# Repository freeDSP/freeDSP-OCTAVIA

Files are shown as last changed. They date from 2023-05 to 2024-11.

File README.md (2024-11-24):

# freeDSP-OCTAVIA
8ch Output ADAU1452/1466 DSP Board with Analog/COAX/OPT/USB/Raspberry-Pi Input

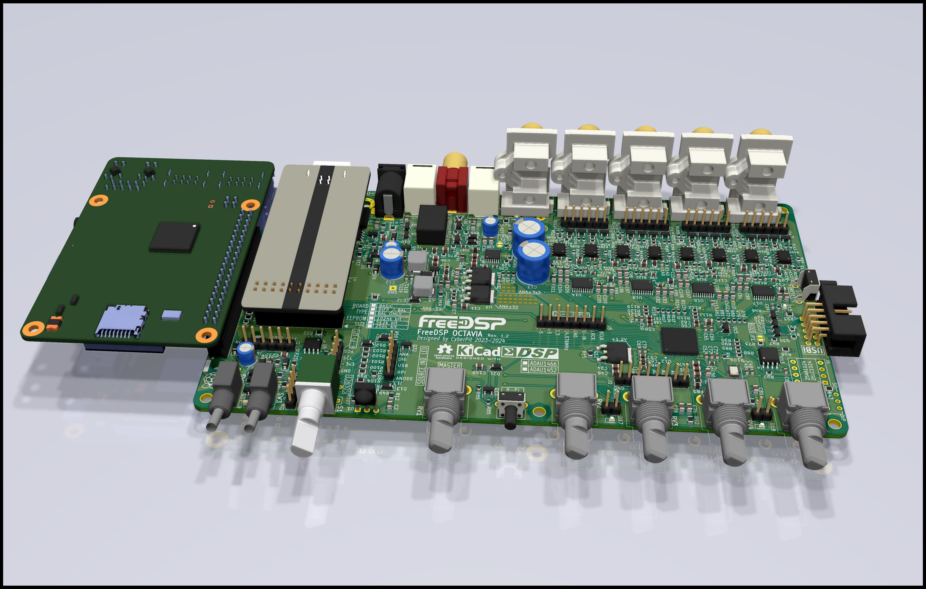
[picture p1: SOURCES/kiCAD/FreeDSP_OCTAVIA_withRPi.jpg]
Image of FreeDSP OCTAVIA


Version 1.2 is the latest commit.  
version 1.0 is evaluated and it worked.  
version 0.33j board requires some workarounds.  
version 0.33j_Fixed is a fixed design of 0.33j, But I recommend you build the latest version 1.2 or 1.1  
The errata information is detailed below...  
https://github.com/freeDSP/freeDSP-OCTAVIA/wiki/Errata-and-Workarounds

----
## Features:
* ADAU1452/1466 DSP for 2 in 8 out Audio Processing
* RCA-pin Analog Input
* Coaxial S/PDIF Input
* Optical S/PDIF Input
* Optical S/PDIF Output
* Optional Amanero Combo384 USB-Audio Interface Slot
* DSD mute protection for Amanero Combo384
* Optional Raspberry-Pi 40P Slot for I2S Audio Input  
(Raspberry-pi is optional, It is not necessary if you have a USBi for DSP programming)   
* Optional Raspberry-Pi I2C Connection to DSP
* On-board power supply for Raspberry Pi with shutdown control
* Restart/Shutdown button for Raspberry-Pi
* Independent Power switch for Raspberry-Pi
* Mains Power switch linked with Raspberry-Pi
* Common mode filtered Reverse voltage protection for Burrel DC Input
* IR Remote sensor for Raspberry-Pi
* R/G/B Power Status indicator LED
* Extra I2S Inpt header for external ADC(i.e. Phono) input source
* 8-channel RCA-pin Differential or Unbalanced Audio Output
* Balanced Output header for XLR output Connection
* 4 + 1(Master) Rotary Pots for AUX-ADC
* 4 steps + 1 mute level control Rotary switched Voltage Source for Input source selection
* LED source position indicator output header 
* I2C(0x70) connected USBi Interface with Bus-switch
* 2 LED indicators controlled by MP6 and MP7
* DSP Reset button
* Optional simple Unblanced RCA-pin output implementation capability

----
## LINKS:<br />
Wiki Page<br /> 
https://github.com/freeDSP/freeDSP-OCTAVIA/wiki

Discussion Forum:<br /> 
 https://www.diyaudio.com/community/threads/freedsp-octavia.393804/

Project Web-page:(Yandex Machine Translation)<br/>
 [Yandex Machine Translation](https://translated.turbopages.org/proxy_u/ja-en.en.1f823d34-64db980e-910d74e0-74722d776562/https/cyberpithilo.web.fc2.com/audio/FreeDSP_OCTAVIA/octavia_main.html)

Project Web-page:(Google Machine Translation)<br/>
[Google Machine Translation](https://cyberpithilo-web-fc2-com.translate.goog/audio/FreeDSP_OCTAVIA/octavia_main.html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)  <BR/>

Project Web-page:(Original Japanese Page)<br/>
 [https://cyberpithilo.web.fc2.com/audio/FreeDSP_OCTAVIA/octavia_main.html](https://cyberpithilo.web.fc2.com/audio/FreeDSP_OCTAVIA/octavia_main.html)

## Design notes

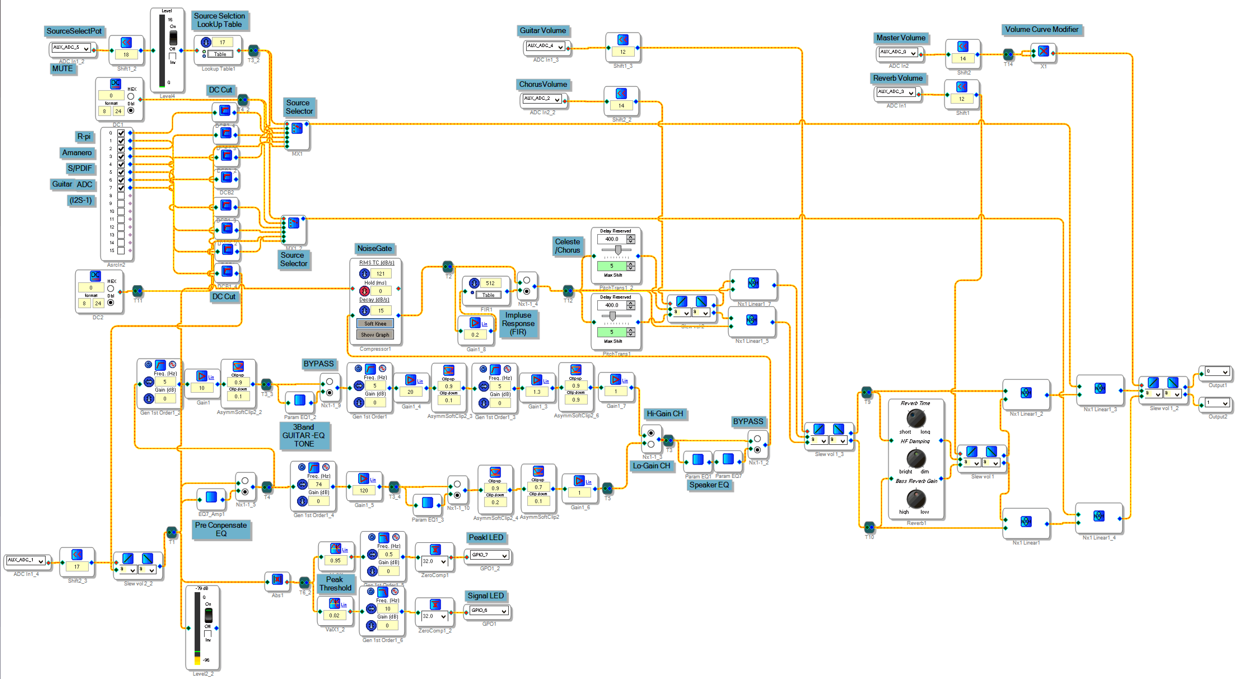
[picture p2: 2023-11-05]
SOURCES/Documents/Figures/GuitarPlayAlongSchematic.gif

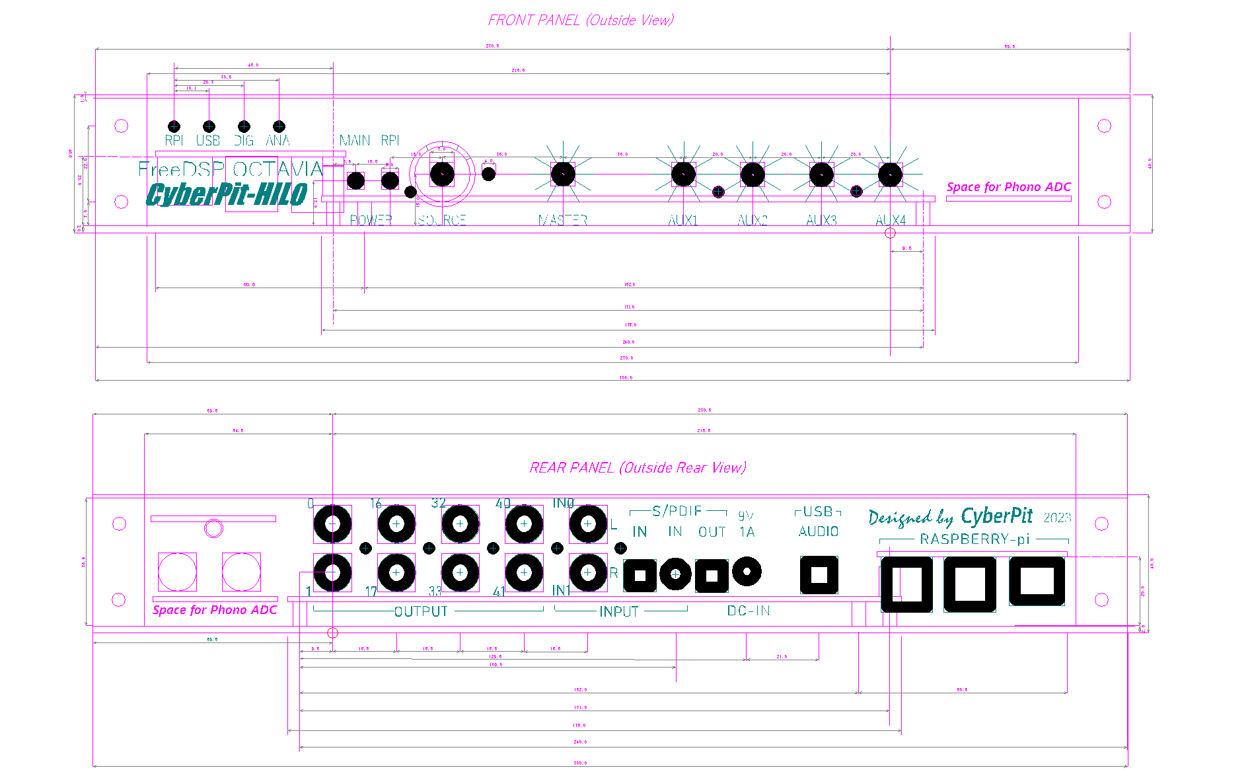
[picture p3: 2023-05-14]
SOURCES/Chassis/OCTAVIA_CNC-Panel_Design.gif

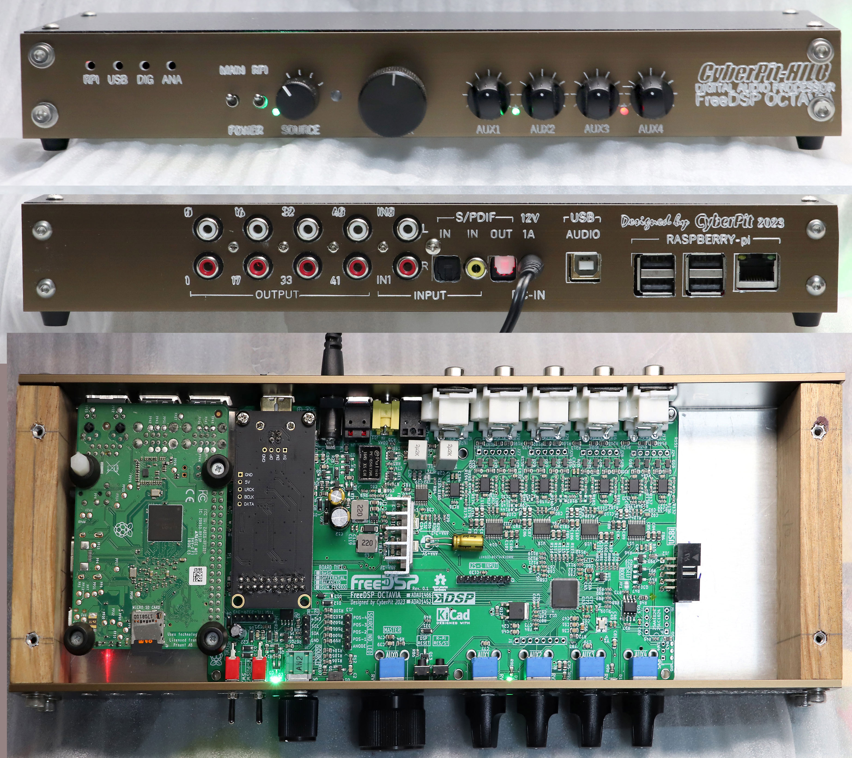
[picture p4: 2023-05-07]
SOURCES/Chassis/FreeDSP-OctaviaPhoto.jpg

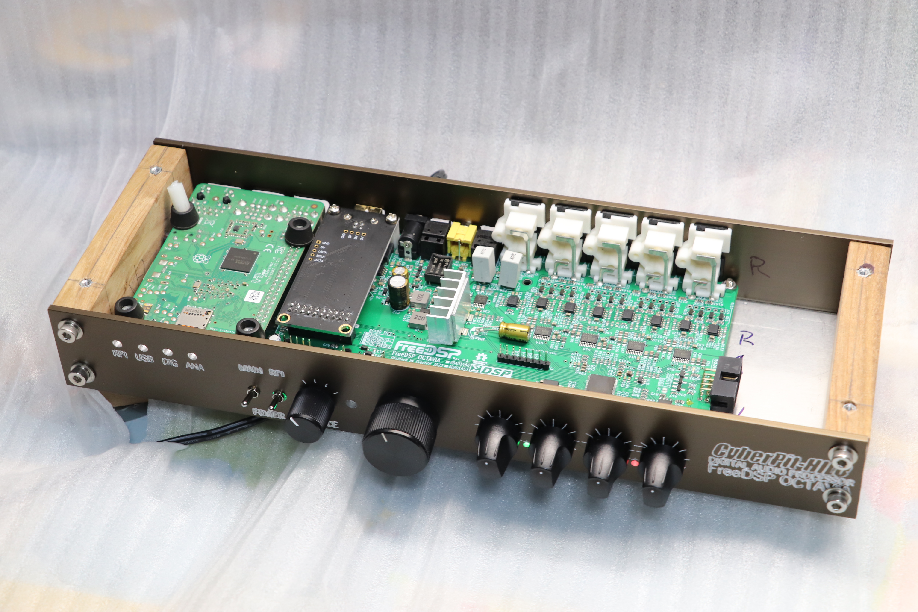
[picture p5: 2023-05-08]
SOURCES/Chassis/PaseInsideViewPhoto.JPG

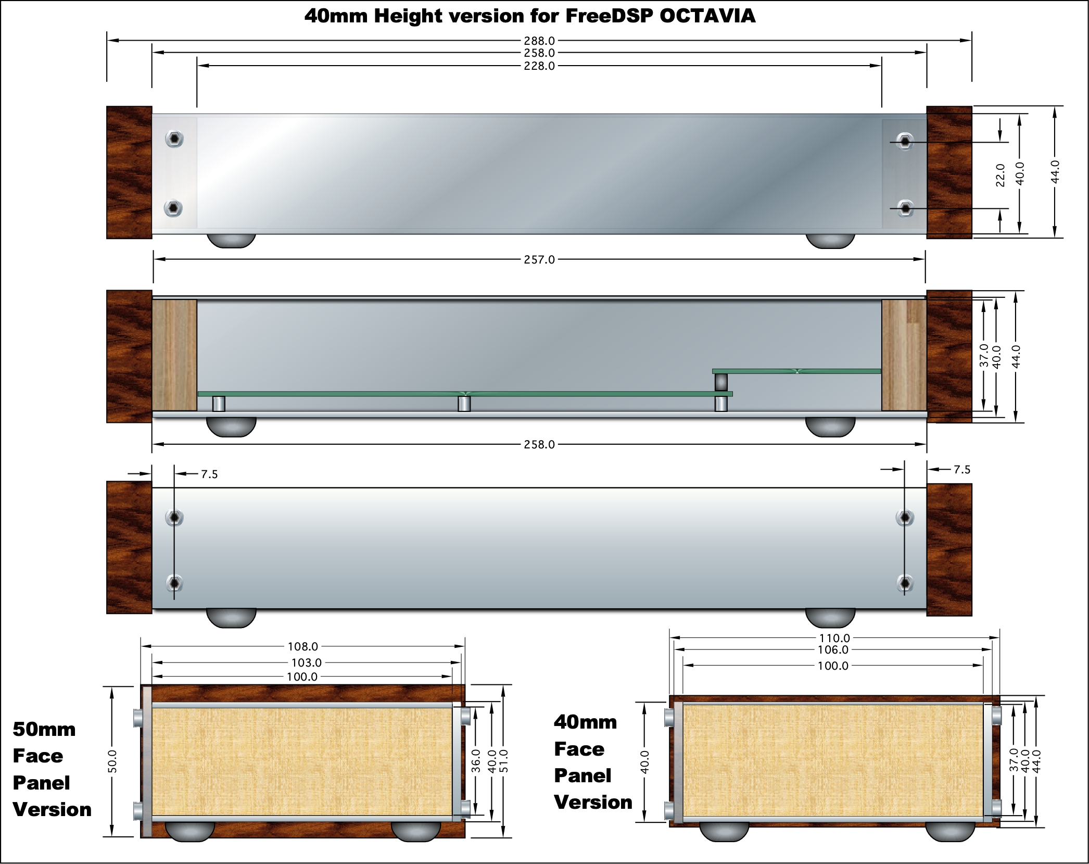
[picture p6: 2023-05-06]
SOURCES/Chassis/SideWoodCaseConcept.jpg

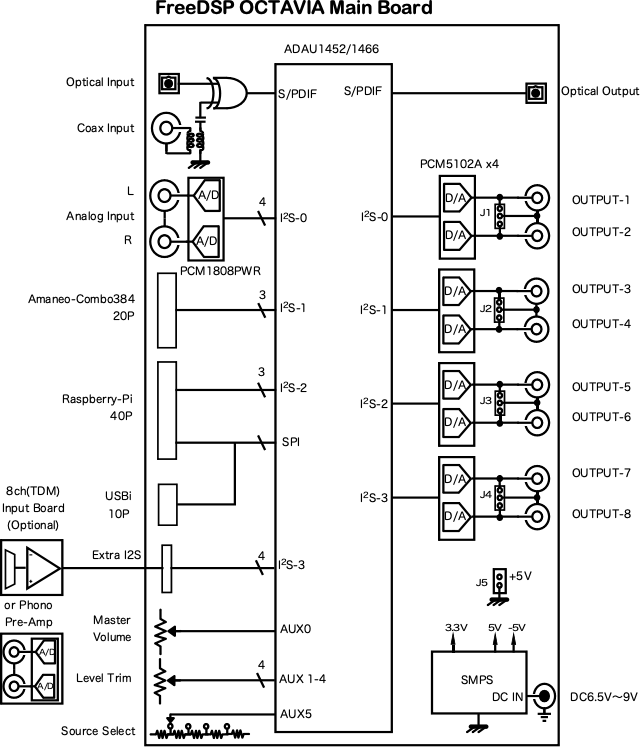
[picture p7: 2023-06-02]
SOURCES/Documents/Figures/FreeDSP OCTAVIA Unblanced-out Block Diagram2.gif

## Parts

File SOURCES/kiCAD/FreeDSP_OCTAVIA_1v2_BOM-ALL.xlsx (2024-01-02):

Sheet: PCBA
Reference | Quantity | Footprint | Description | Value | JLPCB# | Digi-Key_PN | MPN | Manufacturer | Datasheet
C166 | 1 | Capacitor_SMD:C_0402_1005Metric_Pad0.74x0.62mm_HandSolder |  | 2.2pF | C1559 |  |  |  | ~
C16 C32 C35 C49 C53 C55 C58 C59 C61 C63 C65 C68 C70 C72 C73 C74 C80 C139 C145 C149 C154 C159 C167 | 23 | Capacitor_SMD:C_0603_1608Metric |  | 0.1uF | C14663
C52 C54 C57 C62 C64 C67 C69 C71 C118 C119 | 10 | Capacitor_SMD:C_0603_1608Metric |  | 1uF | C15849 |  |  |  | ~
C120 | 1 | Capacitor_SMD:C_0603_1608Metric |  | 1000pF | C1588 |  |  |  | ~
C48 | 1 | Capacitor_SMD:C_0603_1608Metric |  | 10nF | C57112 |  |  |  | ~
C34 C50 C90 C91 C92 C93 C94 C95 C108 C109 C110 C111 C112 C113 C123 C124 C125 C126 C127 C128 C129 C130 C131 C132 C133 C134 C135 C136 C137 C138 C165 | 31 | Capacitor_SMD:C_0603_1608Metric |  | 10uF | C96446
C31 | 1 | Capacitor_SMD:C_0603_1608Metric_Pad1.08x0.95mm_HandSolder |  | 0.1uF | C14663
C100 | 1 | Capacitor_SMD:C_0805_2012Metric |  | 10uF | C440198 |  |  |  | ~
C101 | 1 | Capacitor_SMD:C_0805_2012Metric |  | 0.1uF | C49678 |  |  |  | ~
C3 | 1 | Capacitor_SMD:C_0805_2012Metric_Pad1.18x1.45mm_HandSolder |  | 0.01uF | C1710 |  |  |  | ~
C56 | 1 | Capacitor_SMD:C_0805_2012Metric_Pad1.18x1.45mm_HandSolder | PLL Loop FIlter Cap (C0G will better) | 150pF | C1716 |  |  |  | ~
C36 | 1 | Capacitor_SMD:C_0805_2012Metric_Pad1.18x1.45mm_HandSolder | PLL Loop FIlter Snabber Cap | 4700pF | C1744 |  |  |  | ~
C25 C26 C29 C30 | 4 | Capacitor_SMD:C_0805_2012Metric_Pad1.18x1.45mm_HandSolder | C0G or ECHU(FilmCap) Recommended | 100pF | C1790
C44 C141 C142 C143 | 4 | Capacitor_SMD:C_0805_2012Metric_Pad1.18x1.45mm_HandSolder |  | 1uF | C28323 |  |  |  | ~
C4 C6 C20 | 3 | Capacitor_SMD:C_0805_2012Metric_Pad1.18x1.45mm_HandSolder |  | 1uF/16V | C28323 |  |  |  | ~
C33 C60 C75 C76 C82 C84 C86 C88 C102 C104 C106 C168 | 12 | Capacitor_SMD:C_0805_2012Metric_Pad1.18x1.45mm_HandSolder |  | 10uF | C440198
C5 C21 C37 C38 C121 C122 | 6 | Capacitor_SMD:C_0805_2012Metric_Pad1.18x1.45mm_HandSolder |  | 10uF/16V | C440198 |  |  |  | ~
C15 C43 | 2 | Capacitor_SMD:C_0805_2012Metric_Pad1.18x1.45mm_HandSolder | for Negative SMPS Power Integration | 22uF/6.3V | C45783 |  |  |  | ~
C51 | 1 | Capacitor_SMD:C_0805_2012Metric_Pad1.18x1.45mm_HandSolder | PLL Loop FIlter Snabber Cap | 1nF | C46653 |  |  |  | ~
C1 C2 C7 C9 C10 C11 C14 C17 C18 C19 C24 C39 C40 C41 C42 C45 C46 C47 C77 C78 C79 C81 C83 C85 C87 C89 C103 C105 C107 C140 | 30 | Capacitor_SMD:C_0805_2012Metric_Pad1.18x1.45mm_HandSolder |  | 0.1uF | C49678 |  |  |  | ~
C144 C146 C150 C151 C157 C158 C160 C161 | 8 | Capacitor_SMD:C_0805_2012Metric_Pad1.18x1.45mm_HandSolder | Better Use Audio-Grade or Film Cap (ie. PML, ECHU, etc..) | 470pF(C0G) | C525291 |  |  |  | ~
C96 C97 C98 C99 C114 C115 C116 C117 | 8 | Capacitor_SMD:C_0805_2012Metric_Pad1.18x1.45mm_HandSolder | Better Use Audio-Grade or Film Cap (ie. PML, ECHU, etc..) | 4.7nF(C0G) | C880299 |  |  |  | ~
C23 | 1 | Capacitors_SMD:C_0805 | Time-Constant Cap for RPI delay-ON | 1uF/50V | C28323 |  |  |  | ~
Y1 | 1 | Crystals:Crystal_SMD_TXC_7M-4pin_3.2x2.5mm_HandSoldering | 24.576MHz or 22.5792MHz TCXO 1.6 to 3.63 Volts | OT322524.576MJBA4S | C2831388 |  |  |  | http://www.kyocera.co.jp/prdct/electro/pdf/clock_k_j.pdf
FB1 FB3 FB4 FB13 | 4 | Bead:0805 | Bead for Analog -VEE rail | GZ2012D601TF | C1017 | 490-1014-1-ND | BLM18AG601SN1D | Murata Electronics North America | https://www.murata.com/en-us/products/productdata/8796738650142/ENFA0003.pdf
D20 | 1 | Diode_SMD:D_SMA |  | D_Schottky_1A | C22452 |  |  |  | ~
D14 D16 | 2 | Diode_SMD:D_SMA | SBD 40V 550mV@5A | D_Schottky_5A | C22452 |  |  |  | ~
D1 D2 D4 D5 D6 D7 D8 D11 D12 D13 D21 D22 D23 | 13 | Diode_SMD:D_SOD-123 | Si Switching Diode | 1N4148W | C81598
D9 D10 D24 D25 | 4 | Diode_SMD:D_SOD-123 | SBD for charging C32 | SS2040FL | C8598 |  |  |  | http://www.vishay.com/docs/85660/bat42.pdf
FB2 | 1 | Inductor_SMD:L_0805_2012Metric | FERRITE BEAD 600 OHM 0603 1LN | GZ2012D601TF | C1017 | 490-1014-1-ND | BLM18AG601SN1D | Murata Electronics North America | https://www.murata.com/en-us/products/productdata/8796738650142/ENFA0003.pdf
FB5 FB6 FB7 FB8 FB9 FB10 FB11 FB12 | 8 | Inductor_SMD:L_0805_2012Metric_Pad1.15x1.40mm_HandSolder | Filter for DAC Power Rail | GZ2012D601TF | C1017 |  |  |  | ~
L1 | 1 | Inductor_SMD:L_0805_2012Metric_Pad1.15x1.40mm_HandSolder | FIXED IND 22UH 5MA 1.1 OHM | SDFL2012T220KTF | C32375 | 811-2477-1-ND | 82473C | Sunlord | https://www.murata-ps.com/data/magnetics/kmp_8200c.pdf
L2 L4 L5 | 3 | Inductor_SMD:L_Taiyo-Yuden_NR-60xx_HandSoldering | Metal-Alloy Power Inductor | 22uH(2A) | C128694
L3 | 1 | Inductor_SMD:L_Taiyo-Yuden_NR-60xx_HandSoldering | Metal-Alloy Power Inductor | 22uH(3A) | C128694
D18 | 1 | LED_SMD:LED_0603_1608Metric_Castellated | Remove this if you use LED extension header | LED_RED | C2286
D15 | 1 | LED_SMD:LED_0603_1608Metric_Castellated | Indicator for USBi is Active | LED_YELLOW | C72038
D19 | 1 | LED_SMD:LED_0603_1608Metric_Castellated | Just for check the PC VBUS status | LED_BLUE | C72041
D17 | 1 | LED_SMD:LED_0603_1608Metric_Castellated | Remove this if you use LED extension header | LED_GRN | C72043
U12 | 1 | LFCSP-72-1EP_10x10mm_P0.5mm_EP5.3x5.3mmL_HandSolder | SigmaDSP | ADAU1452 | C654402
IC2 | 1 | PCM1808QPWRQ1 | ADC 99dB SNR is only available @48kHz Sampling | PCM1808QPWRQ1 | C55513 |  |  |  | http://www.ti.com/lit/ds/symlink/pcm1808-q1.pdf
U20 U21 U22 U23 U24 U25 U26 U27 | 8 | SOIC127P600X175-8N | for Balanced/Differential Output driver | OPA1632DR | C86715
D3 | 1 | LED_0603_ABGR | Remove this if you use the Power Status LED extension header | LED_ABGR | C965848 |  |  |  | ~
FL1 | 1 | ACM9070F | Common mode choke for mains | ACM9070 | C908578 |  |  |  | ~
U6 | 1 | Package_SO:SOIC-8_3.9x4.9mm_P1.27mm | Timing Controller for RPI PSU | LMC555CMX | C90760 |  |  |  | http://www.ti.com/lit/ds/symlink/lmc555.pdf
U13 | 1 | Package_SO:SOIC-8_5.275x5.275mm_P1.27mm | Might be substitute with 256Mbit/512Mbit SPI EEPROM | 25AA1024 | C157455 |  |  |  | http://ww1.microchip.com/downloads/en/DeviceDoc/21832H.pdf
IC1 U5 | 2 | Package_SO:TI_SO-PowerPAD-8_ThermalVias | SMPS for digital part | TPS5430DDA | C9864 |  |  |  | http://www.ti.com/lit/ds/symlink/tps5430.pdf
U14 U16 U17 U18 | 4 | Package_SO:TSSOP-20_4.4x6.5mm_P0.65mm | 32bit Audio DAC | PCM5102A | C107671 |  |  |  | http://www.ti.com/lit/ds/symlink/pcm5102.pdf
Q10 Q11 Q15 Q16 Q17 Q18 Q19 Q20 Q21 Q22 Q23 Q24 Q25 Q26 Q27 Q28 | 16 | Package_TO_SOT_SMD:SOT-23 | alt. 2SC4213 or 2SD2704 (Audio Muting) | 2SC3326 | C27829 |  |  |  | ~
Q1 Q5 Q7 Q29 | 4 | Package_TO_SOT_SMD:SOT-23_Handsoldering | P-CHANNEL ENHANCEMENT MODE MOSFET | AO3401A | C15127 |  |  |  | http://docs-emea.rs-online.com/webdocs/104e/0900766b8104e4f0.pdf
Q2 Q4 | 2 | Package_TO_SOT_SMD:SOT-23_Handsoldering | PNP Transistor for anti-pop muting | MMBT5401 | C8326 |  |  |  | ~
Q3 Q6 Q8 Q9 Q13 Q30 Q31 Q32 | 8 | Package_TO_SOT_SMD:SOT-23_Handsoldering | N-CHANNEL ENHANCEMENT MODE MOSFET | 2N7002 | C8545 |  |  |  | https://www.fairchildsemi.com/datasheets/2N/2N7002.pdf
U8 | 1 | Package_TO_SOT_SMD:SOT-23-5 | Negativer 3MHz SMPS | LM2611AMFX | C2072505 |  |  |  | https://www.ti.com/lit/ds/symlink/lm2611.pdf
U11 U15 | 2 | Package_TO_SOT_SMD:SOT-23-5_HandSoldering | for Coax S/PDIF Input Amp | 74LVC1G04 | C434067 |  |  |  | http://www.ti.com/lit/sg/scyt129e/scyt129e.pdf
U10 | 1 | Package_TO_SOT_SMD:SOT-23-5_HandSoldering | EXOR for Maerge S/PDIF Signals | 74LVC1G86 | C73458 |  |  |  | http://www.ti.com/lit/sg/scyt129e/scyt129e.pdf
Q12 | 1 | Package_TO_SOT_SMD:TO-252-2 | PNP Transistor for 1.2V Power Rail | MJD45H11T4 | C138783 |  |  |  | ~
U3 U7 | 2 | Package_TO_SOT_SMD:TO-252-2 | Voltage Regurator for Analog | LM317AG-TN3-R | C75510 |  |  |  | https://datasheet.lcsc.com/lcsc/2304140030_UTC-Unisonic-Tech-LM317AG-TN3-R_C75510.pdf
R38 R53 R61 R138 R186 R196 | 6 | Resistor_SMD:R_0603_1608Metric | Tightly Connecting Jumper for AnalogGND and Digital GND | 0R | C21189 |  |  |  | ~
R73 R83 | 2 | Resistor_SMD:R_0603_1608Metric |  | 1k | C21190 |  |  |  | ~
R132 R134 R140 R142 R173 R175 R181 R183 | 8 | Resistor_SMD:R_0603_1608Metric |  | 1.1k | C22764 |  |  |  | ~
R76 | 1 | Resistor_SMD:R_0603_1608Metric |  | 1.2k | C22765 |  |  |  | ~
R56 | 1 | Resistor_SMD:R_0603_1608Metric |  | 100R | C22775 |  |  |  | ~
R57 | 1 | Resistor_SMD:R_0603_1608Metric |  | 120R | C22787 |  |  |  | ~
R69 R75 | 2 | Resistor_SMD:R_0603_1608Metric |  | 150R | C22808 |  |  |  | ~
R31 R52 R60 R144 R145 R151 R153 R177 R184 R185 | 10 | Resistor_SMD:R_0603_1608Metric |  | 10R | C22859 |  |  |  | ~
R152 R154 R155 R156 R159 R160 R161 R162 R192 R193 R194 R195 R198 R201 R203 R204 | 16 | Resistor_SMD:R_0603_1608Metric |  | 220R | C22962 |  |  |  | ~
R84 | 1 | Resistor_SMD:R_0603_1608Metric |  | 3.3k | C22978 |  |  |  | ~
R130 | 1 | Resistor_SMD:R_0603_1608Metric |  | 29.4k | C22984
R58 | 1 | Resistor_SMD:R_0603_1608Metric |  | 330R | C23138 |  |  |  | ~
R41 R77 R78 R79 R80 R81 R82 R88 R89 R90 R95 R110 R111 R112 R113 R114 R115 R116 R117 R118 R119 R120 R121 | 23 | Resistor_SMD:R_0603_1608Metric |  | 33R | C23140 |  |  |  | ~
R122 R123 R124 R125 R126 R127 R128 R129 | 8 | Resistor_SMD:R_0603_1608Metric |  | 470R | C23179 |  |  |  | ~
R1 R3 R4 R28 R29 R30 R39 R55 R87 R109 | 10 | Resistor_SMD:R_0603_1608Metric |  | 47R | C23182 |  |  |  | ~
R74 | 1 | Resistor_SMD:R_0603_1608Metric |  | 100k | C25803 |  |  |  | ~
R45 R46 R47 R49 R85 R97 R131 R163 R164 R165 R166 R167 R168 R169 R170 R202 R205 R206 R207 R208 R209 R210 R211 | 23 | Resistor_SMD:R_0603_1608Metric |  | 10k | C25804
R44 R62 R63 R67 R68 R86 R91 R133 R135 R137 R139 R141 R146 R148 R150 R174 R176 R178 R180 R182 R187 R189 R191 | 23 | Resistor_SMD:R_0603_1608Metric |  | 2.2k | C4190 |  |  |  | ~
R59 | 1 | Resistor_SMD:R_0603_1608Metric |  | 200R | C8218 |  |  |  | ~
R5 R16 R20 R23 R35 R36 R37 R51 R54 | 9 | Resistor_SMD:R_0805_2012Metric_Pad1.20x1.40mm_HandSolder |  | 100k | C149504
R92 R94 | 2 | Resistor_SMD:R_0805_2012Metric_Pad1.20x1.40mm_HandSolder |  | 100R | C17408 |  |  |  | ~
R2 R18 R32 R34 R50 R64 R108 | 7 | Resistor_SMD:R_0805_2012Metric_Pad1.20x1.40mm_HandSolder |  | 10k | C17414 |  |  |  | ~
R43 R48 | 2 | Resistor_SMD:R_0805_2012Metric_Pad1.20x1.40mm_HandSolder | Remove this when Using SW4 | 0R | C17477 |  |  |  | ~
R24 R25 | 2 | Resistor_SMD:R_0805_2012Metric_Pad1.20x1.40mm_HandSolder |  | 18k | C17506
R19 R42 R65 R93 R96 R98 R99 R100 R101 R102 R103 R104 R105 R106 R107 | 15 | Resistor_SMD:R_0805_2012Metric_Pad1.20x1.40mm_HandSolder |  | 1k | C17513
R21 R22 | 2 | Resistor_SMD:R_0805_2012Metric_Pad1.20x1.40mm_HandSolder |  | 1MEG | C17514
R26 R27 | 2 | Resistor_SMD:R_0805_2012Metric_Pad1.20x1.40mm_HandSolder |  | 27k | C17593
R14 R17 | 2 | Resistor_SMD:R_0805_2012Metric_Pad1.20x1.40mm_HandSolder |  | 3.24k | C17609
R6 | 1 | Resistor_SMD:R_0805_2012Metric_Pad1.20x1.40mm_HandSolder |  | 330R | C17630
R72 | 1 | Resistor_SMD:R_0805_2012Metric_Pad1.20x1.40mm_HandSolder |  | 4.3k | C17667 |  |  |  | ~
R15 | 1 | Resistor_SMD:R_0805_2012Metric_Pad1.20x1.40mm_HandSolder |  | 470K | C17709
R8 R11 R12 | 3 | Resistor_SMD:R_0805_2012Metric_Pad1.20x1.40mm_HandSolder |  | 47R | C17714 |  |  |  | ~
R7 R33 R71 | 3 | Resistor_SMD:R_0805_2012Metric_Pad1.20x1.40mm_HandSolder |  | 3.3k | C26010 |  |  |  | ~
R13 | 1 | Resistor_SMD:R_0805_2012Metric_Pad1.20x1.40mm_HandSolder |  | 5.6k | C4382

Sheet: Hand
Reference | Quantity | Footprint | Description | Value | JLPCB# | Digi-Key_PN | MPN | Manufacturer | Datasheet
A1 | 1 | MyLibrary:Combo384 | Amanero or Compatible USB to I2S I/F Board Slot | IDC_Socket_2x10 | HAND
C12 | 1 | Capacitor_THT:CP_Radial_D7.5mm_P2.50mm | for the Power-OFF muting power keep | 220uF/16V | HAND |  |  |  | ~
C13 C164 | 2 | Capacitor_THT:CP_Radial_D10.0mm_P2.50mm_P5.00mm | for Analog +5V decoupling, Solid-Cap recommended | 220uF/6.3V | HAND |  |  |  | ~
C22 | 1 | Capacitor_THT:CP_Radial_D5.0mm_P2.00mm | Time-Constant Cap for RPI delay-Shutdown | 33uF/16V | HAND |  |  |  | ~
C27 C28 | 2 | Capacitor_THT:CP_Radial_D5.0mm_P2.00mm | Audio Grade Ele-Cap or WIMA Recommended | 2.2uF | HAND
C8 | 1 | Capacitor_THT:CP_Radial_D5.0mm_P2.00mm | for the Power-ON delay timing | 22uF/16V | HAND |  |  |  | ~
J11 | 1 | MyJacks:RJ-2410N | RCA-pin Input Connector(Yellow)CUI RCJ-044 | Conn_Coaxial | HAND |  |  |  | ~
J12 | 1 | Connector_IDC:IDC-Header_2x05_P2.54mm_Horizontal | Angled 10pin IDC header for USBi | IDC_Header 2x5 | HAND
J2 | 1 | Connector_BarrelJack:BarrelJack_Horizontal | for 2.1mm wall Power Supply (DC6.5V to 9V) | Barrel DC Input Jack 5.5mm | HAND |  |  |  | ~
J5 J16 J17 J20 J21 | 5 | MyJacks:RCJ-2223 | Vertical Stereo RCA-pin Jack (Upper=Right, Lower=Left) RCJ-2223 | RCJ-2223 | HAND |  |  |  | ~
P1 | 1 | Connector_PinSocket_2.54mm:PinSocket_2x20_P2.54mm_Vertical | for Rapberry-pi Slot | Conn Female_02x20_Odd_Even | HAND
RV1 RV2 RV3 RV4 RV5 | 5 | Myfootprints:RK09L12B0A31 | Potentiometer for AUX Voltage Control | B10K | HAND
S1 | 1 | Myfootprints:SR10010F020420F0BC7N0027 | Rotary Switches 2 POLE 4 POS D SHAFT | SR10010F-0204-20F0B-C7-N-0027_ALT | HAND |  |  |  | https://componentsearchengine.com/Datasheets/1/SR10010F-0204-20F0B-C7-N-0027.pdf
SW1 | 1 | Button_Switch_THT:SW_Tactile_SPST_Angled_PTS645Vx83-2LFS | RPI Shutdown/Reboot switch | Tacktical Push Swithch Angled | HAND
SW2 SW3 | 2 | Myfootprints:2MS1T1B4M7QES | Mains Power Switch C&K 200MSP1T2B2M7RE, T105MH9AVBE | Toggle SW_SPDT | HAND
SW7 | 1 | Button_Switch_THT:SW_Tactile_SPST_Angled_PTS645Vx83-2LFS | for manual reset button for DSP | Tacktical Push Swithch Angled | HAND
T1 | 1 | MyLibrary:PE65612NL | S/PDIF Transformer THT Digital-Audio 2500uH 1-Port | PE-65612NL | HAND |  |  |  | https://componentsearchengine.com/Datasheets/1/PE-65612NL.pdf
U1 | 1 | digikey-footprints:IR_Receiver_TSOP38238 | Optional: IR REMOTE SENSOR Vishay TSOP38238 38.0KHZ 45M | GP1UXC41QS | HAND | 751-1227-ND | TSOP38238 | Vishay Semiconductor Opto Division | http://www.vishay.com/docs/82491/tsop382.pdf
U2 | 1 | MyLibrary:PLR135-T10 | Optical S/PDIF RX (max. 16Mbps) | PLR135-T10 | HAND
U4 | 1 | MyLibrary:PLT133-T10W | Optical S/PDIF TX (max. 16Mbps) | PLT133-T10W | HAND
J9 J10 | 2 | Connector_PinHeader_2.54mm:PinHeader_1x02_P2.54mm_Vertical | Optional for the Extended LED Connection | Conn_01x02 | OPTION |  |  |  | ~
J1 J3 | 2 | Connector_PinHeader_2.54mm:PinHeader_1x08_P2.54mm_Vertical | Optional for the I2S-1 Input | Conn_01x08 | OPTION |  |  |  | ~
J13 | 1 | Connector_PinHeader_2.54mm:PinHeader_1x05_P2.54mm_Vertical | Optional for the Source Position LED Indicator | Conn_01x05 | OPTION |  |  |  | ~
J24 J25 J27 J28 | 4 | Connector_PinHeader_2.54mm:PinHeader_1x06_P2.54mm_Vertical | Optional for the XLR-Balanced Output | Conn_01x06 | OPTION |  |  |  | ~
J4 | 1 | Connector_PinHeader_2.54mm:PinHeader_1x06_P2.54mm_Vertical | Optional TTL-232R-3V3 Serial Cable Header for Raspberry-pi | Header_01x06 | OPTION |  |  |  | ~
J7 J8 | 2 | Connector_PinHeader_2.54mm:PinHeader_1x04_P2.54mm_Vertical | Optional I2C OLED Display Connection for Raspberry-pi | Header_01x04 | OPTION |  |  |  | ~

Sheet: NO POP
Reference | Quantity | Footprint | Description | Value | JLPCB# | Digi-Key_PN | MPN | Manufacturer | Datasheet
C66 | 1 | Capacitor_SMD:C_0805_2012Metric_Pad1.18x1.45mm_HandSolder | Prepared for just in case | NOP |  |  |  |  | ~
C141 C142 C143 | 1 | Capacitor_SMD:C_0805_2012Metric_Pad1.18x1.45mm_HandSolder | Not Necessary, Prepared for just in case | 0.1uF |  |  |  |  | ~
R40 | 1 | Resistor_SMD:R_0603_1608Metric | Selectable Exclusive Mount Jumper for RESET by RPI feature | NOP |  |  |  |  | ~
R9 R10 | 2 | Resistor_SMD:R_0805_2012Metric_Pad1.20x1.40mm_HandSolder | Selectable Exclusive Mount Shutdown Detect Jumper R | NOP |  |  |  |  | ~
R10 | 2 | Resistor_SMD:R_0805_2012Metric_Pad1.20x1.40mm_HandSolder | Selectable Exclusive Mount IR-Remote Sensor Jumper R | NOP |  |  |  |  | ~
R66 R70 R136 R143 R147 R149 R157 R158 | 8 | Resistors_SMD:R_0603_HandSoldering | Prepare 220R resistor for the Sratdard Version. | 220R |  |  |  |  | ~
R171 R172 R212 R213 | 4 | Resistor_SMD:R_0603_1608Metric_Pad0.98x0.95mm_HandSolder | Prepare 0R Jumper for the Sratdard Version. | 0R |  |  |  |  | ~
J6 | 1 | Package_DIP:DIP-8_W7.62mm_Socket | Optional Sockt for substitute package of SPI-EEPROM | 8P_DIP_SOCKET |  |  |  |  | ~
SW4 | 1 | Buttons_Switches_ThroughHole:SW_CuK_JS202011AQN_DPDT_Angled | Optional Program EEPROM A/B Select switch | SW_NOP_DPDT |  |  |  |  | ~

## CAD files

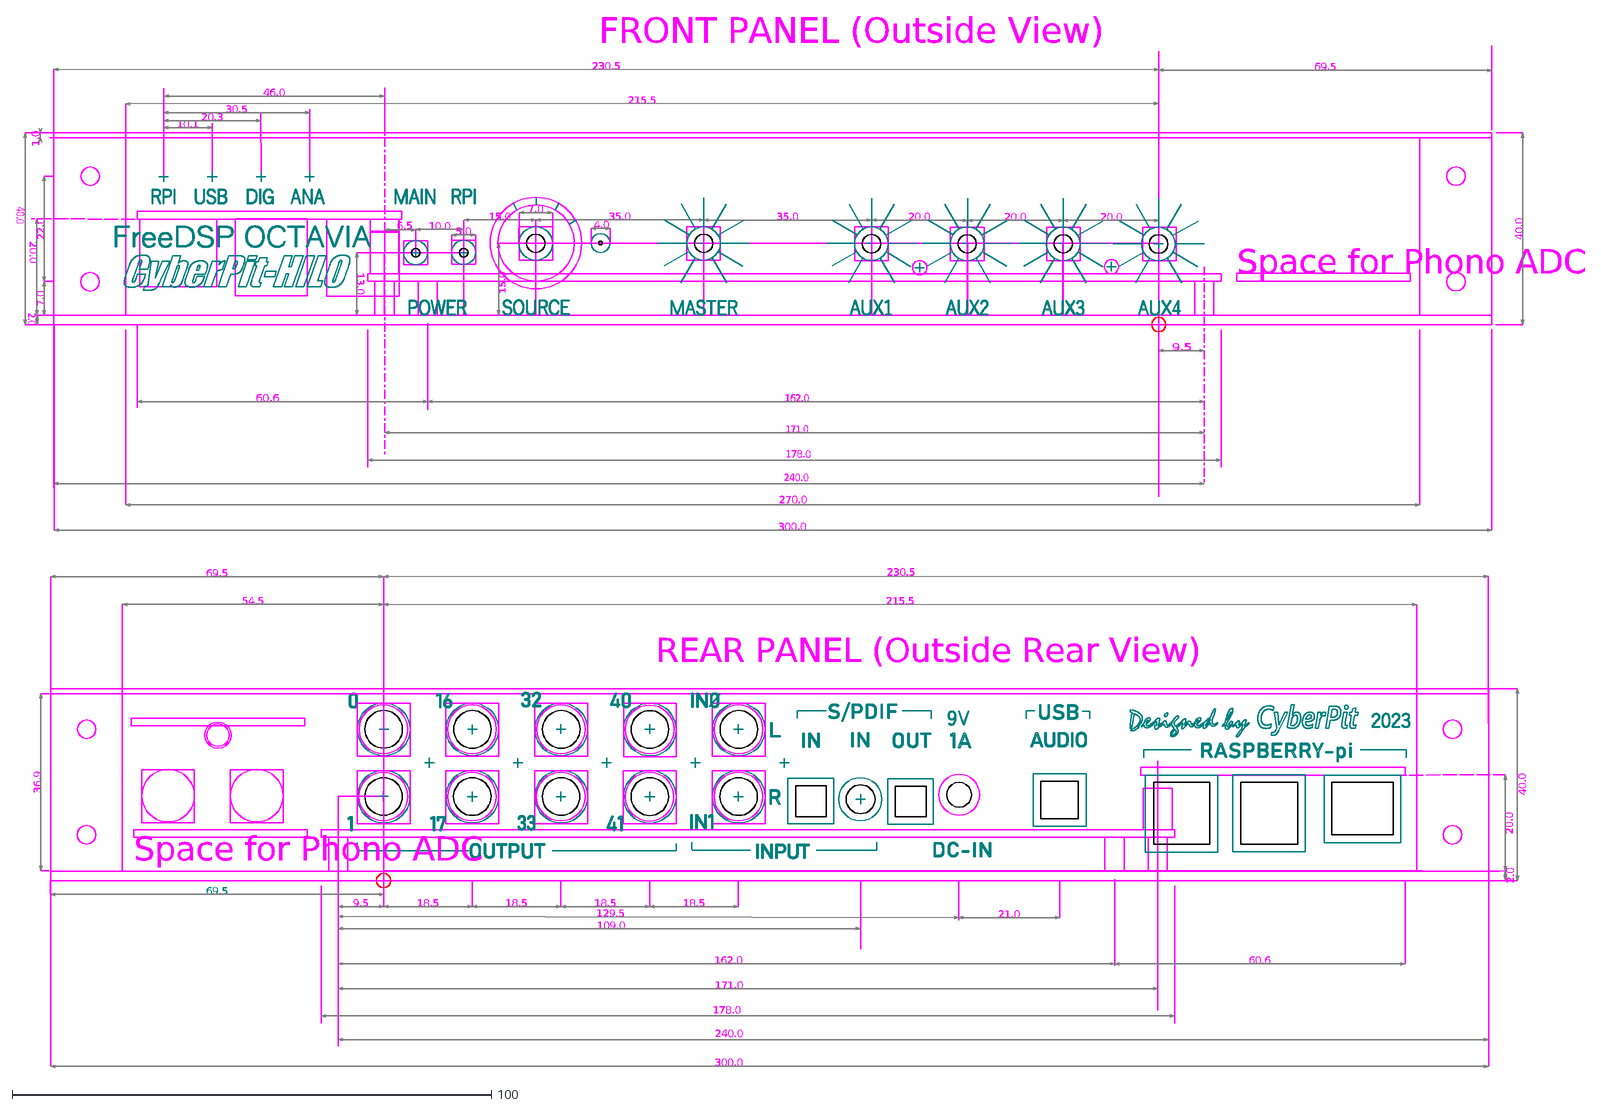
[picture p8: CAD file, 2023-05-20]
SOURCES/Chassis/OCTAVIA_CNC-Panel_Design.DXF
240.0
40.0
2.0
162.0
178.0
171.0
60.6
20.0
9.5
13.0
35.0
10.0
6.5
15.0
7.0
5.0
4.0
1.0
FRONT PANEL (Outside View)
270.0
300.0
69.5
215.5
230.5
Space for Phono ADC
10.1
20.3
30.5
46.0
22.0
REAR PANEL (Outside Rear View)
36.9
109.0
129.5
18.5
54.5
21.0

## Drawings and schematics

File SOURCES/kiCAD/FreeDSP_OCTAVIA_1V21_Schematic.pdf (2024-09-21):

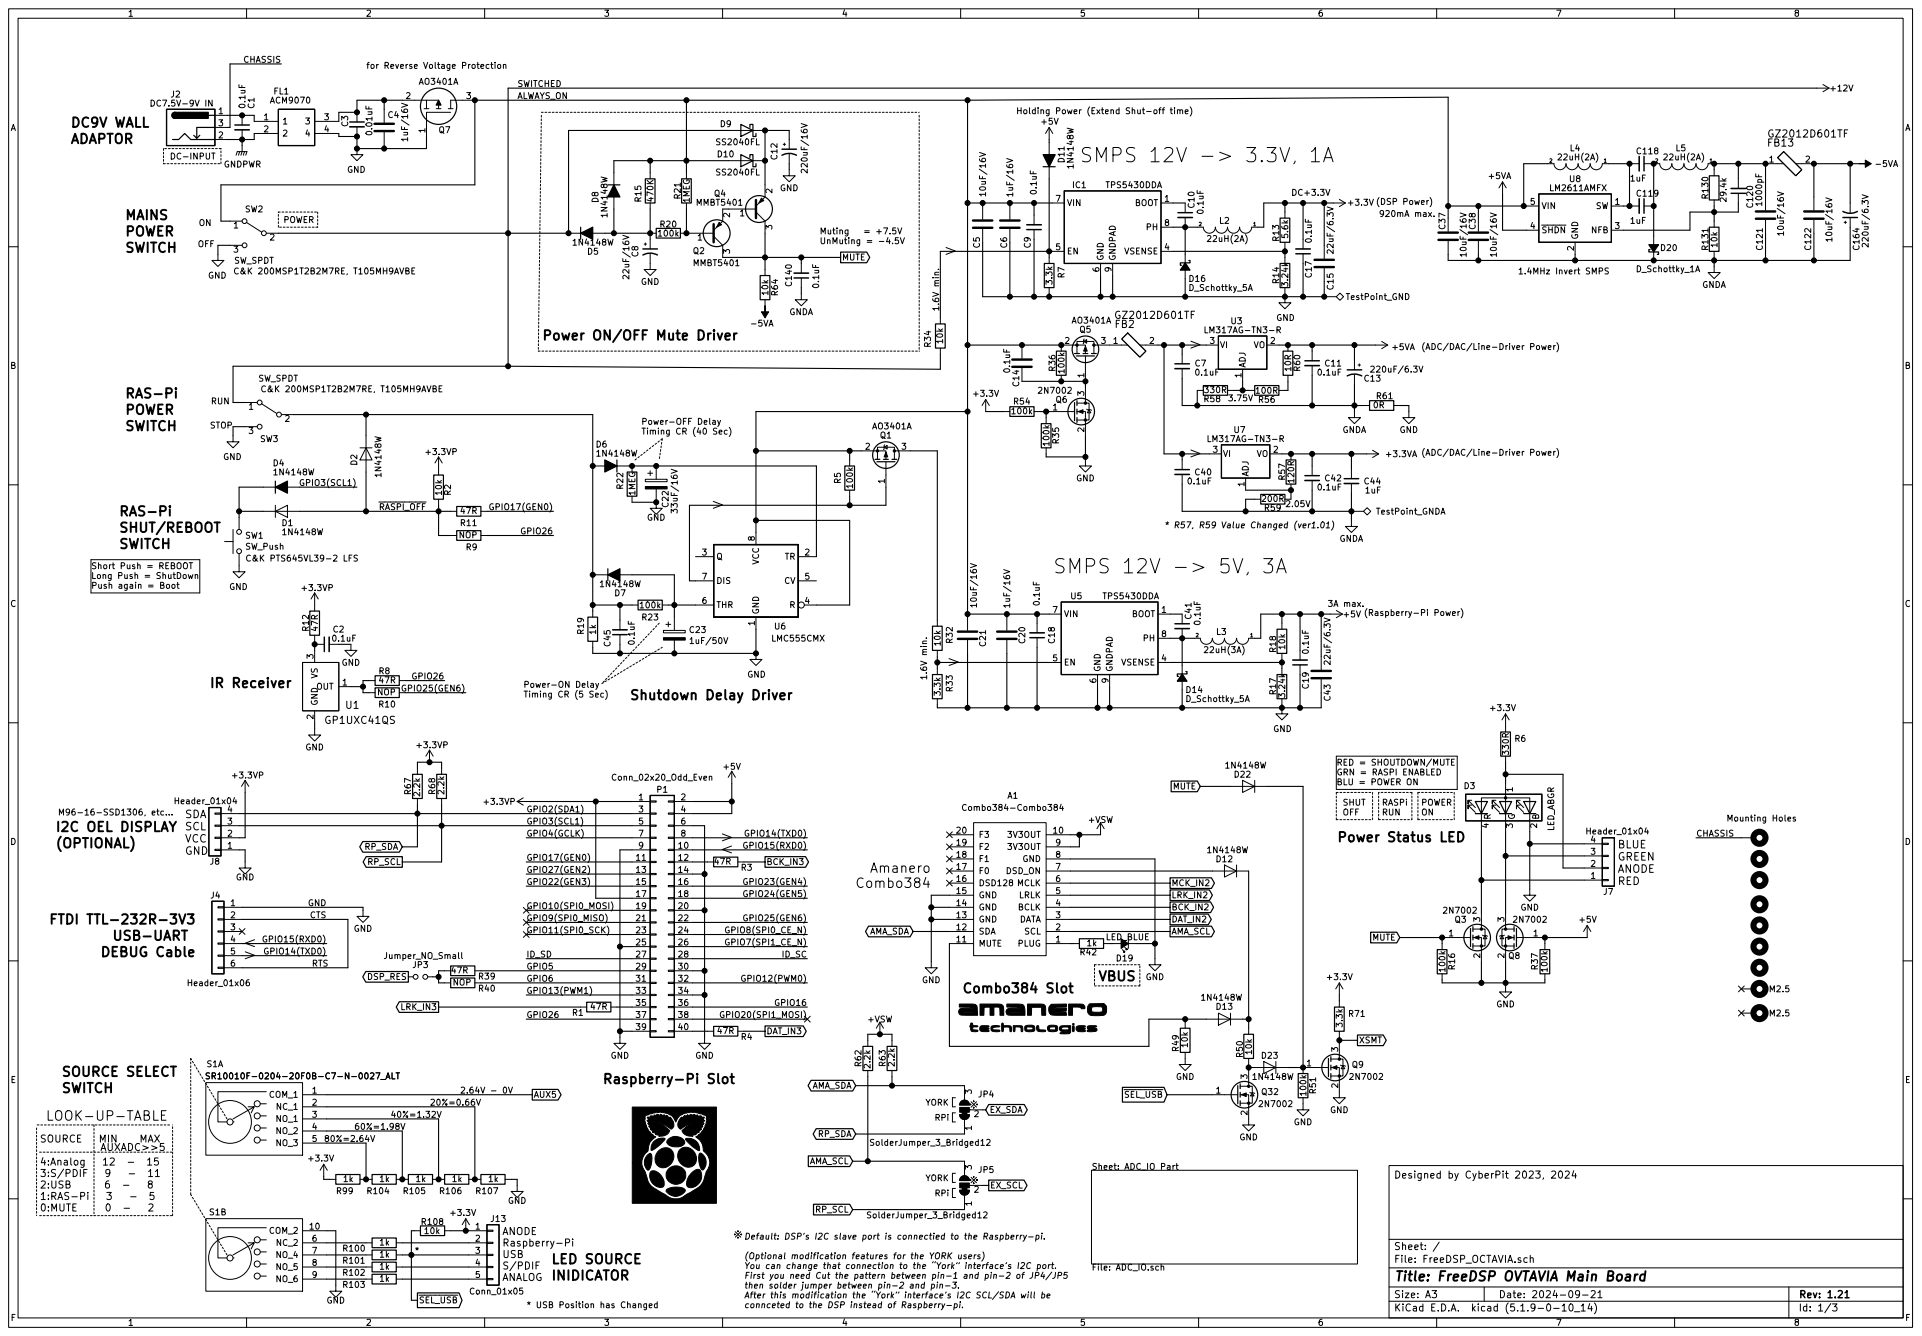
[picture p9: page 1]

for Reverse Voltage Protection

Holding Power (Extend Shut-off time)
DC+3.3V SMPS 12V -> 3.3V, 1A

(ADC/DAC/Line-Driver Power) DC-INPUT

2 Q2 3 MMBT5401 +3.3VA GNDA ADJ 1 VO 2 VI 3 U7

9 U5 TPS5430DDA C21 10uF/16V C41 0.1uF R17 3.24k R18 10k GND ADJ 1 VO 2 VI 3 U3

Power ON/OFF Mute Driver

(ADC/DAC/Line-Driver Power)

SHUT OFF Short Push = REBOOT
Long Push = ShutDown
Push again = Boot

Timing CR (5 Sec) SOURCE MIN MAX

RED = SHOUTDOWN/MUTE GRN = RASPI ENABLED

RASPi RUN | POWER ON

3 | GPIO3(SCL1)

15 | 16 18 20
17

Default: DSPs I2C slave port is connectied to the Raspberry-pi.

(Optional modification features for the YORK users)
You can change that connection to the York interfaces I2C port.
First you need Cut the pattern between pin-1 and pin-2 of JP4/JP5
then solder jumper between pin-2 and pin-3. After this modification the York interfaces I2C SCL/SDA will be connceted to the DSP instead of Raspberry-pi.

Id: 1/3 Title: FreeDSP OVTAVIA Main Board

* USB Position has Changed

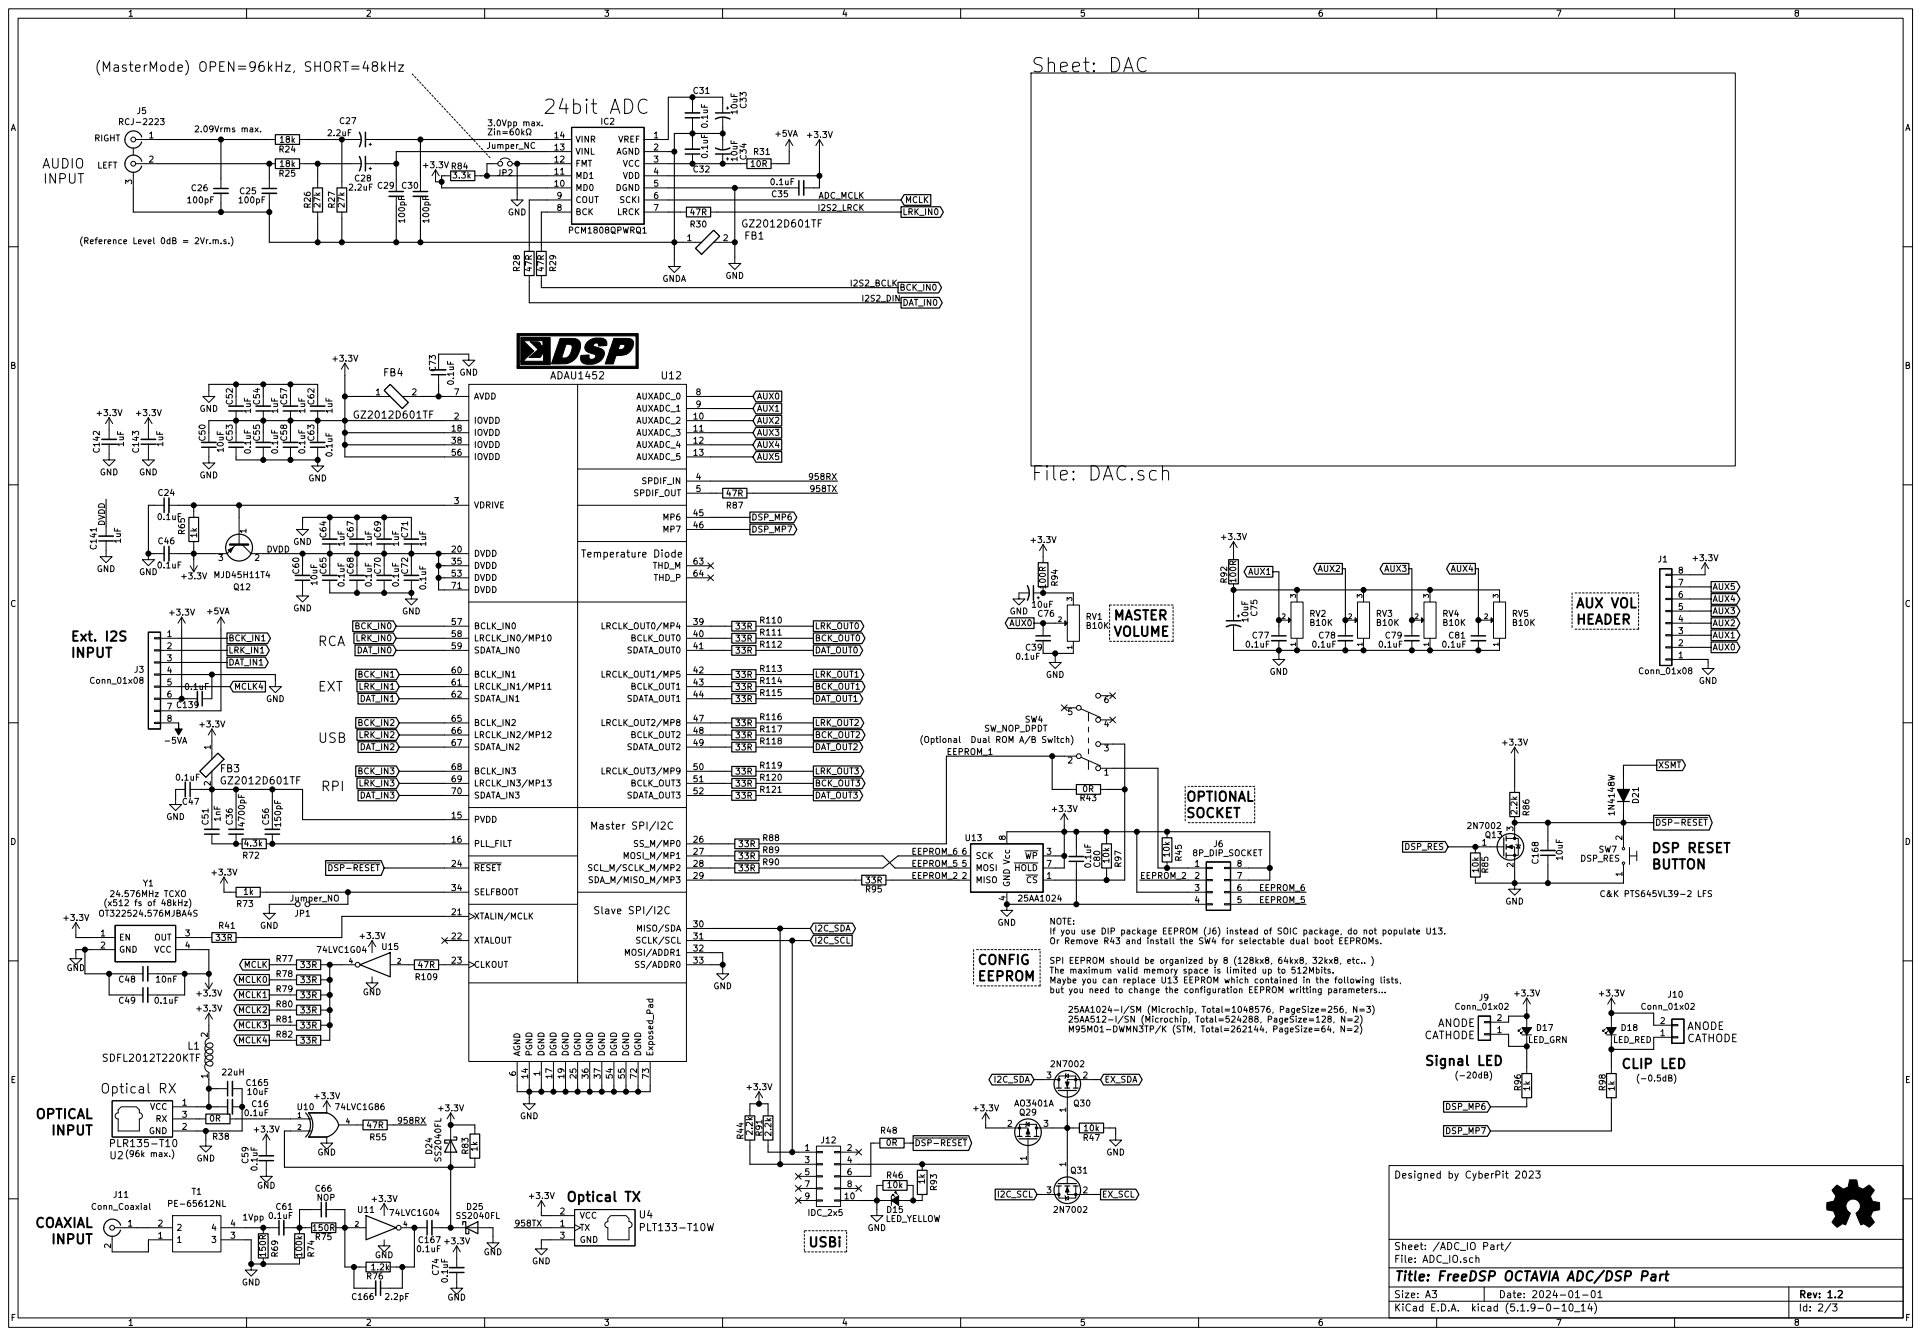
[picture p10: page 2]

LRCLK_IN3/MP13 69 ADAU1452 | U12

6 AVDD 7 AUXADC_0 8 AUXADC_1 9 AUXADC_2 10 DVDD 20 MISO/SDA 30 BCLK_OUT0 40

5 | 0.1uF

(Optional Dual ROM A/B Switch)

4 MOSI 5 SCK 6 HOLD 7 Vcc U13 8

NOTE:
If you use DIP package EEPROM (J6) instead of SOIC package, do not populate U13. Or Remove R43 and install the SW4 for selectable dual boot EEPROMs. SPI EEPROM should be organized by 8 (128kx8, 64kx8, 32kx8, etc.. )

The maximum valid memory space is limited up to 512Mbits.
Maybe you can replace U13 EEPROM which contained in the following lists,
but you need to change the configuration EEPROM writting parameters

25AA1024-I/SM (Microchip, Total=1048576, PageSize=256, N=3)
25AA512-I/SN (Microchip, Total=524288, PageSize=128, N=2)
M95M01-DWMN3TP/K (STM, Total=262144, PageSize=64, N=2)

Sheet: /ADC_IO Part/
File: ADC_IO.sch
Id: 2/3 Title: FreeDSP OCTAVIA ADC/DSP Part

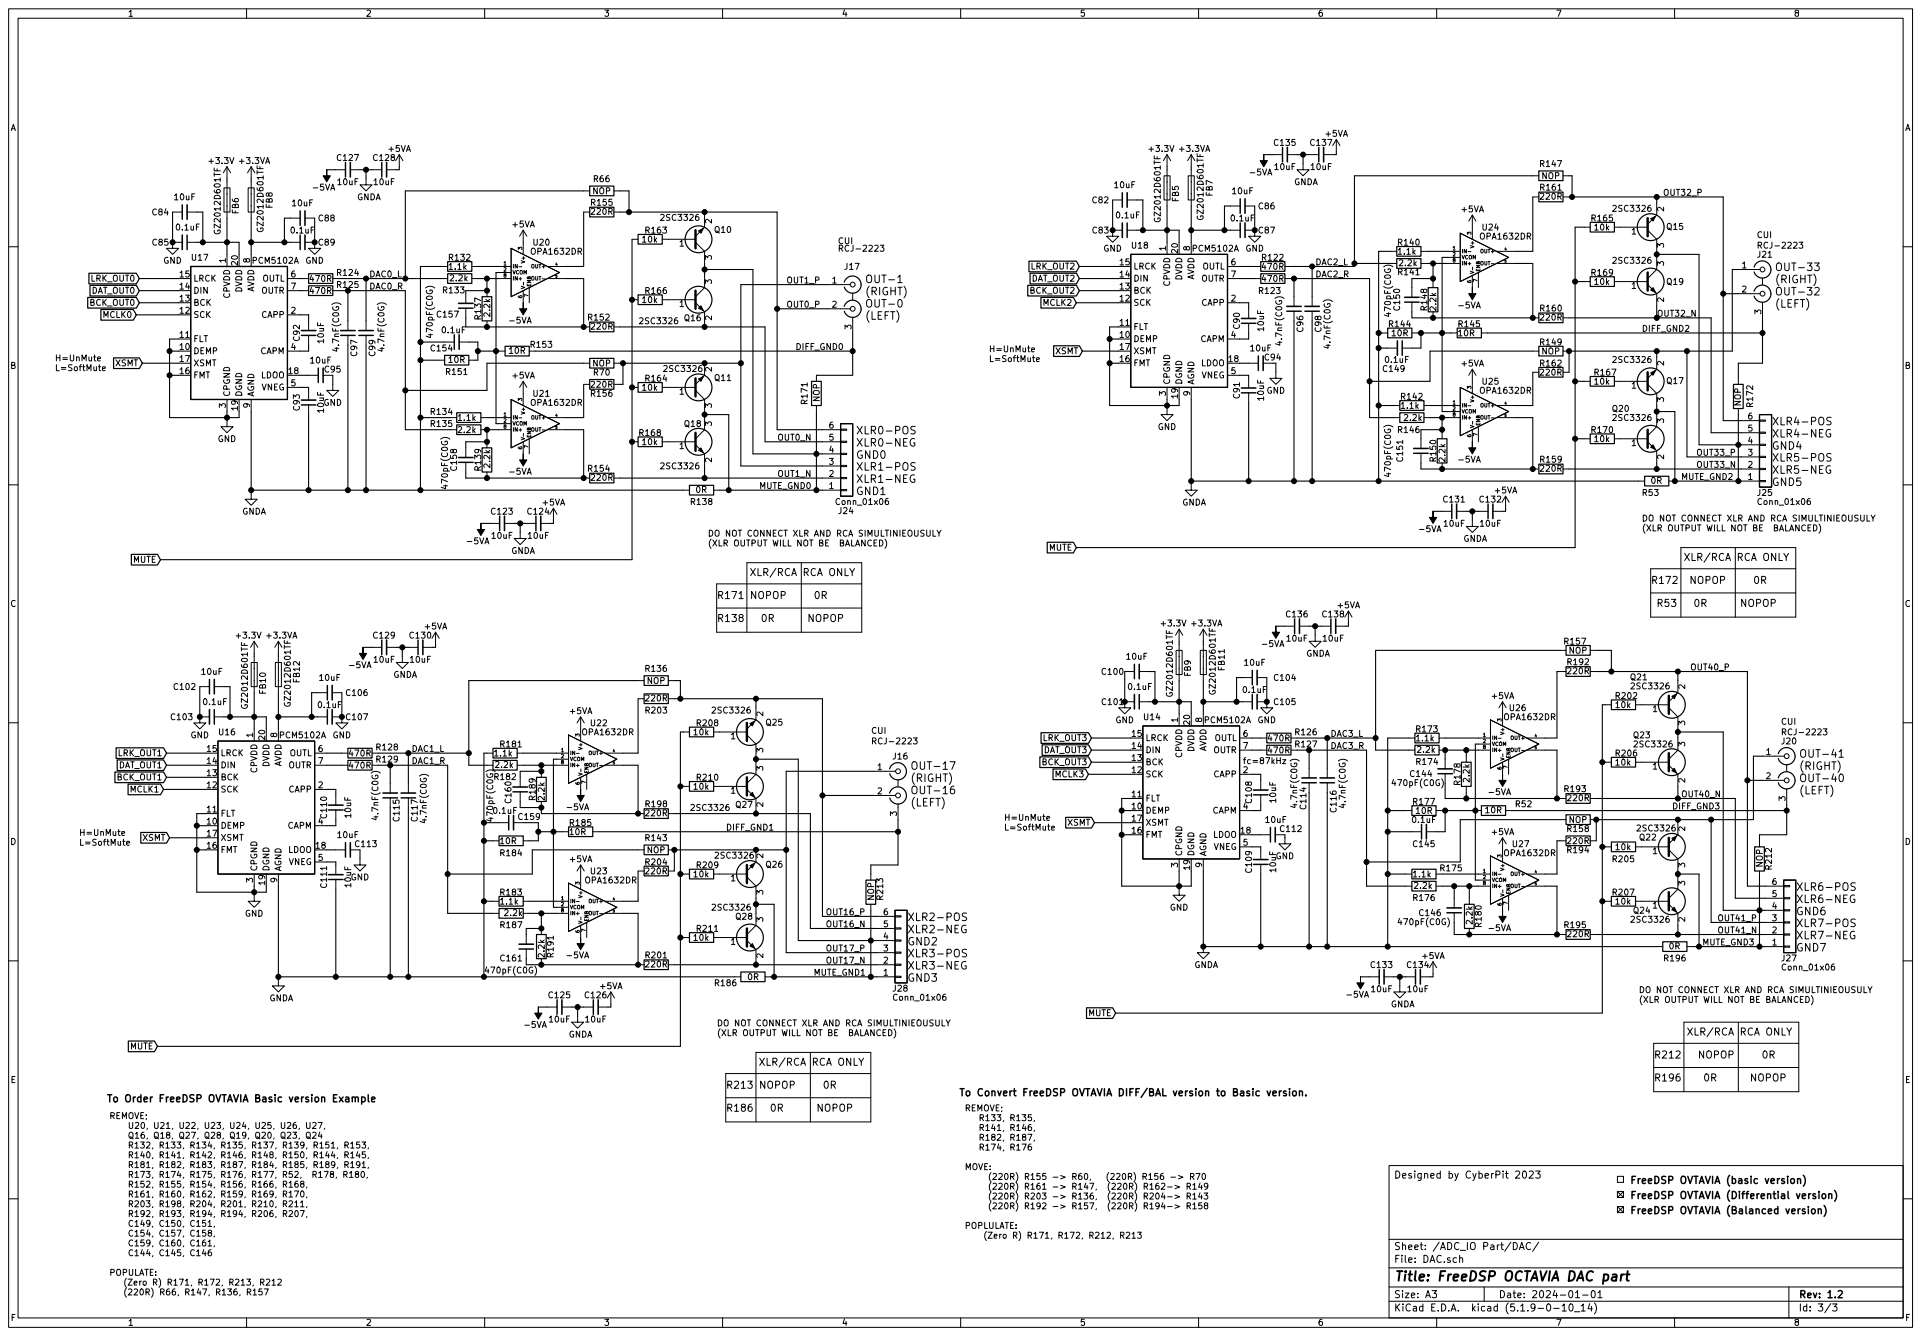
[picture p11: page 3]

1 DEMP 10 FLT 11 SCK 12 BCK 13 DIN 14

3 CAPM 4 VNEG 5 OUTL 6 OUTR 7 AVDD

DO NOT CONNECT XLR AND RCA SIMULTINIEOUSULY
(XLR OUTPUT WILL NOT BE BALANCED)

Designed by CyberPit 2023R52 10R

To Convert FreeDSP OVTAVIA DIFF/BAL version to Basic version. To Order FreeDSP OVTAVIA Basic version Example

FreeDSP OVTAVIA (basic version)
FreeDSP OVTAVIA (Differential version)
FreeDSP OVTAVIA (Balanced version)

Id: 3/3 Title: FreeDSP OCTAVIA DAC part File: DAC.sch Sheet: /ADC_IO Part/DAC/

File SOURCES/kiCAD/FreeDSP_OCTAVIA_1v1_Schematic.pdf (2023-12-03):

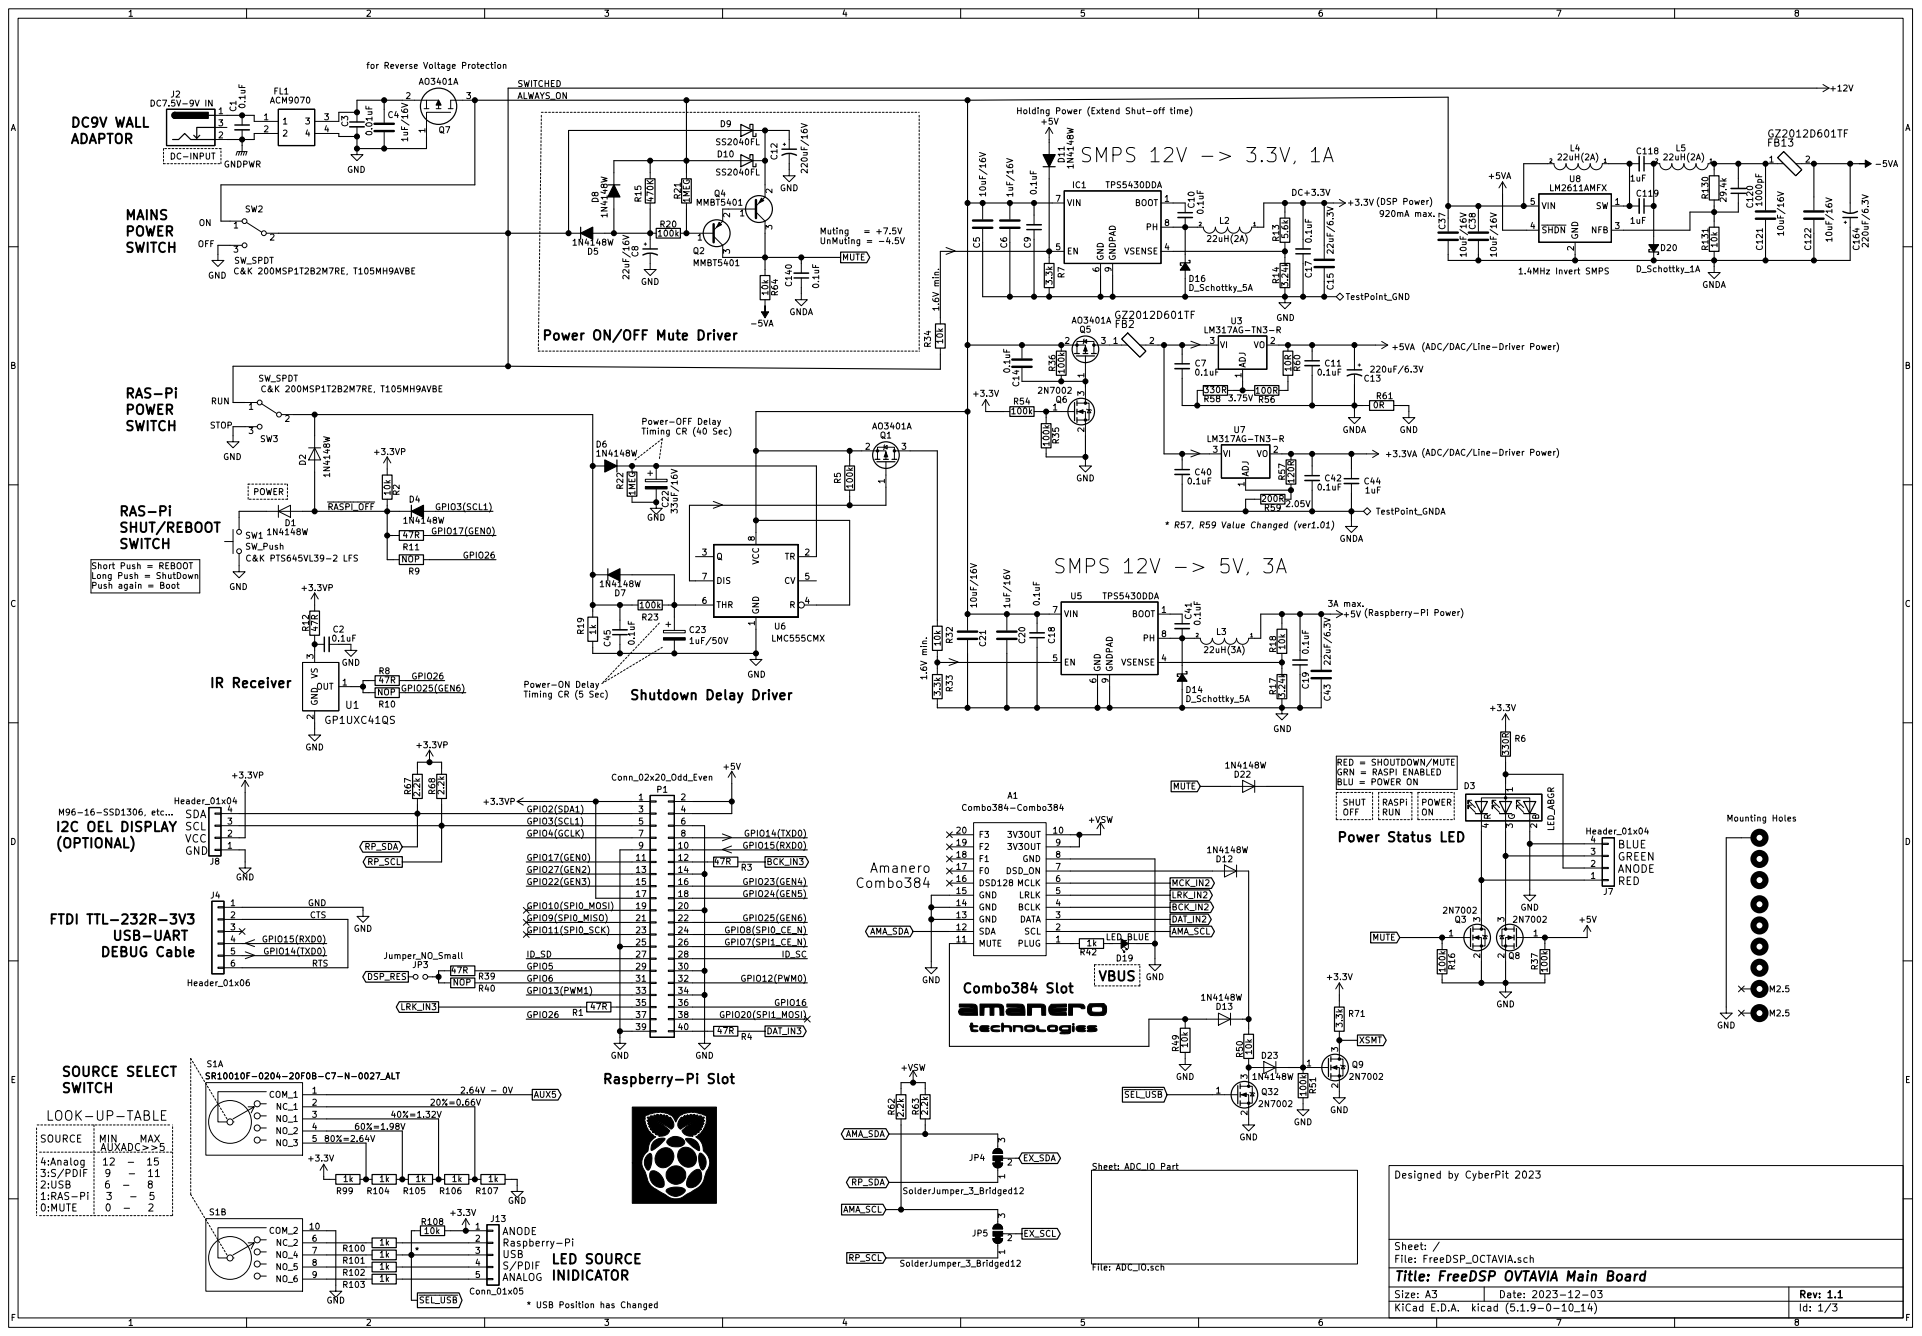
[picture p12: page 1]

for Reverse Voltage Protection

Holding Power (Extend Shut-off time)
SMPS 12V -> 3.3V, 1A
DC+3.3V Power Status LED
+3.3V C43 22uF/6.3V GND

2 Q2 3 MMBT5401 GNDA ADJ 1 VO 2 VI 3 U7

Power ON/OFF Mute Driver

(ADC/DAC/Line-Driver Power)

Timing CR (40 Sec) Short Push = REBOOT

RASPi RUN RAS-Pi
SHUT/REBOOT
SWITCH

BLU = POWER ON SOURCE SELECT

SOURCE MIN MAX | AUXADC>>5

4:Analog 12 - 15 3:S/PDIF 9 6 1:RAS-Pi 3 | - 8 - 11 2:USB - 5

File: FreeDSP_OCTAVIA.sch Sheet: / Designed by CyberPit 2023 Sheet: ADC_IO Part File: ADC_IO.sch

Id: 1/3 Title: FreeDSP OVTAVIA Main Board

* USB Position has Changed

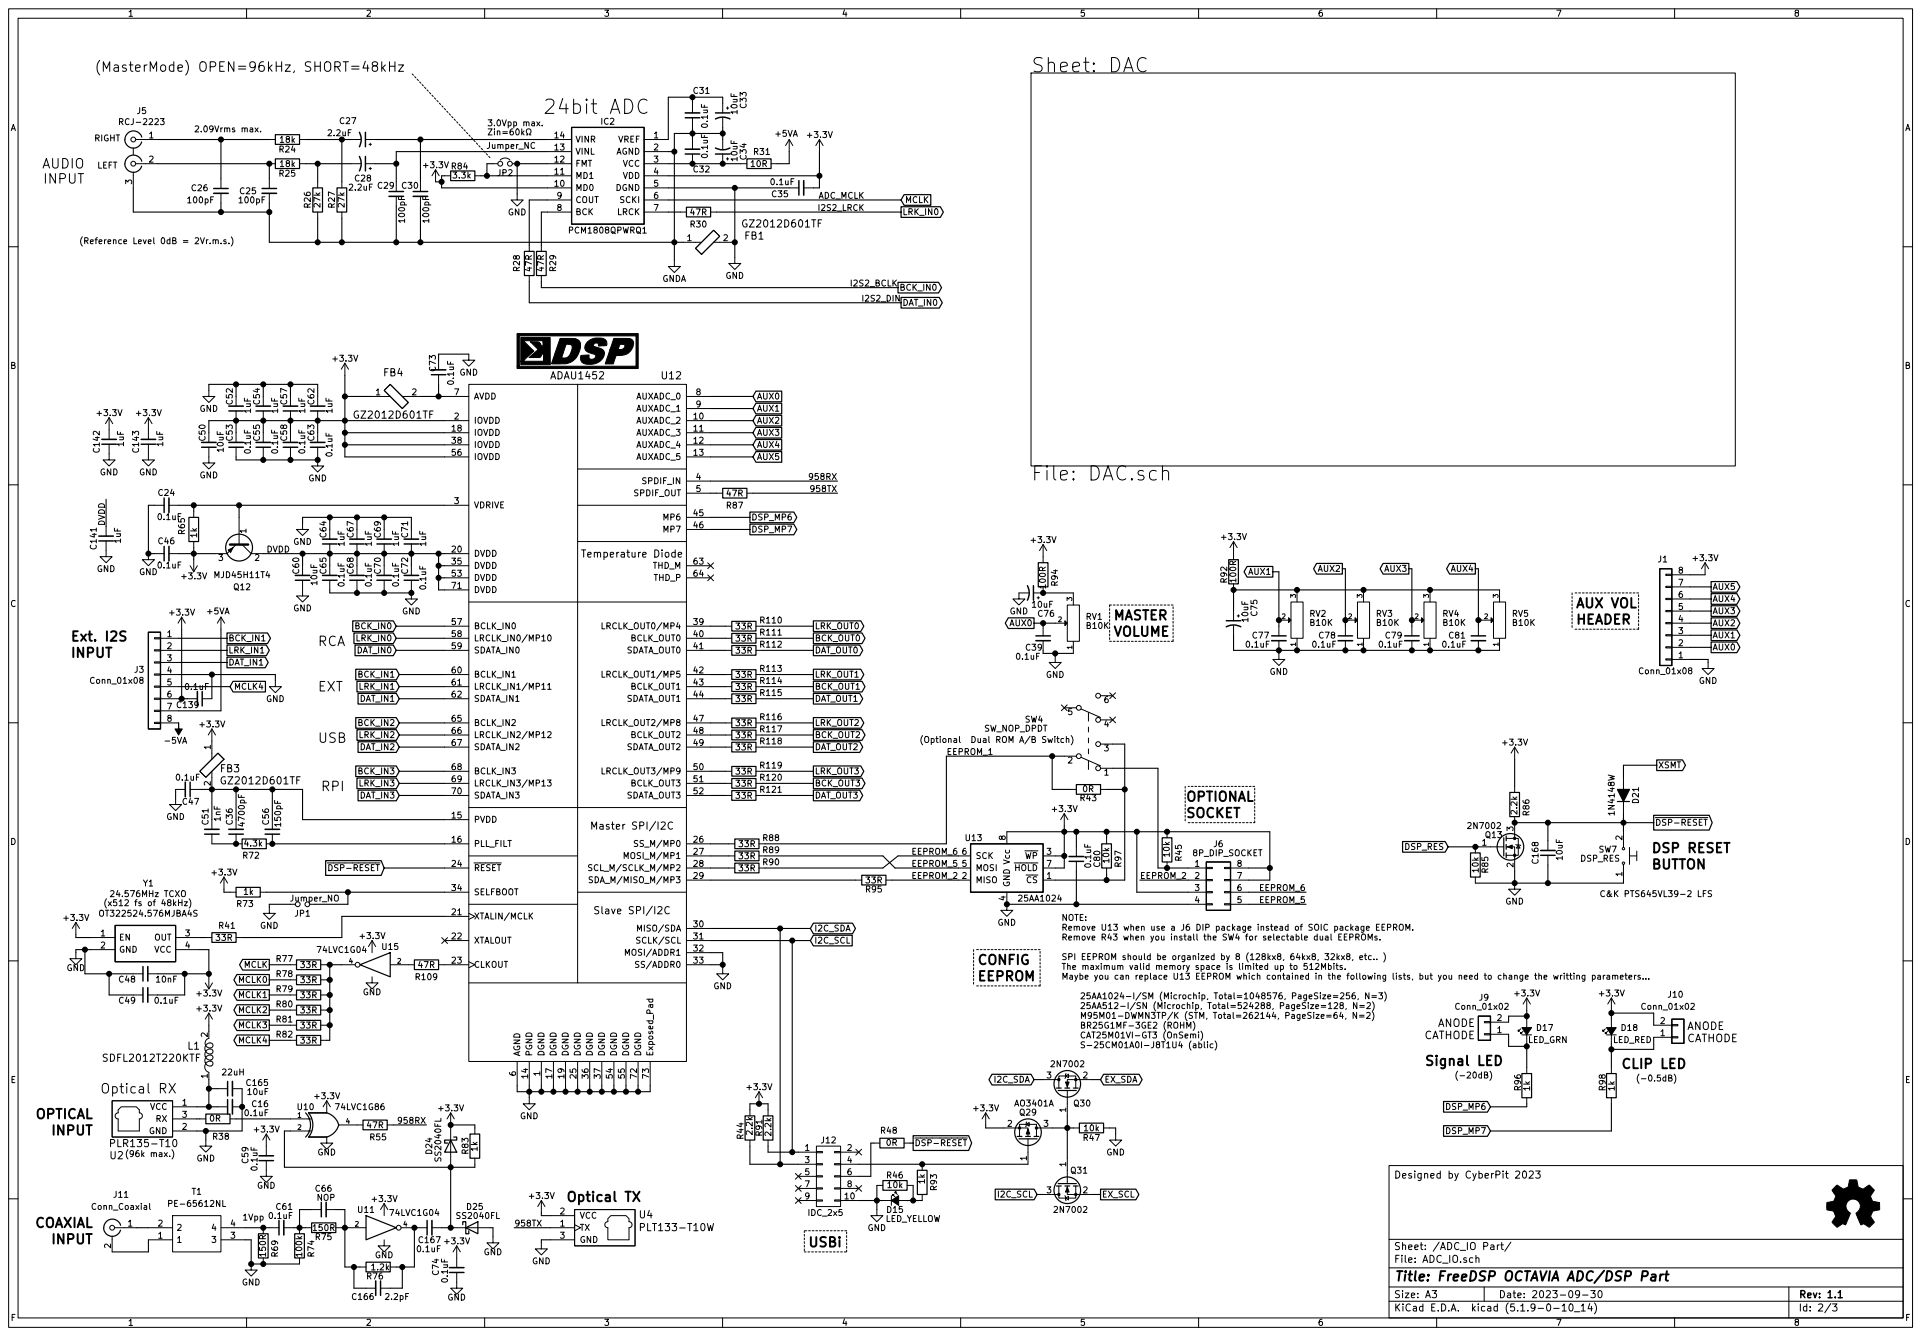
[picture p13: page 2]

LRCLK_IN3/MP13 69 ADAU1452 | U12

6 AVDD 7 AUXADC_0 8 AUXADC_1 9 AUXADC_2 10 DVDD 20 MISO/SDA 30 BCLK_OUT0 40

5 | 0.1uF

(Optional Dual ROM A/B Switch)

4 MOSI 5 SCK 6 HOLD 7 Vcc U13 8

NOTE: Remove U13 when use a J6 DIP package instead of SOIC package EEPROM.

Remove R43 when you install the SW4 for selectable dual EEPROMs.

SPI EEPROM should be organized by 8 (128kx8, 64kx8, 32kx8, etc.. )
The maximum valid memory space is limited up to 512Mbits.
Maybe you can replace U13 EEPROM which contained in the following lists, but you need to change the writting parameters

25AA1024-I/SM (Microchip, Total=1048576, PageSize=256, N=3)
25AA512-I/SN (Microchip, Total=524288, PageSize=128, N=2)
M95M01-DWMN3TP/K (STM, Total=262144, PageSize=64, N=2)
BR25G1MF-3GE2 (ROHM)
CAT25M01VI-GT3 (OnSemi)
S-25CM01A0I-J8T1U4 (ablic)

Sheet: /ADC_IO Part/
File: ADC_IO.sch
Id: 2/3 Title: FreeDSP OCTAVIA ADC/DSP Part

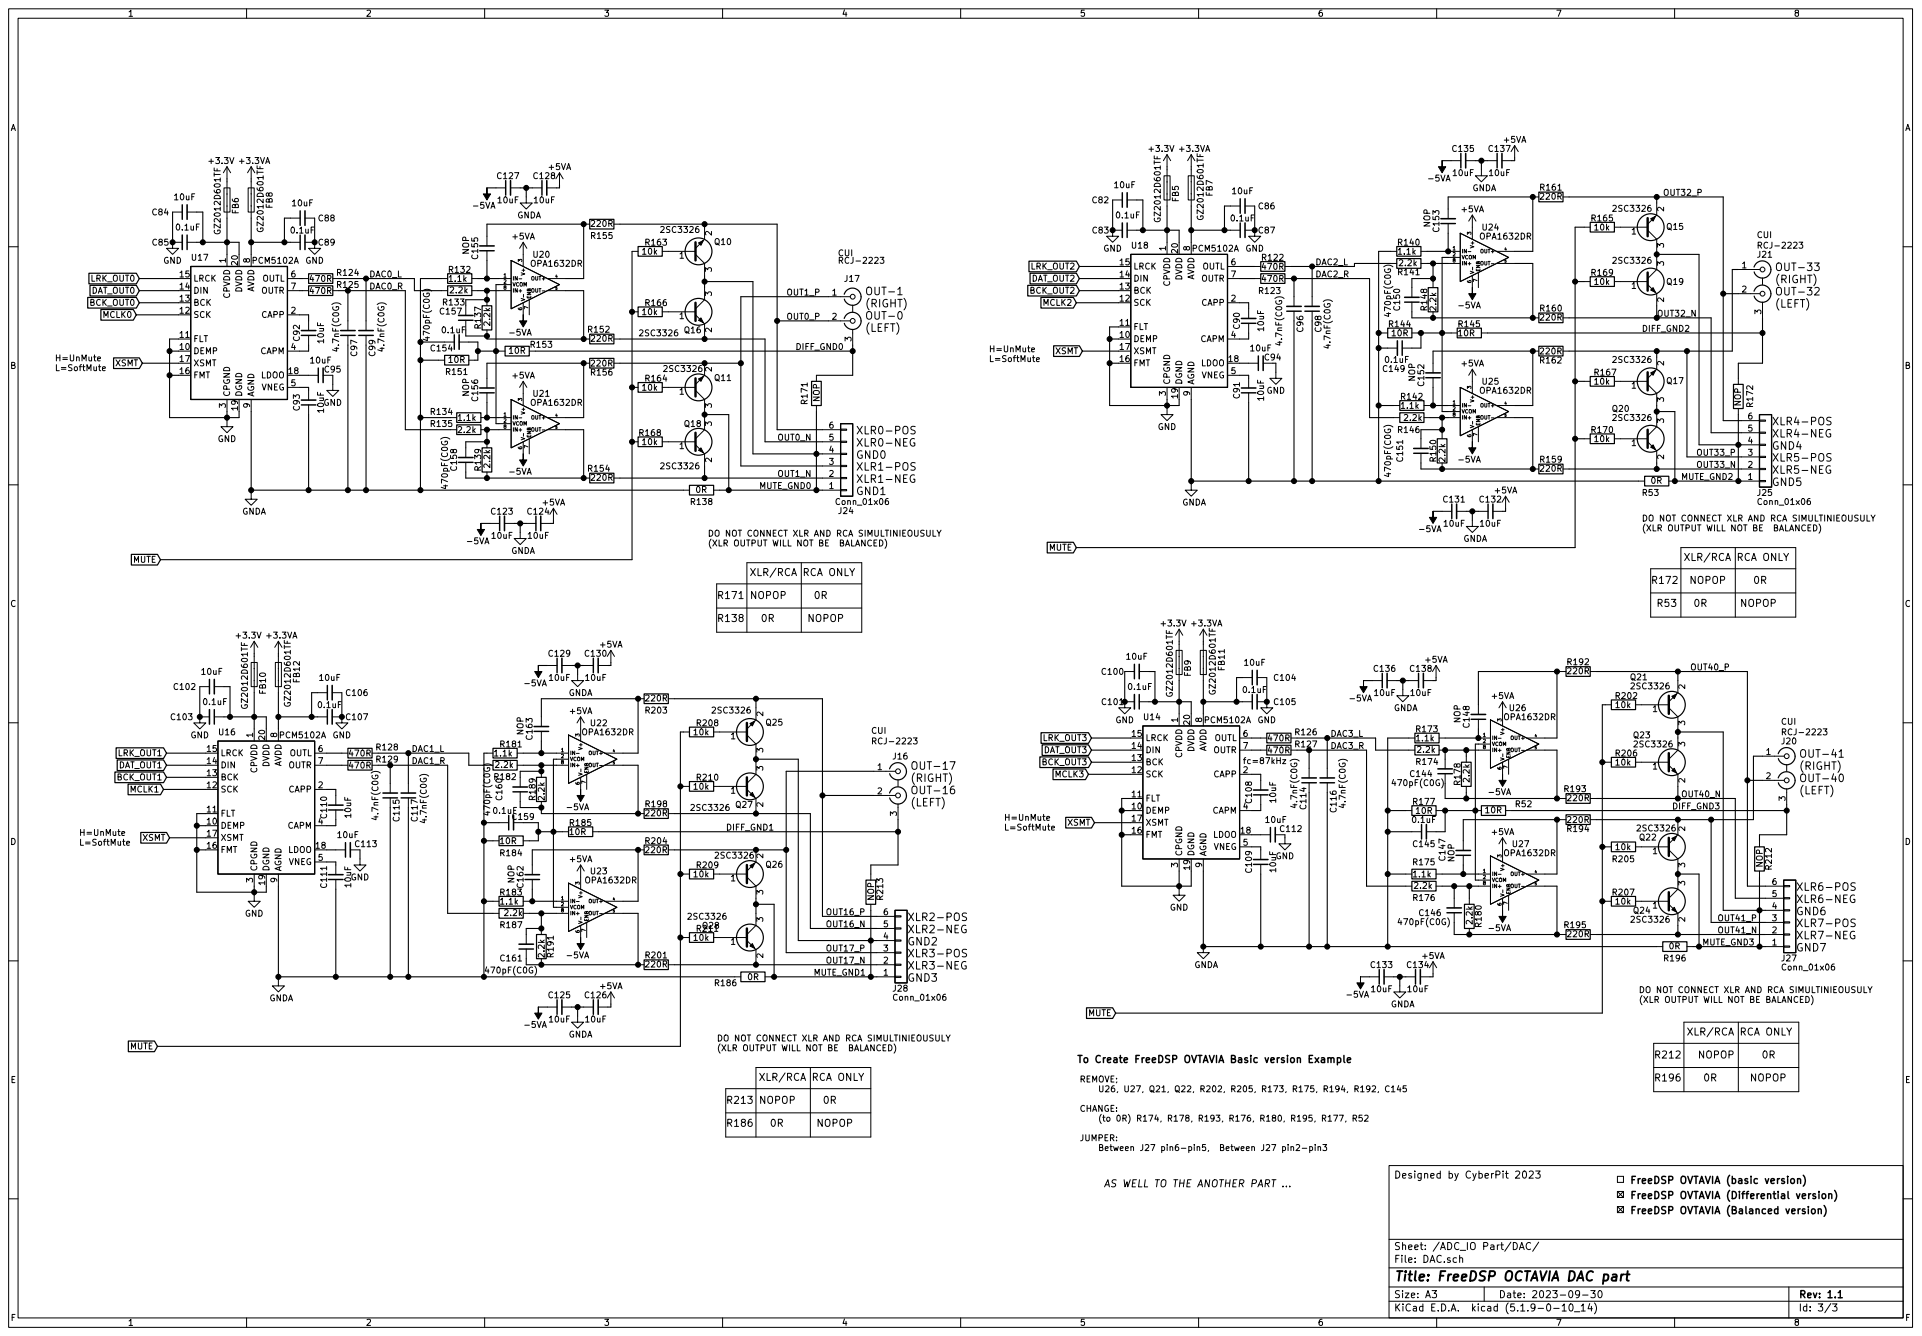
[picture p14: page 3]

(XLR OUTPUT WILL NOT BE BALANCED) CUI

1 DEMP 10 FLT 11 SCK 12 BCK 13 DIN 14

3 CAPM 4 VNEG 5 OUTL 6 OUTR 7 AVDD

GND4 DO NOT CONNECT XLR AND RCA SIMULTINIEOUSULY

DO NOT CONNECT XLR AND RCA SIMULTINIEOUSULY

(XLR OUTPUT WILL NOT BE BALANCED)

To Create FreeDSP OVTAVIA Basic version Example

JUMPER:
Between J27 pin6-pin5, Between J27 pin2-pin3 AS WELL TO THE ANOTHER PART

FreeDSP OVTAVIA (basic version)

Id: 3/3 Title: FreeDSP OCTAVIA DAC part File: DAC.sch Sheet: /ADC_IO Part/DAC/

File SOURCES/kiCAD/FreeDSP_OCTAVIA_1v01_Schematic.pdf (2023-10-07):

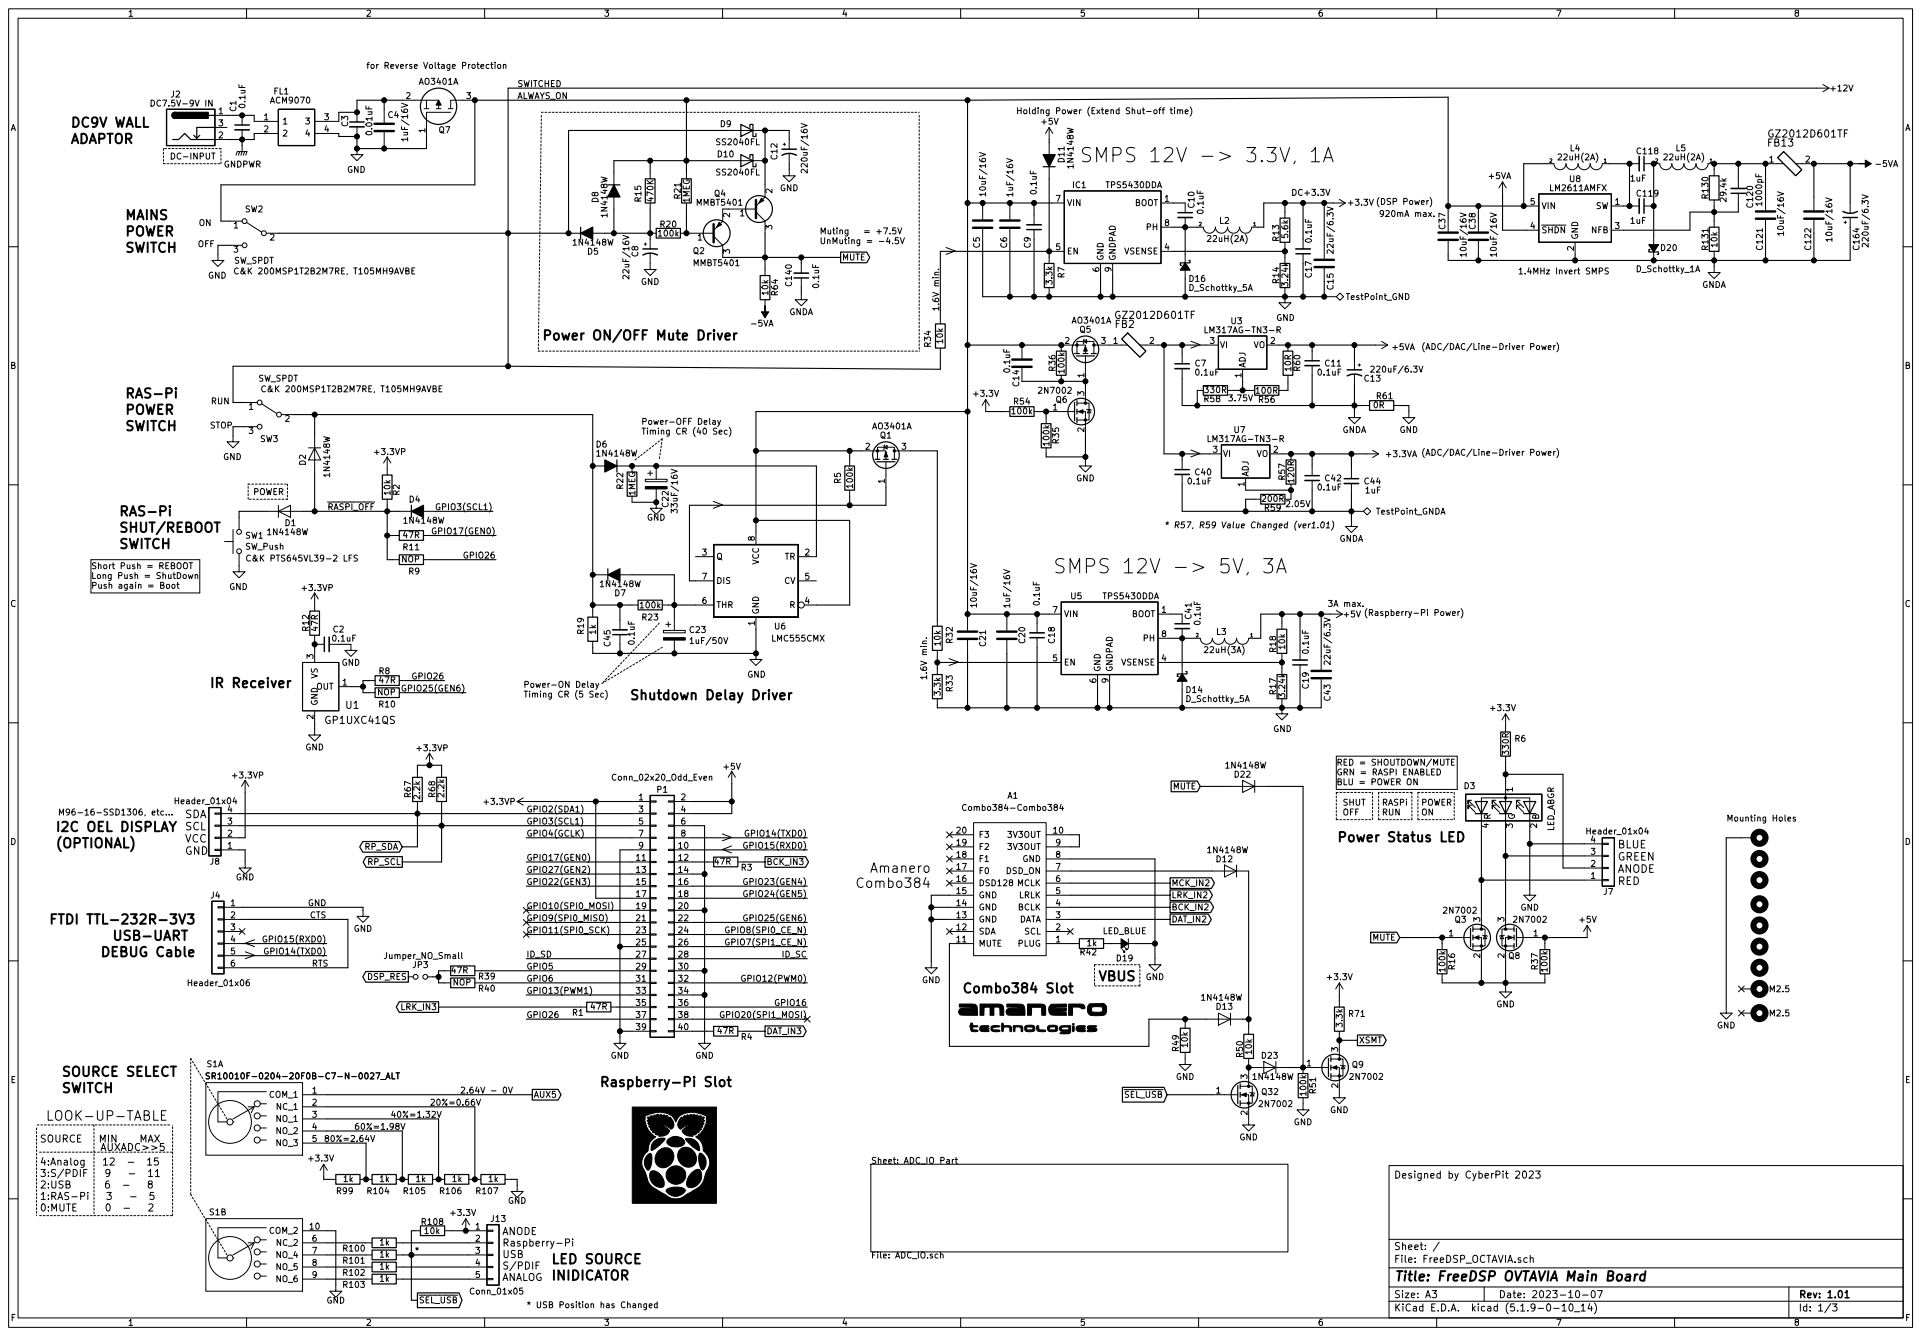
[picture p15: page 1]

for Reverse Voltage Protection

Holding Power (Extend Shut-off time)

3.75V Power ON/OFF Mute Driver

(ADC/DAC/Line-Driver Power) 2.05V

RED = SHOUTDOWN/MUTE GRN = RASPI ENABLED

RASPi RUN | POWER ON

3 | GPIO3(SCL1)

15 | 16 18 20
17

SOURCE MIN MAX

* USB Position has Changed AUXADC>>5

4:Analog 12 - 15 3:S/PDIF 9 6 1:RAS-Pi 3 | - 8 - 11 2:USB - 5

File: FreeDSP_OCTAVIA.sch Sheet: / Designed by CyberPit 2023 Sheet: ADC_IO Part File: ADC_IO.sch

Id: 1/3 Title: FreeDSP OVTAVIA Main Board

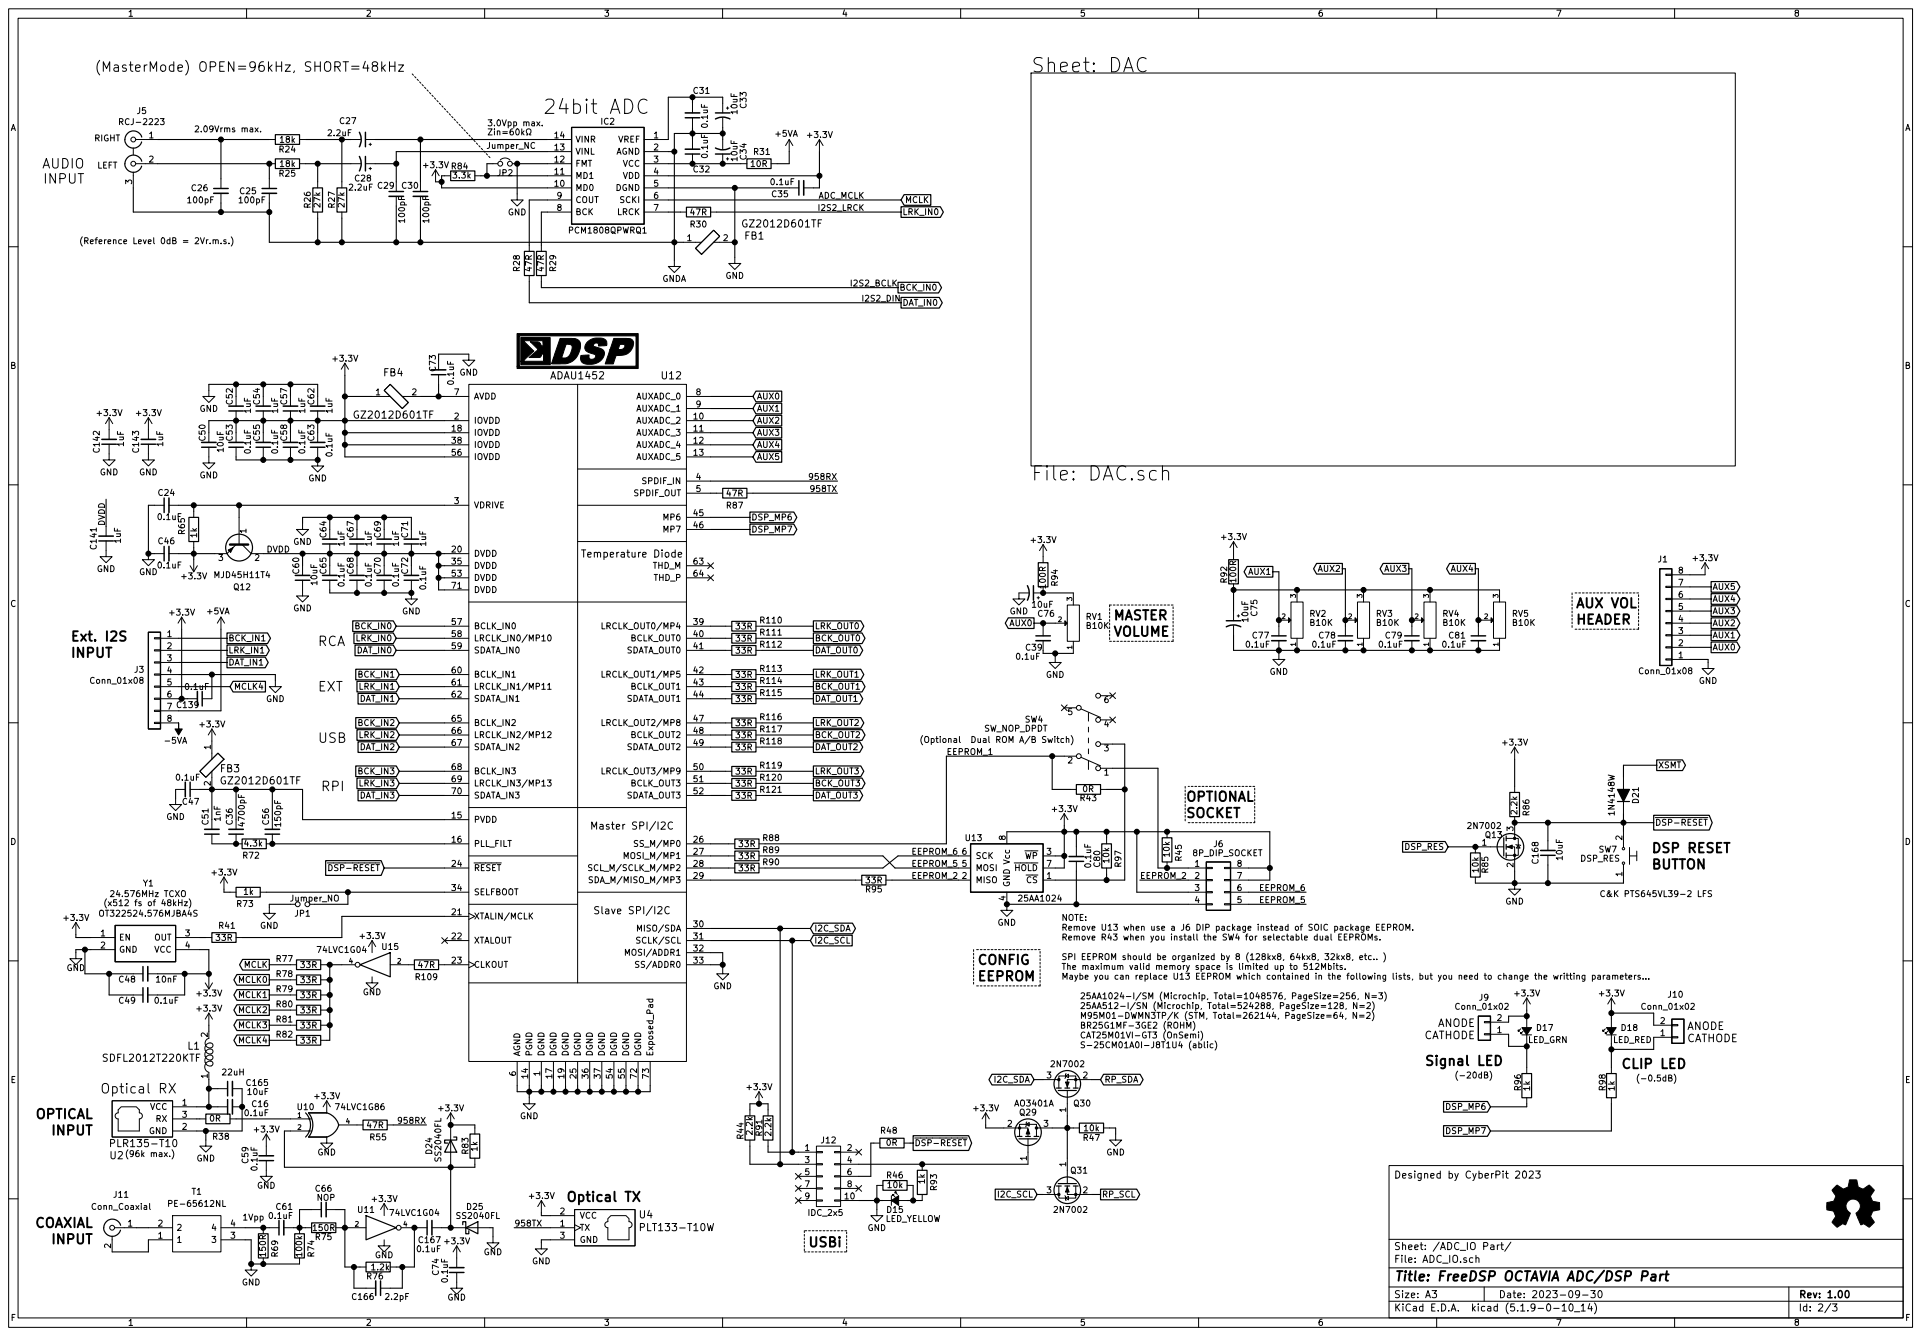
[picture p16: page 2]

LRCLK_IN3/MP13 69 ADAU1452 | U12

6 AVDD 7 AUXADC_0 8 AUXADC_1 9 AUXADC_2 10 DVDD 20 MISO/SDA 30 BCLK_OUT0 40

5 | 0.1uF

(Optional Dual ROM A/B Switch)

4 MOSI 5 SCK 6 HOLD 7 Vcc U13 8

NOTE: Remove U13 when use a J6 DIP package instead of SOIC package EEPROM.

Remove R43 when you install the SW4 for selectable dual EEPROMs.

SPI EEPROM should be organized by 8 (128kx8, 64kx8, 32kx8, etc.. )
The maximum valid memory space is limited up to 512Mbits.
Maybe you can replace U13 EEPROM which contained in the following lists, but you need to change the writting parameters

25AA1024-I/SM (Microchip, Total=1048576, PageSize=256, N=3)
25AA512-I/SN (Microchip, Total=524288, PageSize=128, N=2)
M95M01-DWMN3TP/K (STM, Total=262144, PageSize=64, N=2)
BR25G1MF-3GE2 (ROHM)
CAT25M01VI-GT3 (OnSemi)
S-25CM01A0I-J8T1U4 (ablic)

Sheet: /ADC_IO Part/
File: ADC_IO.sch
Id: 2/3 Title: FreeDSP OCTAVIA ADC/DSP Part

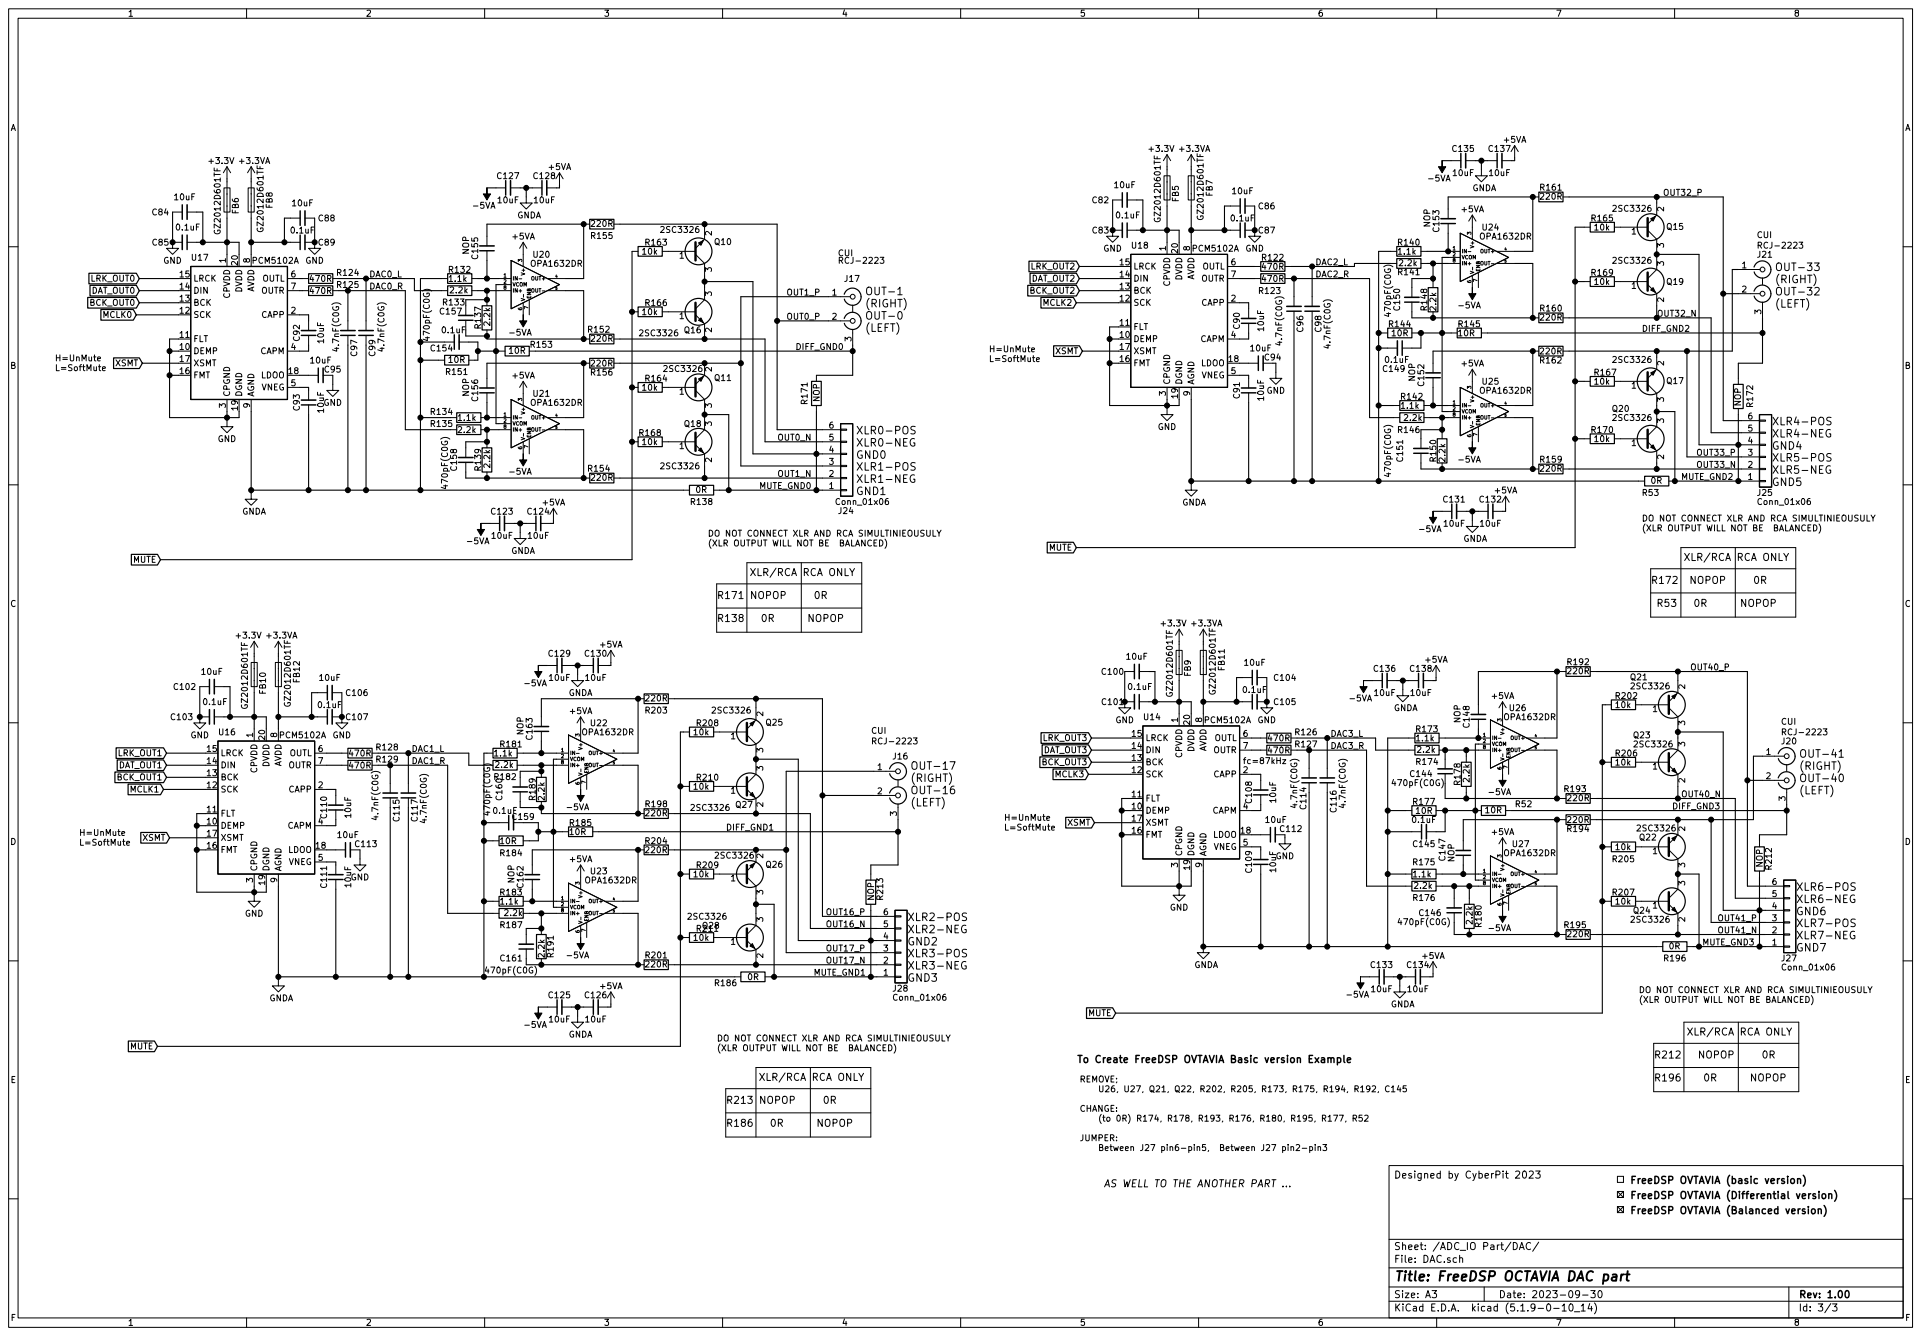
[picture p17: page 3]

(XLR OUTPUT WILL NOT BE BALANCED) CUI

1 DEMP 10 FLT 11 SCK 12 BCK 13 DIN 14

3 CAPM 4 VNEG 5 OUTL 6 OUTR 7 AVDD

GND4 DO NOT CONNECT XLR AND RCA SIMULTINIEOUSULY

DO NOT CONNECT XLR AND RCA SIMULTINIEOUSULY

(XLR OUTPUT WILL NOT BE BALANCED)

To Create FreeDSP OVTAVIA Basic version Example

JUMPER:
Between J27 pin6-pin5, Between J27 pin2-pin3 AS WELL TO THE ANOTHER PART

FreeDSP OVTAVIA (basic version)

Id: 3/3 Title: FreeDSP OCTAVIA DAC part File: DAC.sch Sheet: /ADC_IO Part/DAC/

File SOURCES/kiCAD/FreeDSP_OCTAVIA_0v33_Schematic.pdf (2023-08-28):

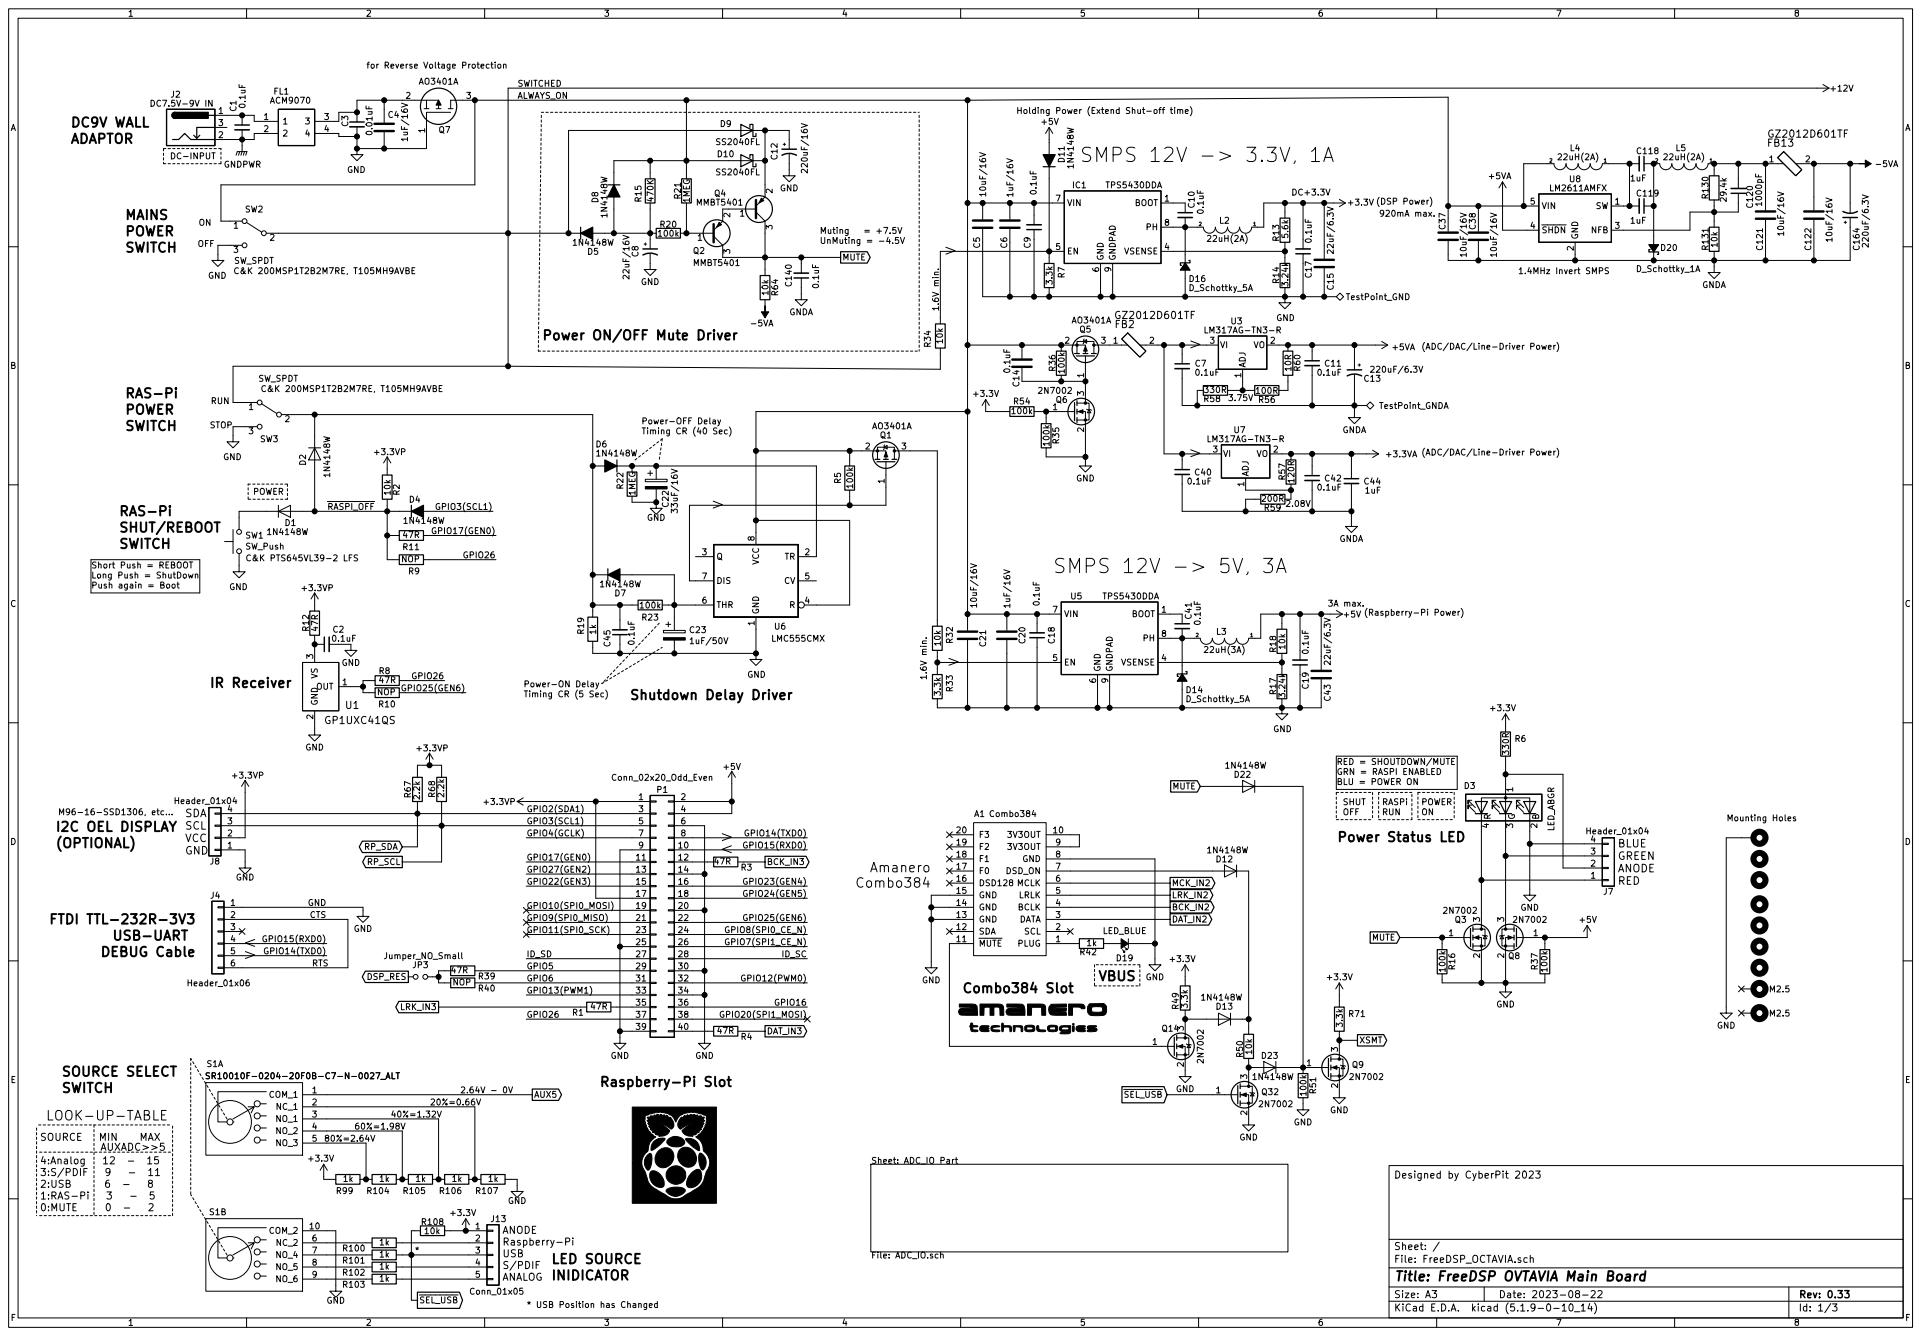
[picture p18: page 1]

DC-INPUT FTDI TTL-232R-3V3

for Reverse Voltage Protection

Holding Power (Extend Shut-off time)
SMPS 12V -> 3.3V, 1A

Power ON/OFF Mute Driver
POWER AUXADC>>5
SHUT OFF RAS-Pi

RED = SHOUTDOWN/MUTE GRN = RASPI ENABLED

15 | 16 18 20
17

Id: 1/3 Title: FreeDSP OVTAVIA Main Board

* USB Position has Changed

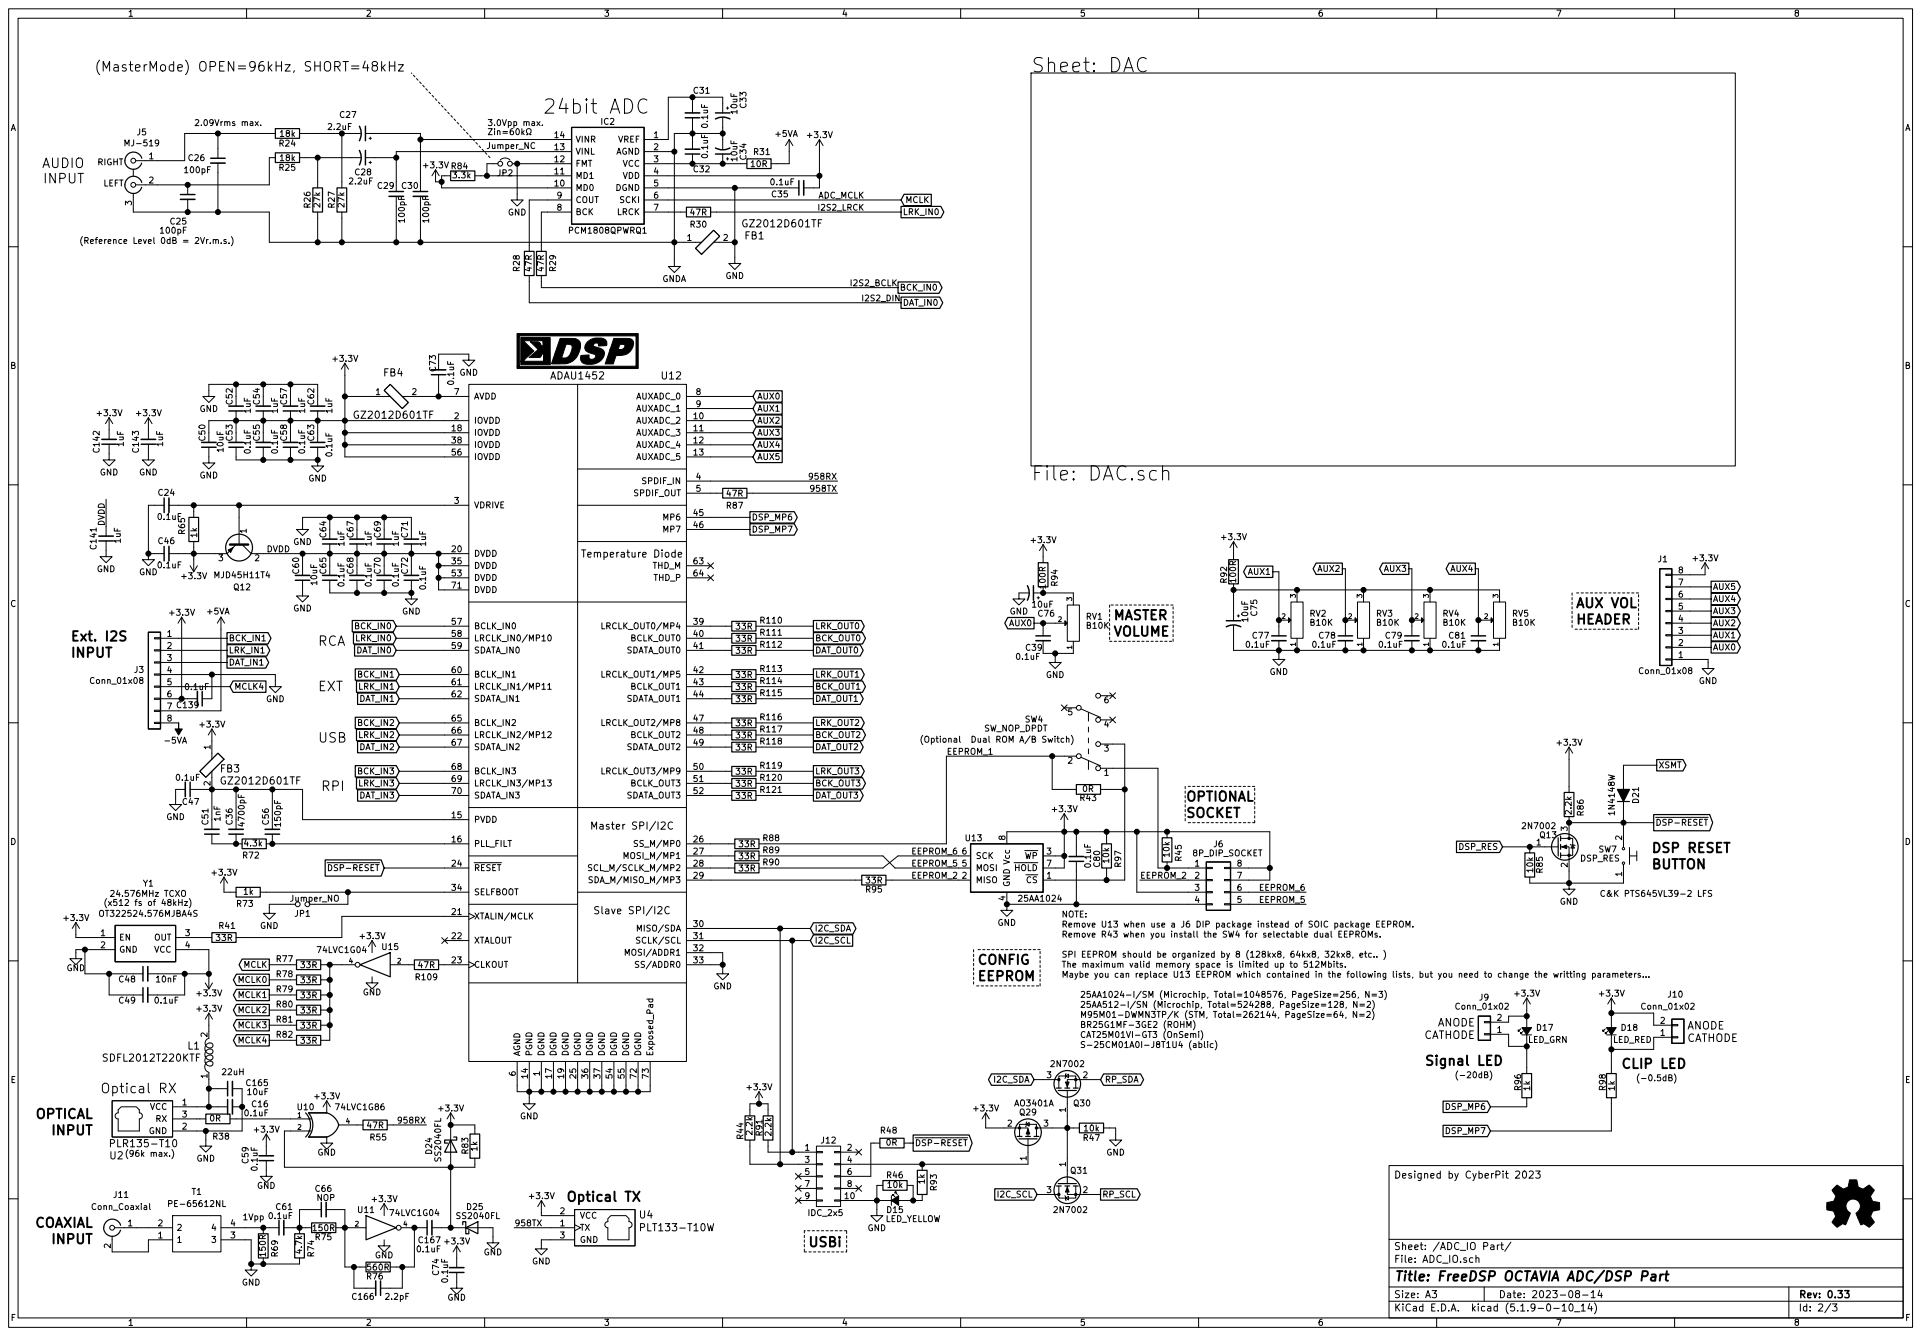
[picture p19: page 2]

LRCLK_IN3/MP13 69 ADAU1452 | U12

6 AVDD 7 AUXADC_0 8 AUXADC_1 9 AUXADC_2 10 DVDD 20 MISO/SDA 30 BCLK_OUT0 40

5 | 0.1uF

(Optional Dual ROM A/B Switch)
EEPROM_6 EEPROM_5 EEPROM_2 EEPROM_6 EEPROM_5 EEPROM_1

4 MOSI 5 SCK 6 HOLD 7 Vcc U13 8

NOTE: Remove U13 when use a J6 DIP package instead of SOIC package EEPROM.

Remove R43 when you install the SW4 for selectable dual EEPROMs.

SPI EEPROM should be organized by 8 (128kx8, 64kx8, 32kx8, etc.. )
The maximum valid memory space is limited up to 512Mbits.
Maybe you can replace U13 EEPROM which contained in the following lists, but you need to change the writting parameters

25AA1024-I/SM (Microchip, Total=1048576, PageSize=256, N=3)
25AA512-I/SN (Microchip, Total=524288, PageSize=128, N=2)
M95M01-DWMN3TP/K (STM, Total=262144, PageSize=64, N=2)
BR25G1MF-3GE2 (ROHM)
CAT25M01VI-GT3 (OnSemi)
S-25CM01A0I-J8T1U4 (ablic)

Sheet: /ADC_IO Part/
File: ADC_IO.sch
Id: 2/3 Title: FreeDSP OCTAVIA ADC/DSP Part

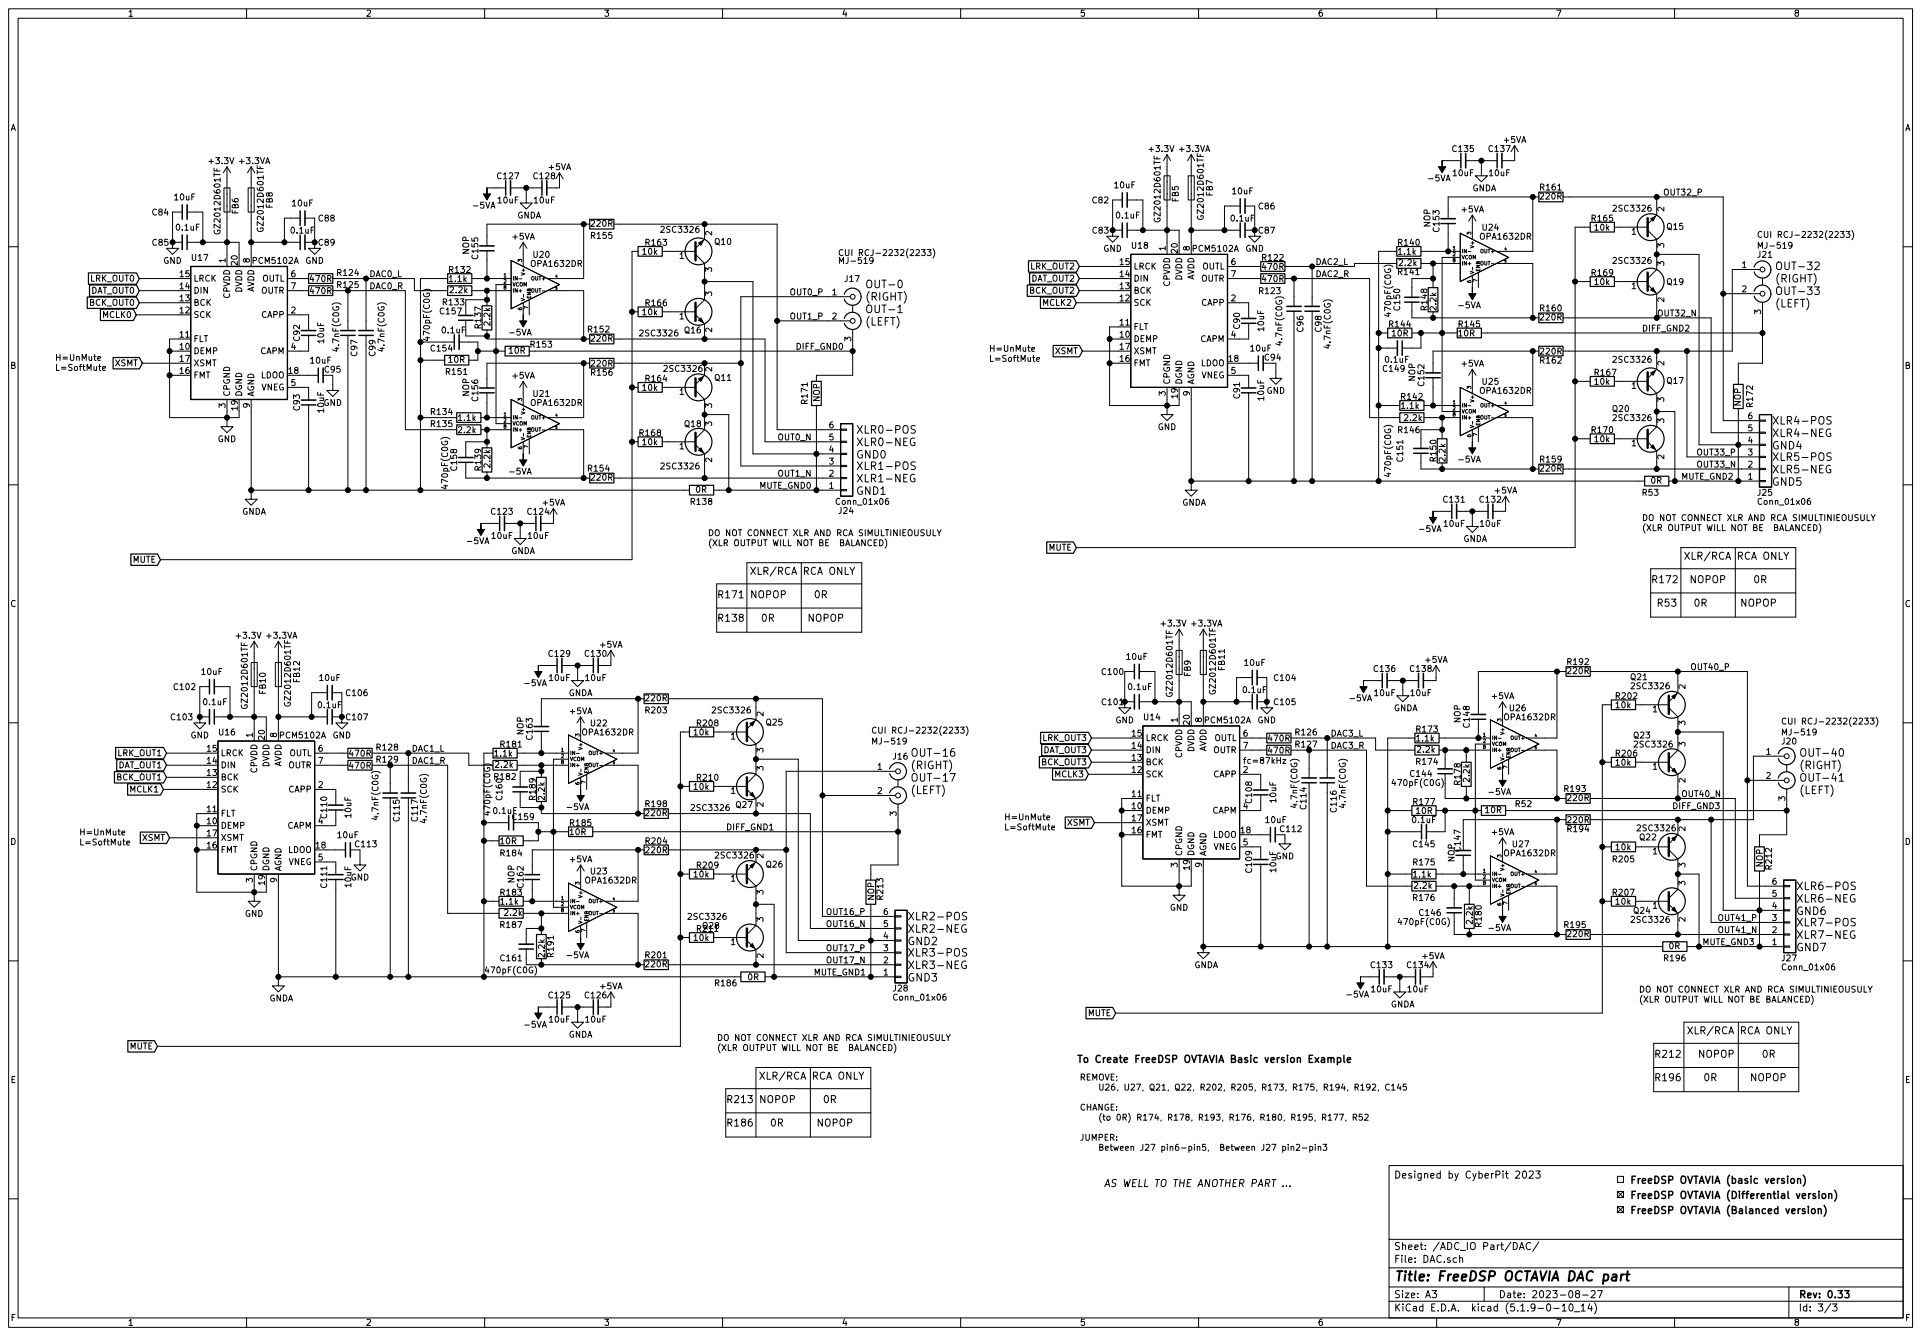
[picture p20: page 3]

1 DEMP 10 FLT 11 SCK 12 BCK 13 DIN 14

3 CAPM 4 VNEG 5 OUTL 6 OUTR 7 AVDD

DO NOT CONNECT XLR AND RCA SIMULTINIEOUSULY
(XLR OUTPUT WILL NOT BE BALANCED)

(XLR OUTPUT WILL NOT BE BALANCED) DO NOT CONNECT XLR AND RCA SIMULTINIEOUSULY

To Create FreeDSP OVTAVIA Basic version Example

JUMPER:
Between J27 pin6-pin5, Between J27 pin2-pin3 AS WELL TO THE ANOTHER PART

FreeDSP OVTAVIA (basic version)
FreeDSP OVTAVIA (Differential version)

Id: 3/3 Title: FreeDSP OCTAVIA DAC part File: DAC.sch Sheet: /ADC_IO Part/DAC/

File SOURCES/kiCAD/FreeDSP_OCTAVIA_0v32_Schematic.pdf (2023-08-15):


for Reverse Voltage Protection

Holding Power (Extend Shut-off time)
DC+3.3V SMPS 12V -> 3.3V, 1A

(ADC/DAC/Line-Driver Power)

3A max. SOURCE MIN MAX

RED = SHOUTDOWN/MUTE GRN = RASPI ENABLED

Id: 1/3 Title: FreeDSP OVTAVIA Main Board


LRCLK_IN3/MP13 69 ADAU1452 | U12

6 AVDD 7 AUXADC_0 8 AUXADC_1 9 AUXADC_2 10 DVDD 20 MISO/SDA 30 BCLK_OUT0 40

5 | 0.1uF

4 MOSI 5 SCK 6 HOLD 7 Vcc U13 8

NOTE: Remove U13 when use a J6 DIP package instead of SOIC package EEPROM.

Remove R43 when you install the SW4 for selectable dual EEPROMs.

SPI EEPROM should be organized by 8 (128kx8, 64kx8, 32kx8, etc.. )
The maximum valid memory space is limited up to 512Mbits.
Maybe you can replace U13 EEPROM which contained in the following lists, but you need to change the writting parameters

25AA1024-I/SM (Microchip, Total=1048576, PageSize=256, N=3)
25AA512-I/SN (Microchip, Total=524288, PageSize=128, N=2)
M95M01-DWMN3TP/K (STM, Total=262144, PageSize=64, N=2)
BR25G1MF-3GE2 (ROHM)
CAT25M01VI-GT3 (OnSemi)
S-25CM01A0I-J8T1U4 (ablic)

Sheet: /ADC_IO Part/
File: ADC_IO.sch
Id: 2/3 Title: FreeDSP OCTAVIA ADC/DSP Part


1 DEMP 10 FLT 11 SCK 12 BCK 13 DIN 14

3 CAPM 4 VNEG 5 OUTL 6 OUTR 7 AVDD

DO NOT CONNECT XLR AND RCA SIMULTINIEOUSULY
(XLR OUTPUT WILL NOT BE BALANCED)

To Create FreeDSP OVTAVIA Basic version Example

JUMPER:
Between J27 pin6-pin5, Between J27 pin2-pin3 AS WELL TO THE ANOTHER PART

FreeDSP OVTAVIA (basic version)
FreeDSP OVTAVIA (Differential version)

Id: 3/3 Title: FreeDSP OCTAVIA DAC part File: DAC.sch Sheet: /ADC_IO Part/DAC/

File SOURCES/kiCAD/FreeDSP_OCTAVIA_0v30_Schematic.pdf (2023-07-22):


Power ON/OFF Mute Driver RUN

(ADC/DAC/Line-Driver Power)

SHUT OFF RAS-Pi
RES/SHUT
SWITCH

3A max. ANODE Raspberry-Pi USB

RED = SHOUTDOWN/MUTE GRN = RASPI ENABLED

SOURCE MIN MAX | AUXADC>>5

4:Analog 12 - 15 3:S/PDIF 9 6 1:RAS-Pi 3 0:MUTE 0 - 2 | - 8 - 11 2:USB - 5

Id: 1/3 Title: FreeDSP OVTAVIA Main Board


6 AVDD 7 AUXADC_0 8 AUXADC_1 9 AUXADC_2 10 DVDD 20 MISO/SDA 30 BCLK_OUT0 40

5 | 0.1uF

4 MOSI 5 SCK 6 HOLD 7 Vcc U13 8

NOTE: Remove U13 when use a J6 DIP package instead of SOIC package EEPROM.

Remove R43 when you install the SW4 for selectable dual EEPROMs.

SPI EEPROM should be organized by 8 (128kx8, 64kx8, 32kx8, etc.. )
The maximum valid memory space is limited up to 512Mbits.
Maybe you can replace U13 EEPROM which contained in the following lists, but you need to change the writting parameters

25AA1024-I/SM (Microchip, Total=1048576, PageSize=256, N=3)
25AA512-I/SN (Microchip, Total=524288, PageSize=128, N=2)
M95M01-DWMN3TP/K (STM, Total=262144, PageSize=64, N=2)
BR25G1MF-3GE2 (ROHM)
CAT25M01VI-GT3 (OnSemi)
S-25CM01A0I-J8T1U4 (ablic)

Sheet: /ADC_IO Part/
File: ADC_IO.sch
Id: 2/3 Title: FreeDSP OCTAVIA ADC/DSP Part


1 DEMP 10 FLT 11 SCK 12 BCK 13 DIN 14

3 CAPM 4 VNEG 5 OUTL 6 OUTR 7 AVDD

DO NOT CONNECT XLR AND RCA SIMULTINIEOUSULY
(XLR OUTPUT WILL NOT BE BALANCED)

To Create FreeDSP OVTAVIA Basic version Example

JUMPER:
Between J27 pin6-pin5, Between J27 pin2-pin3 AS WELL TO THE ANOTHER PART

FreeDSP OVTAVIA (basic version)
FreeDSP OVTAVIA (Differential version)

Id: 3/3 Title: FreeDSP OCTAVIA DAC part File: DAC.sch Sheet: /ADC_IO Part/DAC/

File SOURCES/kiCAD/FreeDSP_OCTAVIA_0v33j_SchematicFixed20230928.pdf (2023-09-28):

Remove R49; Remove Q14

Jumper between Gate-Drain






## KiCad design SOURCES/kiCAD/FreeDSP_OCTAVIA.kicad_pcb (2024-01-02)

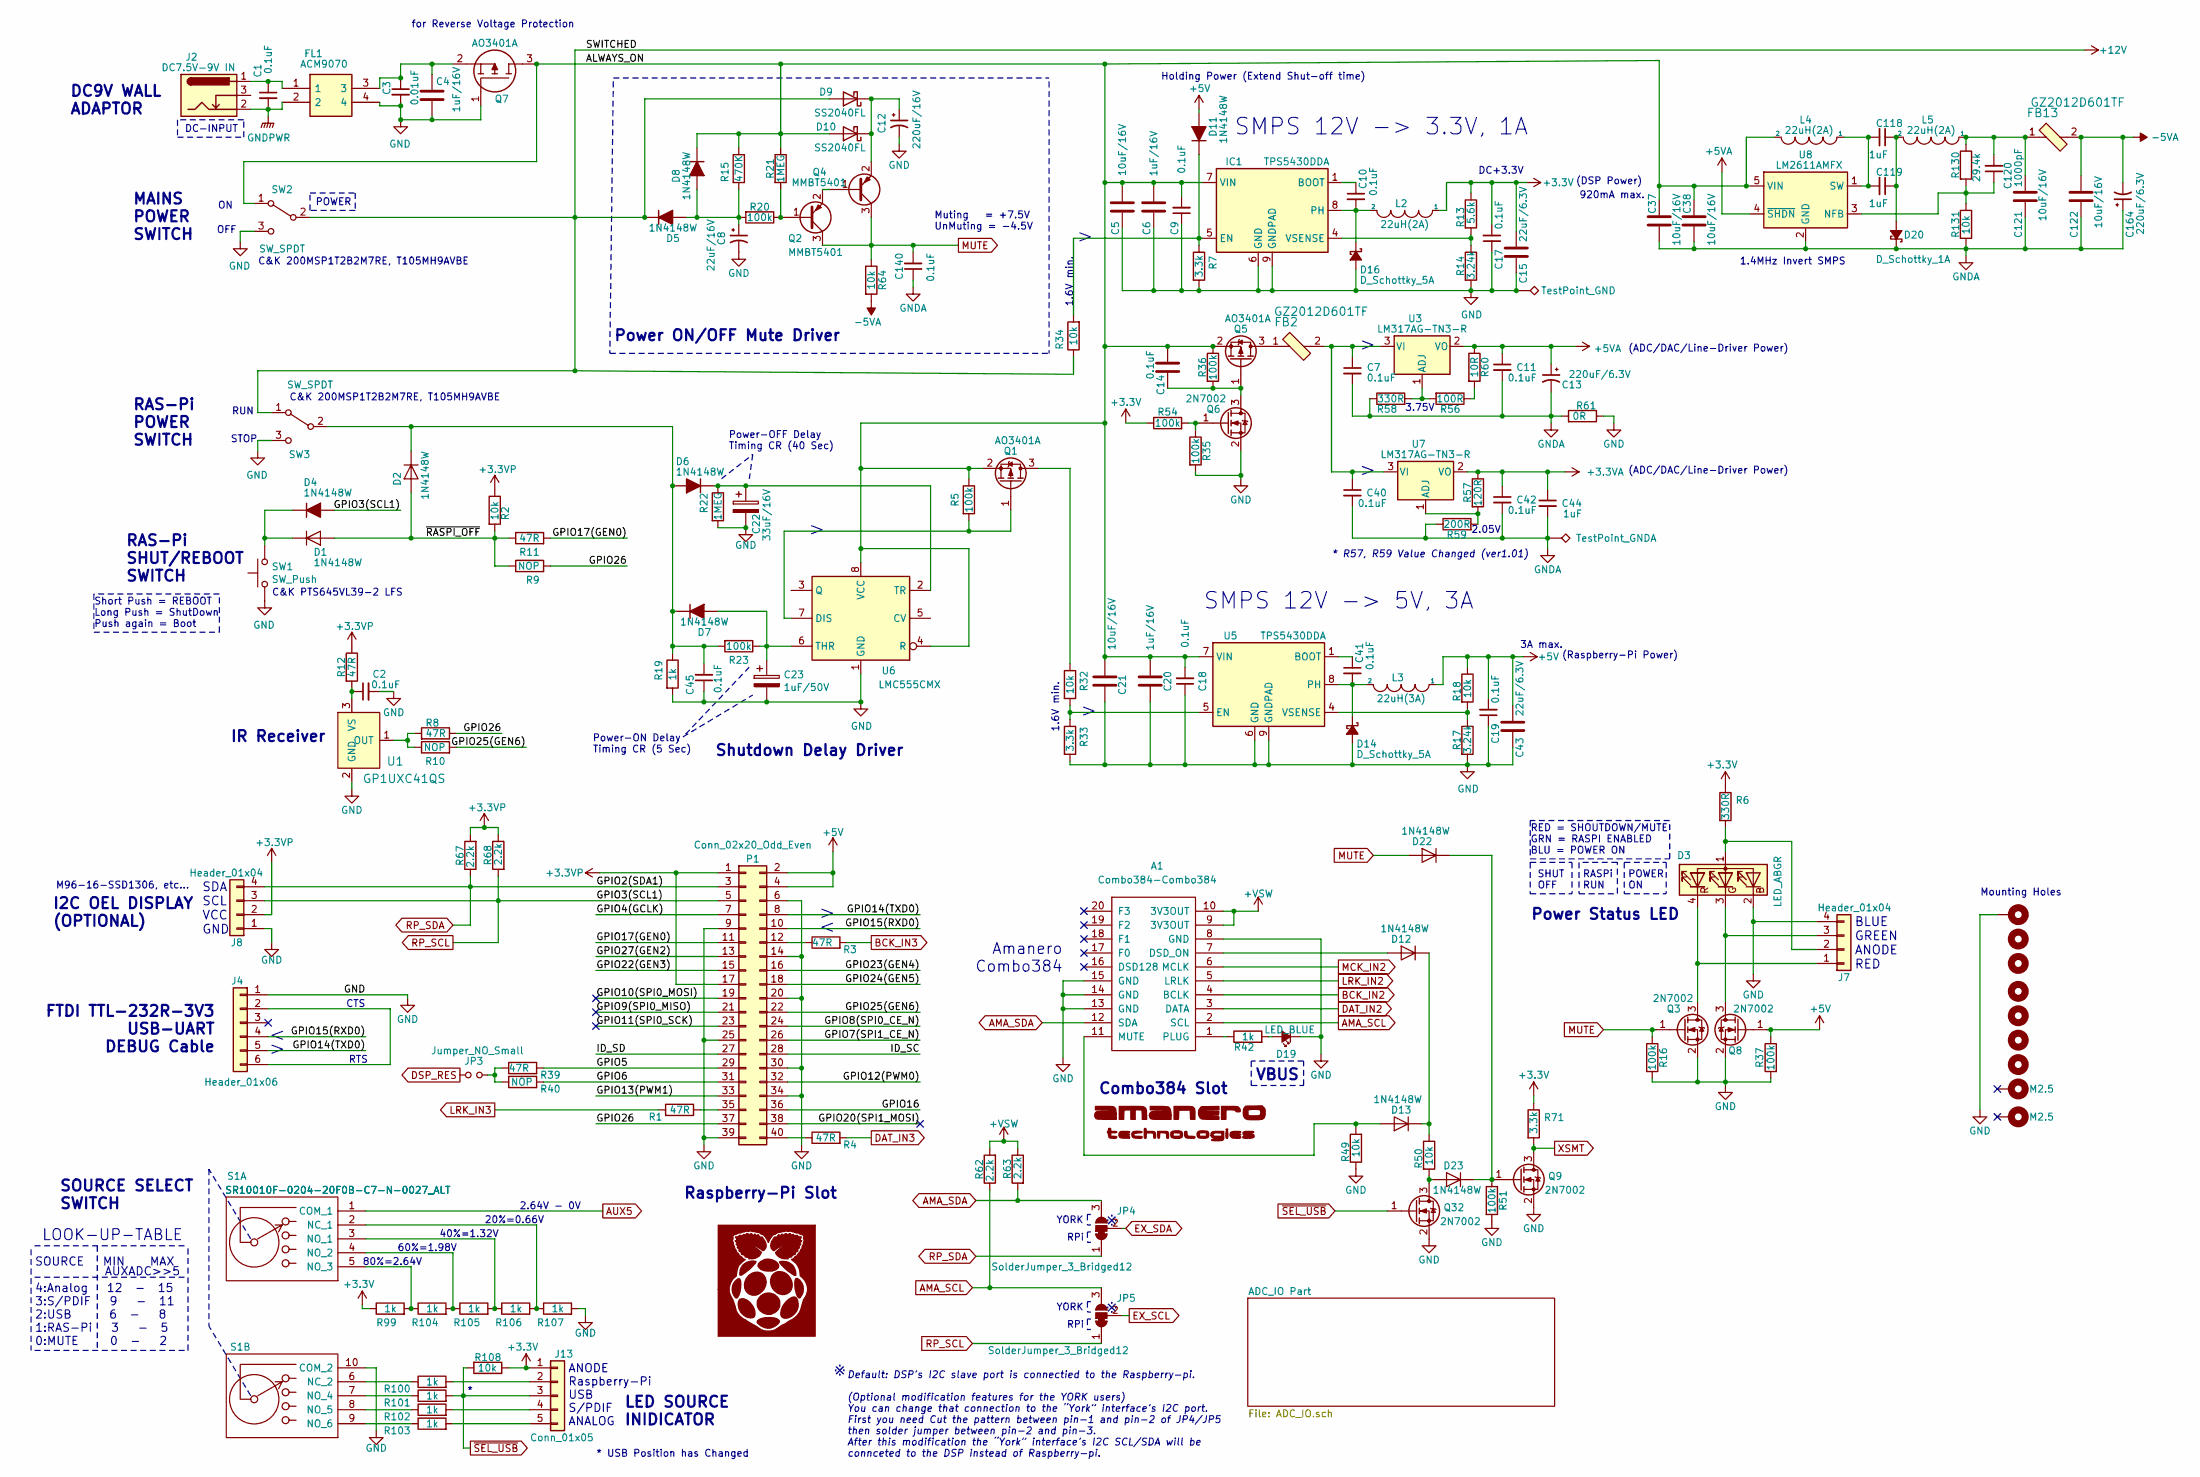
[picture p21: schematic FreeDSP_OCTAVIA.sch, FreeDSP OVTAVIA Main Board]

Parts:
A1: Combo384-Combo384; Combo384
C1, C2, C7, C9, C10, C11, C14, C17, C18, C19, C40, C41, C42, C45, C140: 0.1uF; C_0805_2012Metric_Pad1.18x1.45mm_HandSolder
C3: 0.01uF; C_0805_2012Metric_Pad1.18x1.45mm_HandSolder
C4, C6, C20: 1uF/16V; C_0805_2012Metric_Pad1.18x1.45mm_HandSolder
C5, C21, C37, C38, C121, C122: 10uF/16V; C_0805_2012Metric_Pad1.18x1.45mm_HandSolder
C8: 22uF/16V; CP_Radial_D5.0mm_P2.00mm
C12: 220uF/16V; CP_Radial_D7.5mm_P2.50mm
C13, C164: 220uF/6.3V; CP_Radial_D10.0mm_P2.50mm_P5.00mm
C15, C43: 22uF/6.3V; C_0805_2012Metric_Pad1.18x1.45mm_HandSolder
C22: 33uF/16V; CP_Radial_D5.0mm_P2.00mm
C23: 1uF/50V; C_0805
C44: 1uF; C_0805_2012Metric_Pad1.18x1.45mm_HandSolder
C118, C119: 1uF; C_0603_1608Metric
C120: 1000pF; C_0603_1608Metric
D1, D2, D4, D5, D6, D7, D8, D11, D12, D13, D22, D23: 1N4148W; D_SOD-123
D3: LED_ABGR; LED_0603_ABGR
D9, D10: SS2040FL; D_SOD-123
D14, D16: D_Schottky_5A; D_SMA
D19: LED_BLUE; LED_0603_1608Metric_Castellated
D20: D_Schottky_1A; D_SMA
FB2: GZ2012D601TF; L_0805_2012Metric; MPN BLM18AG601SN1D; Digi-Key_PN 490-1014-1-ND
FB13: GZ2012D601TF; 0805; MPN BLM18AG601SN1D; Digi-Key_PN 490-1014-1-ND
FL1: ACM9070; ACM9070F
IC1: TPS5430DDA; TI_SO-PowerPAD-8_ThermalVias
J2: DC7.5V-9V IN; BarrelJack_Horizontal
J4: Header_01x06; PinHeader_1x06_P2.54mm_Vertical
J7, J8: Header_01x04; PinHeader_1x04_P2.54mm_Vertical
J13: Conn_01x05; PinHeader_1x05_P2.54mm_Vertical
JP3: Jumper_NO_Small; SolderJumper-2_P1.3mm_Open_RoundedPad1.0x1.5mm
JP4, JP5: SolderJumper_3_Bridged12; SolderJumper-3_P1.3mm_Bridged12_Pad1.0x1.5mm_NumberLabels
L2, L4, L5: 22uH(2A); L_Taiyo-Yuden_NR-60xx_HandSoldering
L3: 22uH(3A); L_Taiyo-Yuden_NR-60xx_HandSoldering
MH1: M3; MountingHole_3.2mm_M3_Pad_Via
MH2, MH3, MH4, MH5, MH6, MH7: M3; MountingHole_3.2mm_M3_Pad_TopOnly
MK1, MK2: M2.5; MountingHole_2.5mm
P1: Conn_02x20_Odd_Even; PinSocket_2x20_P2.54mm_Vertical
Q1, Q5, Q7: AO3401A; SOT-23_Handsoldering; Manufacturer_Part_Number DMG3415U-7; Mouser Part Number 621-DMG3415U-7
Q2, Q4: MMBT5401; SOT-23_Handsoldering
Q3, Q6, Q8, Q9, Q32: 2N7002; SOT-23_Handsoldering
R1, R3, R4, R39: 47R; R_0603_1608Metric
R2, R18, R32, R34, R50, R64, R108: 10k; R_0805_2012Metric_Pad1.20x1.40mm_HandSolder
R5, R16, R20, R23, R35, R36, R37, R51, R54: 100k; R_0805_2012Metric_Pad1.20x1.40mm_HandSolder
R6: 330R; R_0805_2012Metric_Pad1.20x1.40mm_HandSolder
R7, R33, R71: 3.3k; R_0805_2012Metric_Pad1.20x1.40mm_HandSolder
R8, R11, R12: 47R; R_0805_2012Metric_Pad1.20x1.40mm_HandSolder
R9, R10: NOP; R_0805_2012Metric_Pad1.20x1.40mm_HandSolder
R13: 5.6k; R_0805_2012Metric_Pad1.20x1.40mm_HandSolder
R14, R17: 3.24k; R_0805_2012Metric_Pad1.20x1.40mm_HandSolder
R15: 470K; R_0805_2012Metric_Pad1.20x1.40mm_HandSolder
R19, R42, R99, R100, R101, R102, R103, R104, R105, R106, R107: 1k; R_0805_2012Metric_Pad1.20x1.40mm_HandSolder
R21, R22: 1MEG; R_0805_2012Metric_Pad1.20x1.40mm_HandSolder
R40: NOP; R_0603_1608Metric
R49, R131: 10k; R_0603_1608Metric
R56: 100R; R_0603_1608Metric
R57: 120R; R_0603_1608Metric
R58: 330R; R_0603_1608Metric
R59: 200R; R_0603_1608Metric
R60: 10R; R_0603_1608Metric
R61: 0R; R_0603_1608Metric
R62, R63, R67, R68: 2.2k; R_0603_1608Metric
R130: 29.4k; R_0603_1608Metric
S1: SR10010F-0204-20F0B-C7-N-0027_ALT; SR10010F020420F0BC7N0027; Manufacturer_Part_Number SR10010F-0204-20F0B-C7-N-0027; Mouser Part Number 105-SR10010F-24NS
SW1: SW_Push; SW_Tactile_SPST_Angled_PTS645Vx83-2LFS
SW2, SW3: SW_SPDT; 2MS1T1B4M7QES
TP1: TestPoint_GNDA; TestPoint_THTPad_2.0x2.0mm_Drill1.0mm
TP2: TestPoint_GND; TestPoint_THTPad_2.0x2.0mm_Drill1.0mm
U1: GP1UXC41QS; IR_Receiver_TSOP38238; MPN TSOP38238; Digi-Key_PN 751-1227-ND
U3, U7: LM317AG-TN3-R; TO-252-2
U5: TPS5430DDA; TI_SO-PowerPAD-8_ThermalVias
U6: LMC555CMX; SOIC-8_3.9x4.9mm_P1.27mm
U8: LM2611AMFX; SOT-23-5
Z2: LOGO; AmaneroLogo
Z3: LOGO; RasPiLogoSmall

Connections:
+3.3VA: C42.1, C44.1, R57.1, U7.2 (VO); also elsewhere on the board
+3.3VP: J8.2, P1.1, P1.17, R2.1, R12.1, R67.2, R68.1
+3V3: C15.1, C17.2, J13.1, L2.1, R6.1, R13.1, R54.1, R71.1, R99.1, R108.1; also elsewhere on the board
+5V: C19.2, C43.1, D11.2 (A), L3.1, P1.2, P1.4, Q8.1 (G), R18.1, R37.1
+5VA: C11.1, C13.1, R60.1, U3.2 (VO), U8.4 (~SHDN); also elsewhere on the board
+12V: D5.1 (K), D9.2 (A), R34.1, SW2.2 (B), SW3.1 (A)
+VSW: A1.9 (3V3OUT), A1.10 (3V3OUT), R62.2, R63.1
-5VA: C122.1, C164.2, FB13.2, R64.2; also elsewhere on the board
/ALWAYS_ON: C5.1, C6.1, C9.2, C14.1, C18.2, C20.1, C21.1, C37.1, C38.1, D8.1 (K), D10.2 (A), IC1.7 (VIN), L4.2, Q1.2 (S), Q5.2 (S), Q7.3, R5.1, R15.1, R21.1, R36.1, SW2.1 (A), U5.7 (VIN), U6.4 (R), U6.8 (VCC), U8.5 (VIN)
/GPIO4(GCLK): P1.7
/GPIO5: P1.29, R39.2
/GPIO6: P1.31, R40.2
/GPIO7(SPI1_CE_N): P1.26
/GPIO8(SPI0_CE_N): P1.24
/GPIO9(SPI0_MISO): P1.21
/GPIO10(SPI0_MOSI): P1.19
/GPIO11(SPI0_SCK): P1.23
/GPIO12(PWM0): P1.32
/GPIO13(PWM1): P1.33
/GPIO14(TXD0): J4.5, P1.8
/GPIO15(RXD0): J4.4, P1.10
/GPIO16: P1.36
/GPIO17(GEN0): P1.11, R11.2
/GPIO20(SPI1_MOSI): P1.38
/GPIO22(GEN3): P1.15
/GPIO23(GEN4): P1.16
/GPIO24(GEN5): P1.18
/GPIO25(GEN6): P1.22, R10.2
/GPIO26: P1.37, R8.1, R9.2
/GPIO27(GEN2): P1.13
/ID_SC: P1.28
/ID_SD: P1.27
/~RASPI_OFF: D1.2 (A), D2.2 (A), R2.2, R9.1, R11.1
AMA_SCL: A1.2 (SCL), JP5.3 (B), R62.1
AMA_SDA: A1.12 (SDA), JP4.3 (B), R63.2
AUX5: S1.1 (COM_1); also elsewhere on the board
BCK_IN2: A1.4 (BCLK); also elsewhere on the board
BCK_IN3: R3.2; also elsewhere on the board
DAT_IN2: A1.3 (DATA); also elsewhere on the board
DAT_IN3: R4.2; also elsewhere on the board
DSP_RES: JP3.1; also elsewhere on the board
EX_SCL: JP5.2 (C); also elsewhere on the board
EX_SDA: JP4.2 (C); also elsewhere on the board
GND: A1.8 (GND), A1.13 (GND), A1.14 (GND), A1.15 (GND), C2.2, C3.2, C4.1, C5.2, C6.2, C8.2, C9.1, C12.2, C15.2, C17.1, C18.1, C19.1, C20.2, C21.2, C22.2, C23.2, C43.2, C45.1, D3.2 (BK), D14.2 (A), D16.2 (A), D19.1 (K), FL1.4, IC1.6 (GND), IC1.9 (GNDPAD), J4.1, J7.4, J8.1, MH1.1, P1.6, P1.9, P1.14, P1.20, P1.25, P1.30, P1.34, P1.39, Q3.2 (S), Q6.2 (S), Q7.1, Q8.2 (S), Q9.2 (S), Q32.2 (S), R7.2, R14.2, R16.2, R17.2, R19.2, R22.2, R33.2, R35.2, R37.2, R49.1, R51.2, R61.1, R107.2, S1.10 (COM_2), SW1.1, SW2.3 (C), SW3.3 (C), TP2.1, U1.2 (GND), U5.6 (GND), U5.9 (GNDPAD), U6.1 (GND); also elsewhere on the board
GNDA: C7.2, C11.2, C13.2, C37.2, C38.2, C40.2, C42.2, C44.2, C121.2, C122.2, C140.1, C164.1, D20.1 (K), R58.1, R59.1, R61.2, R131.2, TP1.1, U8.2 (GND); also elsewhere on the board
GNDPWR: C1.2, FL1.2, J2.2
LRK_IN2: A1.5 (LRLK); also elsewhere on the board
LRK_IN3: R1.2; also elsewhere on the board
MCK_IN2: A1.6 (MCLK)
MUTE: C140.2, D22.2 (A), Q2.3 (C), Q3.1 (G), Q4.3 (C), R16.1, R64.1; also elsewhere on the board
unnamed: A1.1 (PLUG), R42.1
unnamed: A1.7 (DSD_ON), D12.2 (A)
unnamed: A1.11 (MUTE), D13.2 (A), R49.2
unnamed: C1.1, FL1.1, J2.1
unnamed: C2.1, R12.2, U1.3 (VS)
unnamed: C3.1, C4.2, FL1.3, Q7.2
unnamed: C8.1, D5.2 (A), D8.2 (A), R15.2, R20.2
unnamed: C10.1, IC1.1 (BOOT)
unnamed: C10.2, D16.1 (K), IC1.8 (PH), L2.2
unnamed: C12.1, D9.1 (K), D10.1 (K), Q4.2 (E)
unnamed: C14.2, Q5.1 (G), Q6.3 (D), R36.2
unnamed: C22.1, D6.1 (K), R22.1, U6.2 (TR)
unnamed: C23.1, D7.2 (A), R23.1, U6.6 (THR)
unnamed: C7.1, C40.1, FB2.2, U3.3 (VI), U7.3 (VI)
unnamed: C41.1, U5.1 (BOOT)
unnamed: C41.2, D14.1 (K), L3.2, U5.8 (PH)
unnamed: C45.2, D2.1 (K), D6.2 (A), D7.1 (K), R19.1, R23.2, SW3.2 (B)
unnamed: C118.1, C119.1, D20.2 (A), L5.2
unnamed: C118.2, C119.2, L4.1, U8.1 (SW)
unnamed: C120.1, R130.2, R131.1, U8.3 (NFB)
unnamed: C120.2, C121.1, FB13.1, L5.1, R130.1
unnamed: D1.1 (K), D4.1 (K), SW1.2
unnamed: D3.1 (A), J7.2, R6.2
unnamed: D3.3 (GK), J7.3, Q8.3 (D)
unnamed: D3.4 (RK), J7.1, Q3.3 (D)
unnamed: D11.1 (K), IC1.5 (EN), R7.1, R34.2
unnamed: D12.1 (K), D13.1 (K), R50.1
unnamed: D19.2 (A), R42.2
unnamed: D22.1 (K), D23.1 (K), Q9.1 (G), R51.1
unnamed: D23.2 (A), Q32.3 (D), R50.2
unnamed: FB2.1, Q5.3 (D)
unnamed: IC1.4 (VSENSE), R13.2, R14.1
unnamed: J4.2, J4.6
unnamed: J13.2, R100.2
unnamed: J13.4, R102.2
unnamed: J13.5, R103.2
unnamed: JP3.2, R39.1, R40.1
unnamed: P1.12, R3.1
unnamed: P1.35, R1.1
unnamed: P1.40, R4.1
unnamed: Q1.1 (G), R5.2, U6.7 (DIS)
unnamed: Q1.3 (D), R32.1
unnamed: Q2.1 (B), R20.1, R21.2
unnamed: Q2.2 (E), Q4.1 (B)
unnamed: Q6.1 (G), R35.1, R54.2
unnamed: R8.2, R10.1, U1.1 (OUT)
unnamed: R17.1, R18.2, U5.4 (VSENSE)
unnamed: R32.2, R33.1, U5.5 (EN)
unnamed: R56.1, R60.2
unnamed: R56.2, R58.2, U3.1 (ADJ)
unnamed: R57.2, R59.2, U7.1 (ADJ)
unnamed: R100.1, S1.6 (NC_2)
unnamed: R101.1, S1.7 (NO_4)
unnamed: R102.1, S1.8 (NO_5)
unnamed: R103.1, S1.9 (NO_6)
unnamed: R99.2, R104.1, S1.5 (NO_3)
unnamed: R104.2, R105.1, S1.4 (NO_2)
unnamed: R105.2, R106.1, S1.3 (NO_1)
unnamed: R106.2, R107.1, S1.2 (NC_1)
RP_SCL: D4.2 (A), J8.3, JP5.1 (A), P1.5, R68.2
RP_SDA: J8.4, JP4.1 (A), P1.3, R67.1
XSMT: Q9.3 (D), R71.2; also elsewhere on the board
~SEL_USB: J13.3, Q32.1 (G), R101.2, R108.2

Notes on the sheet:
Mounting Holes
OFF
POWER
DC+3.3V
SMPS 12V -> 3.3V, 1A
RAS-Pi POWER SWITCH
Power-OFF Delay Timing CR (40 Sec)
Power-ON Delay Timing CR (5 Sec)
(Raspberry-Pi Power)
RAS-Pi SHUT/REBOOT SWITCH
Raspberry-Pi Slot
FTDI TTL-232R-3V3 USB-UART DEBUG Cable
CTS
Power ON/OFF Mute Driver
IR Receiver
RTS
RUN
STOP
MAINS POWER SWITCH
(DSP Power)
(ADC/DAC/Line-Driver Power)
I2C OEL DISPLAY (OPTIONAL)
920mA max.
SMPS 12V -> 5V, 3A
3A max.
DC-INPUT
DC9V WALL ADAPTOR
POWER ON
RASPi RUN
Short Push = REBOOT Long Push = ShutDown Push again = Boot
SHUT OFF
1.6V min.
M96-16-SSD1306, etc…
Shutdown Delay Driver
Holding Power (Extend Shut-off time)
for Reverse Voltage Protection
Amanero Combo384
Combo384 Slot
SOURCE SELECT SWITCH
80%=2.64V

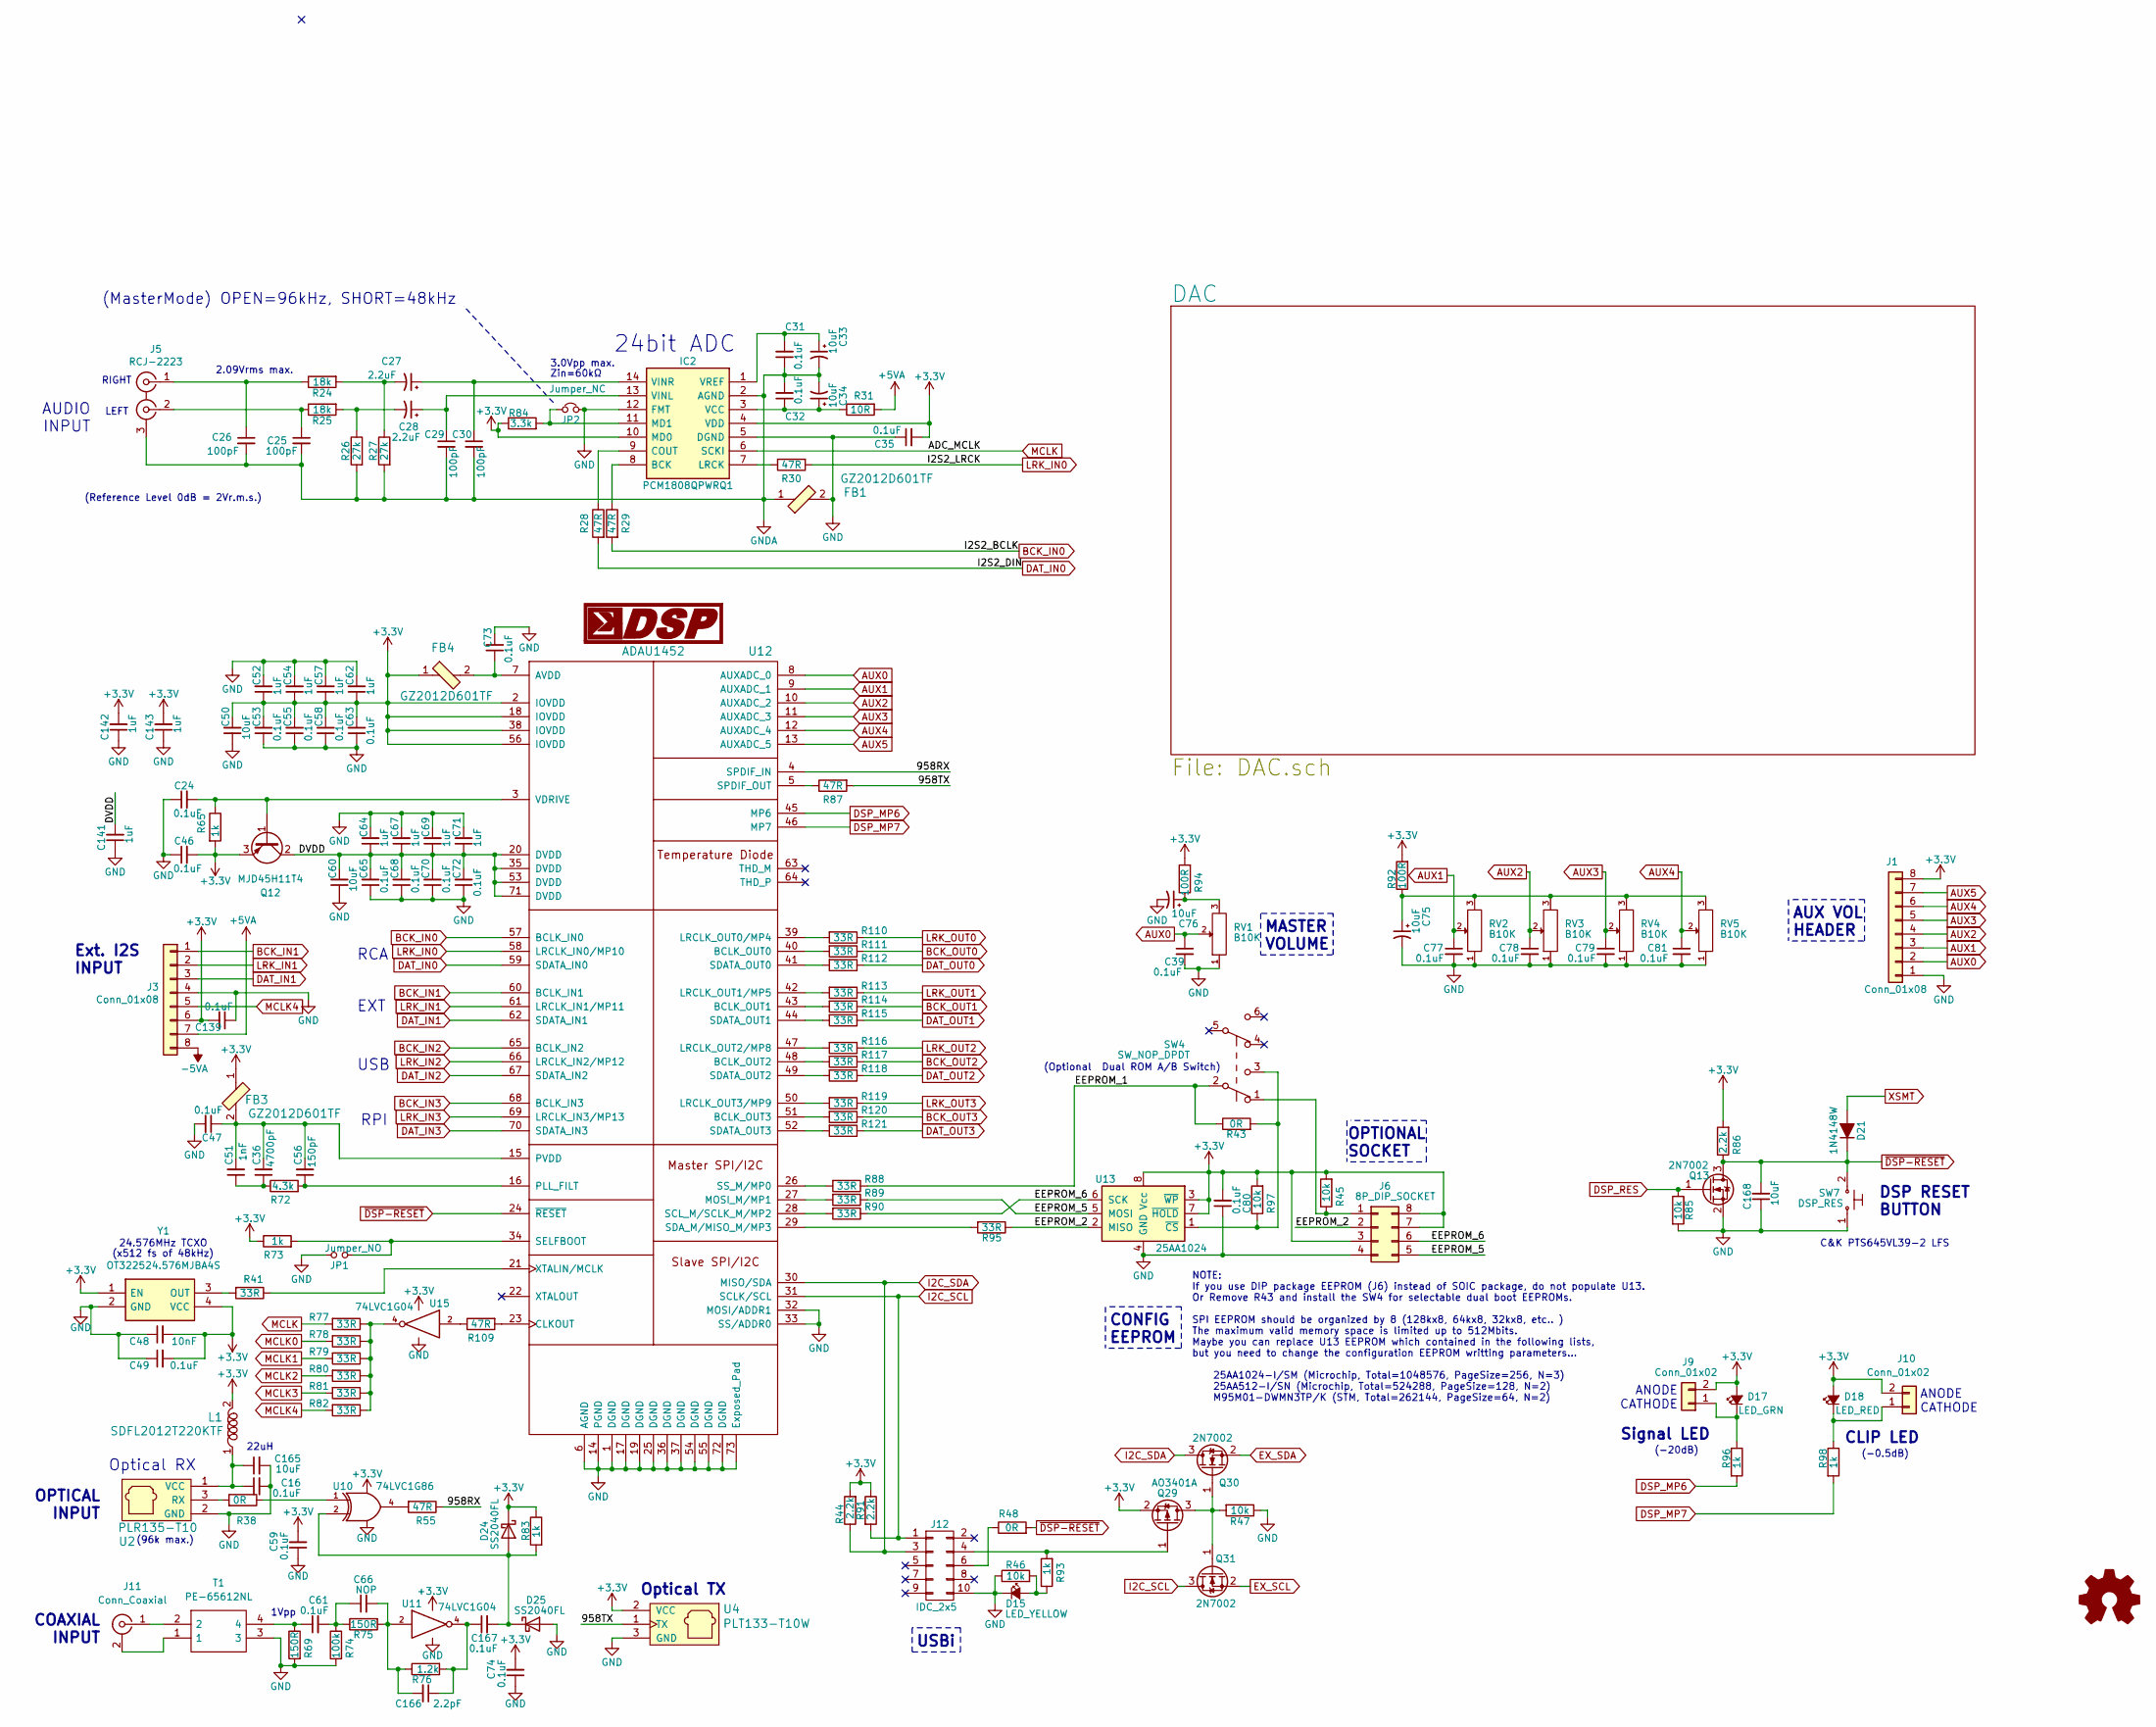
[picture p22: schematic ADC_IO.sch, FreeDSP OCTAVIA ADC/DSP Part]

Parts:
C16, C32, C35, C49, C53, C55, C58, C59, C61, C63, C65, C68, C70, C72, C73, C74, C80, C139, C167: 0.1uF; C_0603_1608Metric
C24, C39, C46, C47, C77, C78, C79, C81: 0.1uF; C_0805_2012Metric_Pad1.18x1.45mm_HandSolder
C25, C26, C29, C30: 100pF; C_0805_2012Metric_Pad1.18x1.45mm_HandSolder
C27, C28: 2.2uF; CP_Radial_D5.0mm_P2.00mm
C31: 0.1uF; C_0603_1608Metric_Pad1.08x0.95mm_HandSolder
C33, C60, C75, C76, C168: 10uF; C_0805_2012Metric_Pad1.18x1.45mm_HandSolder
C34, C50, C165: 10uF; C_0603_1608Metric
C36: 4700pF; C_0805_2012Metric_Pad1.18x1.45mm_HandSolder
C48: 10nF; C_0603_1608Metric
C51: 1nF; C_0805_2012Metric_Pad1.18x1.45mm_HandSolder
C52, C54, C57, C62, C64, C67, C69, C71: 1uF; C_0603_1608Metric
C56: 150pF; C_0805_2012Metric_Pad1.18x1.45mm_HandSolder
C66: NOP; C_0805_2012Metric_Pad1.18x1.45mm_HandSolder
C141, C142, C143: 1uF; C_0805_2012Metric_Pad1.18x1.45mm_HandSolder
C166: 2.2pF; C_0402_1005Metric_Pad0.74x0.62mm_HandSolder
D15: LED_YELLOW; LED_0603_1608Metric_Castellated
D17: LED_GRN; LED_0603_1608Metric_Castellated
D18: LED_RED; LED_0603_1608Metric_Castellated
D21: 1N4148W; D_SOD-123
D24, D25: SS2040FL; D_SOD-123
FB1: GZ2012D601TF; 0805; MPN BLM21PG331SN1D; Digi-Key_PN 490-5988-1-ND
FB3, FB4: GZ2012D601TF; 0805; MPN BLM18AG601SN1D; Digi-Key_PN 490-1014-1-ND
IC2: PCM1808QPWRQ1; Manufacturer_Part_Number PCM1808QPWRQ1
J1, J3: Conn_01x08; PinHeader_1x08_P2.54mm_Vertical
J5: RCJ-2223
J6: 8P_DIP_SOCKET; DIP-8_W7.62mm_Socket
J9, J10: Conn_01x02; PinHeader_1x02_P2.54mm_Vertical
J11: Conn_Coaxial; RJ-2410N
J12: IDC_2x5; IDC-Header_2x05_P2.54mm_Horizontal
JP1: Jumper_NO; SolderJumper-2_P1.3mm_Open_RoundedPad1.0x1.5mm
JP2: Jumper_NC; SolderJumper-2_P1.3mm_Bridged_RoundedPad1.0x1.5mm
L1: SDFL2012T220KTF; L_0805_2012Metric_Pad1.15x1.40mm_HandSolder; MPN 82473C; Digi-Key_PN 811-2477-1-ND
LOGO1: Logo_Open_Hardware_Small; LOGO_FREEDSP_600dpi
Q12: MJD45H11T4; TO-252-2
Q13, Q30, Q31: 2N7002; SOT-23_Handsoldering
Q29: AO3401A; SOT-23_Handsoldering; Manufacturer_Part_Number DMG3415U-7; Mouser Part Number 621-DMG3415U-7
R24, R25: 18k; R_0805_2012Metric_Pad1.20x1.40mm_HandSolder
R26, R27: 27k; R_0805_2012Metric_Pad1.20x1.40mm_HandSolder
R28, R29, R30, R55, R87, R109: 47R; R_0603_1608Metric
R31: 10R; R_0603_1608Metric
R38: 0R; R_0603_1608Metric
R41, R77, R78, R79, R80, R81, R82, R88, R89, R90, R95, R110, R111, R112, R113, R114, R115, R116, R117, R118, R119, R120, R121: 33R; R_0603_1608Metric
R43, R48: 0R; R_0805_2012Metric_Pad1.20x1.40mm_HandSolder
R44, R86, R91: 2.2k; R_0603_1608Metric
R45, R46, R47, R85, R97: 10k; R_0603_1608Metric
R65, R93, R96, R98: 1k; R_0805_2012Metric_Pad1.20x1.40mm_HandSolder
R69, R75: 150R; R_0603_1608Metric
R72: 4.3k; R_0805_2012Metric_Pad1.20x1.40mm_HandSolder
R73, R83: 1k; R_0603_1608Metric
R74: 100k; R_0603_1608Metric
R76: 1.2k; R_0603_1608Metric
R84: 3.3k; R_0603_1608Metric
R92, R94: 100R; R_0805_2012Metric_Pad1.20x1.40mm_HandSolder
RV1, RV2, RV3, RV4, RV5: B10K; RK09L12B0A31
SW4: SW_NOP_DPDT; SW_CuK_JS202011AQN_DPDT_Angled
SW7: DSP_RES; SW_Tactile_SPST_Angled_PTS645Vx83-2LFS
T1: PE-65612NL; PE65612NL; Manufacturer_Part_Number PE-65612NL; Mouser Part Number 673-PE-65612NL
U2: PLR135-T10
U4: PLT133-T10W
U10: 74LVC1G86; SOT-23-5_HandSoldering
U11, U15: 74LVC1G04; SOT-23-5_HandSoldering
U12: ADAU1452; LFCSP-72-1EP_10x10mm_P0.5mm_EP5.3x5.3mmL_HandSolder
U13: 25AA1024; SOIC-8_5.275x5.275mm_P1.27mm
Y1: OT322524.576MJBA4S; Crystal_SMD_TXC_7M-4pin_3.2x2.5mm_HandSoldering; Manufacturer_Part_Number KC7050K50.0000C1GE00
Z1: LOGO; SigmaDSP-LogoSmall

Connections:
+3V3: C35.2, C46.2, C48.2, C49.2, C50.2, C52.1, C53.2, C54.1, C55.2, C57.1, C58.2, C59.2, C62.1, C63.2, C74.2, C80.2, C139.2, C142.2, C143.2, D17.2 (A), D18.2 (A), D24.1 (K), FB3.1, FB4.1, IC2.4 (VDD), IC2.10 (MD0), J1.8, J3.6, J6.3, J6.7, J6.8, J9.2, J10.2, L1.2, Q12.3 (E), Q29.2 (S), R44.2, R45.2, R65.2, R73.1, R83.1, R84.1, R86.2, R91.1, R92.2, R94.2, R97.2, U4.2 (VCC), U10.5 (VCC), U11.5 (VCC), U12.2 (IOVDD), U12.18 (IOVDD), U12.38 (IOVDD), U12.56 (IOVDD), U13.3 (~WP), U13.7 (~HOLD), U13.8 (Vcc), U15.5 (VCC), Y1.1 (EN), Y1.4 (VCC); also elsewhere on the board
+5VA: J3.7, R31.2; also elsewhere on the board
-5VA: J3.8; also elsewhere on the board
/ADC_IO Part/958RX: R55.1, U12.4 (SPDIF_IN)
/ADC_IO Part/958TX: R87.2, U4.1 (TX)
/ADC_IO Part/DVDD: C60.2, C64.1, C65.2, C67.1, C68.2, C69.1, C70.2, C71.1, C72.2, C141.2, Q12.2 (C), U12.20 (DVDD), U12.35 (DVDD), U12.53 (DVDD), U12.71 (DVDD)
/ADC_IO Part/EEPROM_1: R43.1, R88.1, SW4.2 (B)
/ADC_IO Part/EEPROM_2: J6.2, R95.1, U13.2 (MISO)
/ADC_IO Part/EEPROM_5: J6.5, R89.1, U13.5 (MOSI)
/ADC_IO Part/EEPROM_6: J6.6, R90.1, U13.6 (SCK)
AUX0: C39.1, J1.2, RV1.2, U12.8 (AUXADC_0)
AUX1: C77.1, J1.3, RV2.2, U12.9 (AUXADC_1)
AUX2: C78.1, J1.4, RV3.2, U12.10 (AUXADC_2)
AUX3: C79.1, J1.5, RV4.2, U12.11 (AUXADC_3)
AUX4: C81.1, J1.6, RV5.2, U12.12 (AUXADC_4)
AUX5: J1.7, U12.13 (AUXADC_5); also elsewhere on the board
BCK_IN0: R29.2, U12.57 (BCLK_IN0)
BCK_IN1: J3.1, U12.60 (BCLK_IN1)
BCK_IN2: U12.65 (BCLK_IN2); also elsewhere on the board
BCK_IN3: U12.68 (BCLK_IN3); also elsewhere on the board
BCK_OUT0: R111.1; also elsewhere on the board
BCK_OUT1: R114.1; also elsewhere on the board
BCK_OUT2: R117.1; also elsewhere on the board
BCK_OUT3: R120.1; also elsewhere on the board
DAT_IN0: R28.2, U12.59 (SDATA_IN0)
DAT_IN1: J3.3, U12.62 (SDATA_IN1)
DAT_IN2: U12.67 (SDATA_IN2); also elsewhere on the board
DAT_IN3: U12.70 (SDATA_IN3); also elsewhere on the board
DAT_OUT0: R112.1; also elsewhere on the board
DAT_OUT1: R115.1; also elsewhere on the board
DAT_OUT2: R118.1; also elsewhere on the board
DAT_OUT3: R121.1; also elsewhere on the board
DSP_MP6: R96.2, U12.45 (MP6)
DSP_MP7: R98.2, U12.46 (MP7)
DSP_RES: Q13.1 (G), R85.1; also elsewhere on the board
EX_SCL: Q31.2 (S); also elsewhere on the board
EX_SDA: Q30.2 (S); also elsewhere on the board
GND: C16.2, C24.1, C35.1, C39.2, C46.1, C47.2, C48.1, C49.1, C50.1, C52.2, C53.1, C54.2, C55.1, C57.2, C58.1, C59.1, C60.1, C62.2, C63.1, C64.2, C65.1, C67.2, C68.1, C69.2, C70.1, C71.2, C72.1, C73.2, C74.1, C75.2, C76.2, C77.2, C78.2, C79.2, C80.1, C81.2, C139.1, C141.1, C142.1, C143.1, C165.2, C168.1, D15.1 (K), D25.2 (A), FB1.2, IC2.5 (DGND), IC2.12 (FMT), J1.1, J3.4, J6.4, J12.10, JP1.1, JP2.2, Q13.2 (S), R46.1, R47.1, R69.2, R74.2, R85.2, RV1.1, RV2.1, RV3.1, RV4.1, RV5.1, SW7.1, T1.3, U2.2 (GND), U4.3 (GND), U10.3 (GND), U11.3 (GND), U12.1 (DGND), U12.6 (AGND), U12.14 (PGND), U12.17 (DGND), U12.19 (DGND), U12.25 (DGND), U12.32 (MOSI/ADDR1), U12.33 (SS/ADDR0), U12.36 (DGND), U12.37 (DGND), U12.54 (DGND), U12.55 (DGND), U12.72 (DGND), U12.73 (Exposed_Pad), U13.4 (GND), U15.3 (GND), Y1.2 (GND); also elsewhere on the board
GNDA: C25.2, C26.2, C29.2, C30.2, C31.1, C32.2, C33.2, C34.2, FB1.1, IC2.2 (AGND), J5.3 (EXT), R26.2, R27.2; also elsewhere on the board
I2C_SCL: J12.1, Q31.3 (D), R91.2, U12.31 (SCLK/SCL)
I2C_SDA: J12.3, Q30.3 (D), R44.1, U12.30 (MISO/SDA)
LRK_IN0: R30.2, U12.58 (LRCLK_IN0/MP10)
LRK_IN1: J3.2, U12.61 (LRCLK_IN1/MP11)
LRK_IN2: U12.66 (LRCLK_IN2/MP12); also elsewhere on the board
LRK_IN3: U12.69 (LRCLK_IN3/MP13); also elsewhere on the board
LRK_OUT0: R110.1; also elsewhere on the board
LRK_OUT1: R113.1; also elsewhere on the board
LRK_OUT2: R116.1; also elsewhere on the board
LRK_OUT3: R119.1; also elsewhere on the board
MCLK: IC2.6 (SCKI), R77.2
MCLK0: R78.2; also elsewhere on the board
MCLK1: R79.2; also elsewhere on the board
MCLK2: R80.2; also elsewhere on the board
MCLK3: R81.2; also elsewhere on the board
MCLK4: J3.5, R82.2
unnamed: C16.1, C165.1, L1.1, U2.1 (VCC)
unnamed: C24.2, Q12.1 (B), R65.1, U12.3 (VDRIVE)
unnamed: C25.1, J5.2 (IN2), R25.1
unnamed: C26.1, J5.1 (IN1), R24.1
unnamed: C27.1, C30.1, IC2.14 (VINR)
unnamed: C27.2, R24.2, R27.1
unnamed: C28.1, C29.1, IC2.13 (VINL)
unnamed: C28.2, R25.2, R26.1
unnamed: C31.2, C33.1, IC2.1 (VREF)
unnamed: C32.1, C34.1, IC2.3 (VCC), R31.1
unnamed: C36.1, C51.1, R72.1
unnamed: C36.2, C47.1, C51.2, C56.2, FB3.2, U12.15 (PVDD)
unnamed: C56.1, R72.2, U12.16 (PLL_FILT)
unnamed: C61.1, R69.1, T1.4
unnamed: C61.2, C66.1, R74.1, R75.1
unnamed: C73.1, FB4.2, U12.7 (AVDD)
unnamed: C75.1, R92.1, RV2.3, RV3.3, RV4.3, RV5.3
unnamed: C76.1, R94.1, RV1.3
unnamed: C166.1, C167.1, R76.2, U11.4
unnamed: C66.2, C166.2, R75.2, R76.1, U11.2
unnamed: C167.2, D24.2 (A), D25.1 (K), R83.2, U10.2
unnamed: D15.2 (A), R46.2, R93.1
unnamed: D17.1 (K), J9.1, R96.1
unnamed: D18.1 (K), J10.1, R98.1
unnamed: IC2.7 (LRCK), R30.1
unnamed: IC2.8 (BCK), R29.1
unnamed: IC2.9 (COUT), R28.1
unnamed: IC2.11 (MD1), JP2.1, R84.2
unnamed: J6.1, R45.1, SW4.1 (A)
unnamed: J11.1 (In), T1.2
unnamed: J11.2 (Ext), T1.1
unnamed: J12.4, Q29.1 (G), R93.2
unnamed: J12.6, R48.1
unnamed: JP1.2, R73.2, U12.34 (SELFBOOT)
unnamed: Q29.3 (D), Q30.1 (G), Q31.1 (G), R47.2
unnamed: R38.1, U10.1
unnamed: R38.2, U2.3 (RX)
unnamed: R41.1, U12.21 (XTALIN/MCLK)
unnamed: R41.2, Y1.3 (OUT)
unnamed: R43.2, R97.1, SW4.3 (C), U13.1 (~CS)
unnamed: R55.2, U10.4
unnamed: R77.1, R78.1, R79.1, R80.1, R81.1, R82.1, U15.4
unnamed: R87.1, U12.5 (SPDIF_OUT)
unnamed: R88.2, U12.26 (SS_M/MP0)
unnamed: R89.2, U12.27 (MOSI_M/MP1)
unnamed: R90.2, U12.28 (SCL_M/SCLK_M/MP2)
unnamed: R95.2, U12.29 (SDA_M/MISO_M/MP3)
unnamed: R109.1, U15.2
unnamed: R109.2, U12.23 (CLKOUT)
unnamed: R110.2, U12.39 (LRCLK_OUT0/MP4)
unnamed: R111.2, U12.40 (BCLK_OUT0)
unnamed: R112.2, U12.41 (SDATA_OUT0)
unnamed: R113.2, U12.42 (LRCLK_OUT1/MP5)
unnamed: R114.2, U12.43 (BCLK_OUT1)
unnamed: R115.2, U12.44 (SDATA_OUT1)
unnamed: R116.2, U12.47 (LRCLK_OUT2/MP8)
unnamed: R117.2, U12.48 (BCLK_OUT2)
unnamed: R118.2, U12.49 (SDATA_OUT2)
unnamed: R119.2, U12.50 (LRCLK_OUT3/MP9)
unnamed: R120.2, U12.51 (BCLK_OUT3)
unnamed: R121.2, U12.52 (SDATA_OUT3)
XSMT: D21.2 (A); also elsewhere on the board
~DSP-RESET: C168.2, D21.1 (K), Q13.3 (D), R48.2, R86.1, SW7.2, U12.24 (~RESET)

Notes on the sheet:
(MasterMode) OPEN=96kHz, SHORT=48kHz
AUDIO INPUT
24bit ADC
(Reference Level 0dB = 2Vr.m.s.)
3.0Vpp max.
Zin=60kΩ
2.09Vrms max.
Optical TX
(96k max.)
OPTICAL INPUT
22uH
Optical RX
Ext. I2S INPUT
Signal LED
CLIP LED
(-20dB)
(-0.5dB)
DSP RESET BUTTON
USBi
MASTER VOLUME
24.576MHz TCXO
AUX VOL HEADER
CONFIG EEPROM
OPTIONAL SOCKET
USB
RPI
EXT
RCA
NOTE: If you use DIP package EEPROM (J6) instead of SOIC package, do not populate U13. Or Remove R43 and install the SW4 for selectable dual boot EEPROMs. SPI EEPROM should be organized by 8 (128kx8, 64kx8, 32kx8, etc.. ) The maximum valid memory space is limited up to 512Mbits. Maybe you can repla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
ANODE CATHODE
RIGHT
LEFT
COAXIAL INPUT
1Vpp
(x512 fs of 48kHz)
(Optional Dual ROM A/B Switch)
C&K PTS645VL39-2 LFS

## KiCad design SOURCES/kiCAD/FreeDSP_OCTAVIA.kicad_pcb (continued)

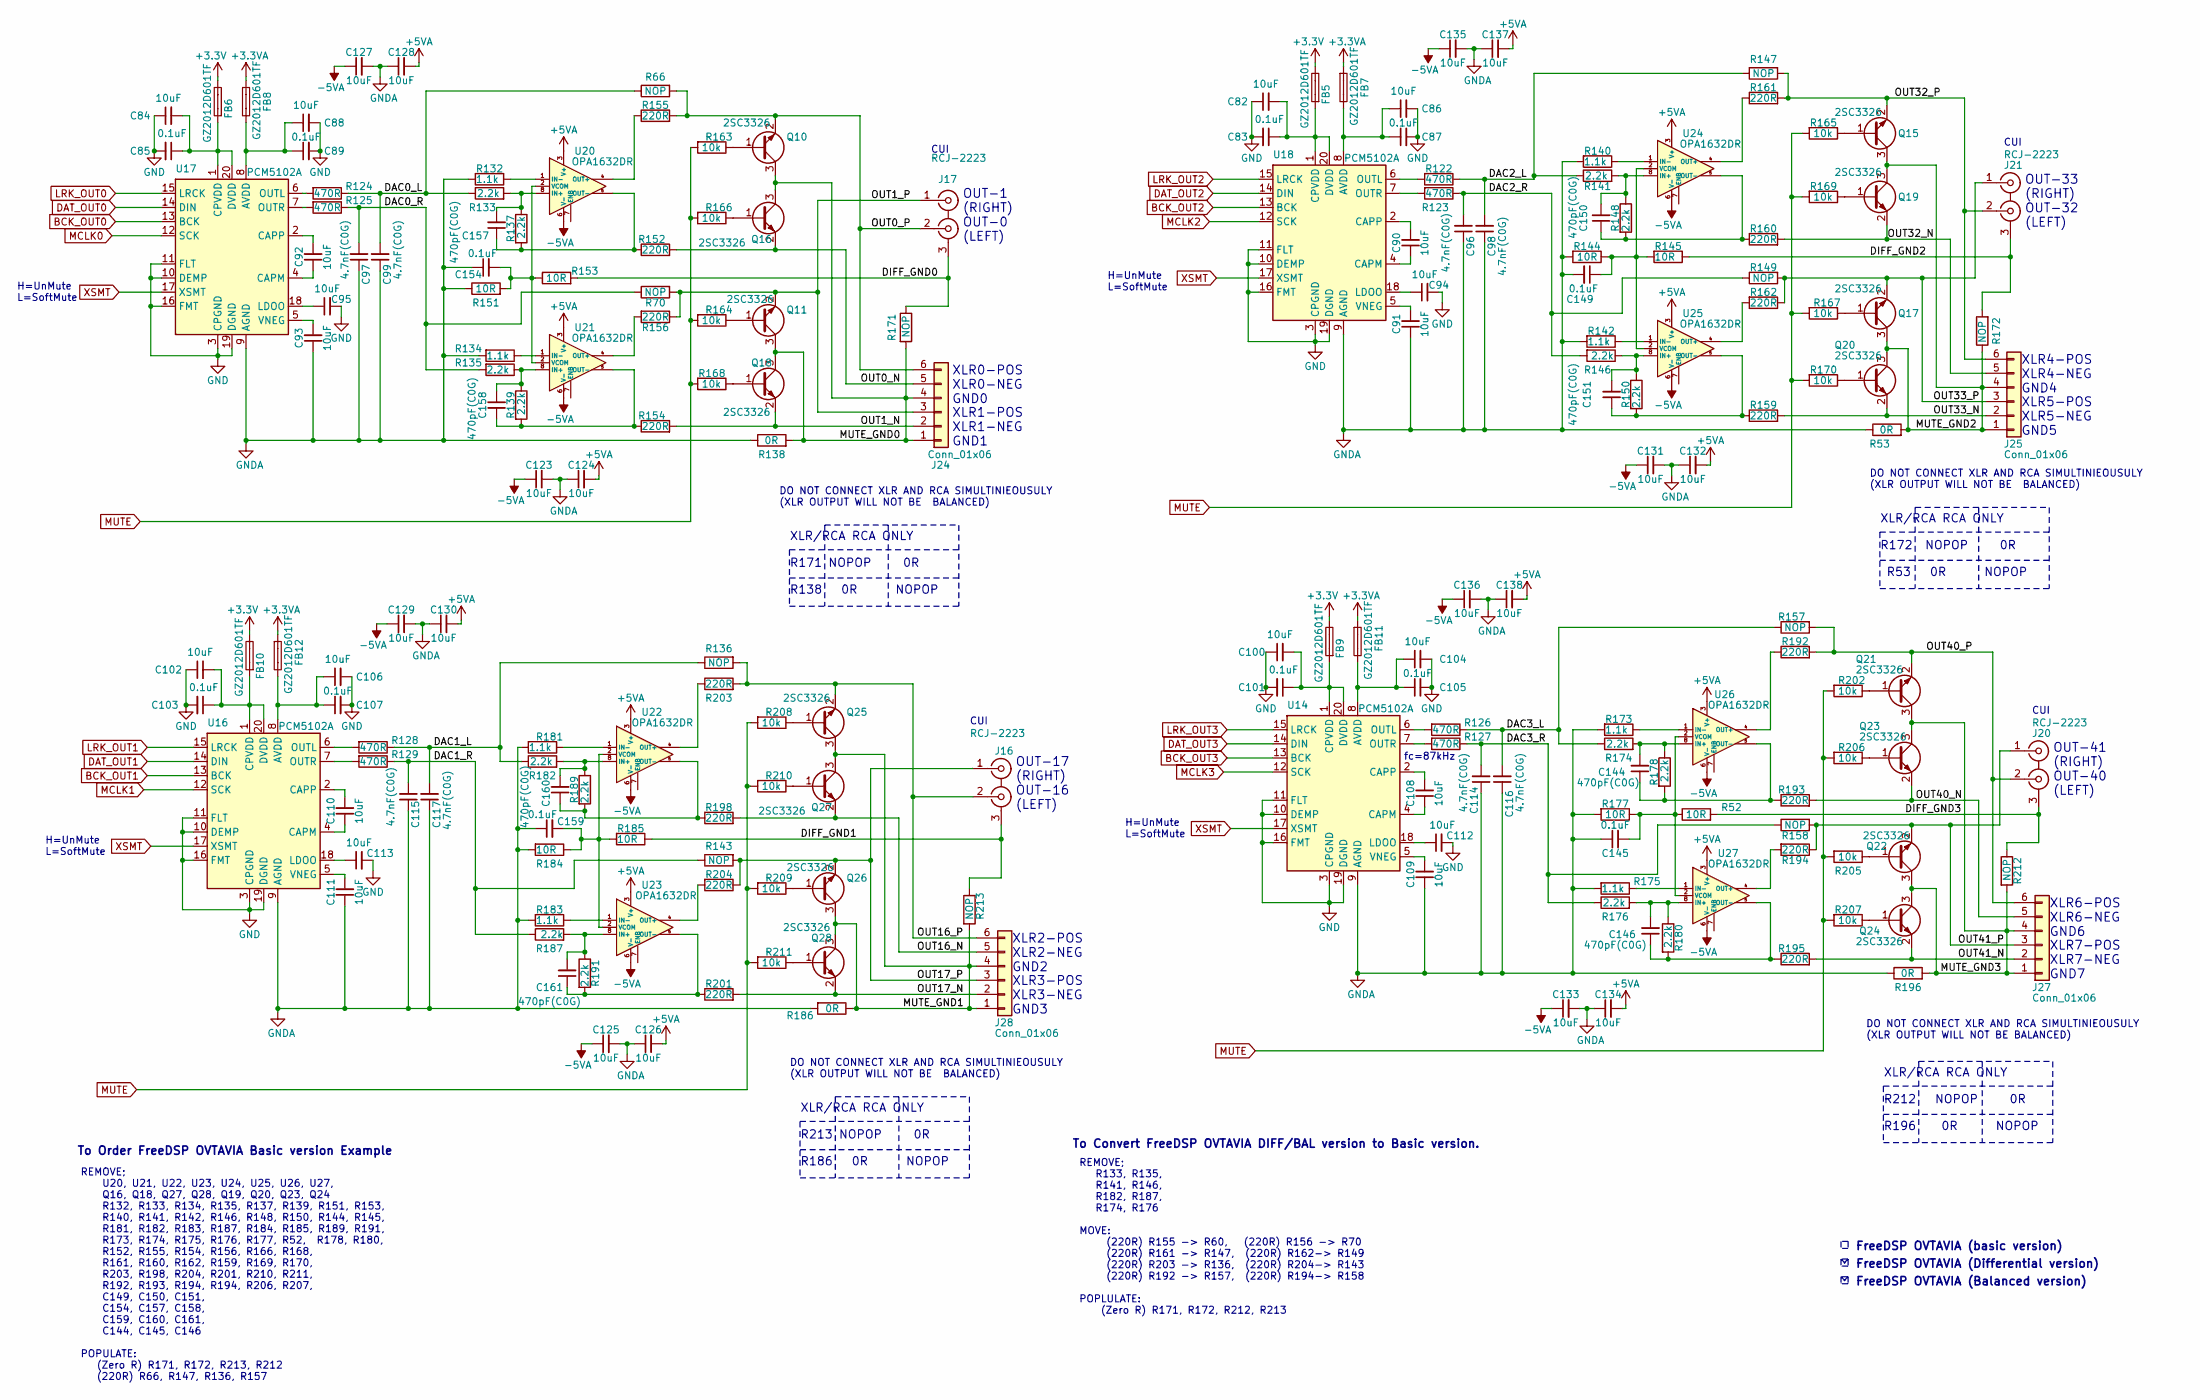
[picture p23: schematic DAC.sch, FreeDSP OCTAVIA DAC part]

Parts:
C82, C84, C86, C88, C102, C104, C106: 10uF; C_0805_2012Metric_Pad1.18x1.45mm_HandSolder
C83, C85, C87, C89, C103, C105, C107: 0.1uF; C_0805_2012Metric_Pad1.18x1.45mm_HandSolder
C90, C91, C92, C93, C94, C95, C108, C109, C110, C111, C112, C113, C123, C124, C125, C126, C127, C128, C129, C130, C131, C132, C133, C134, C135, C136, C137, C138: 10uF; C_0603_1608Metric
C96, C97, C98, C99, C114, C115, C116, C117: 4.7nF(C0G); C_0805_2012Metric_Pad1.18x1.45mm_HandSolder
C100: 10uF; C_0805_2012Metric
C101: 0.1uF; C_0805_2012Metric
C144, C146, C150, C151, C157, C158, C160, C161: 470pF(C0G); C_0805_2012Metric_Pad1.18x1.45mm_HandSolder
C145, C149, C154, C159: 0.1uF; C_0603_1608Metric
FB5, FB6, FB7, FB8, FB9, FB10, FB11, FB12: GZ2012D601TF; L_0805_2012Metric_Pad1.15x1.40mm_HandSolder
J16, J17, J20, J21: RCJ-2223
J24, J25, J27, J28: Conn_01x06; PinHeader_1x06_P2.54mm_Vertical
Q10, Q11, Q15, Q16, Q17, Q18, Q19, Q20, Q21, Q22, Q23, Q24, Q25, Q26, Q27, Q28: 2SC3326; SOT-23
R52, R144, R145, R151, R153, R177, R184, R185: 10R; R_0603_1608Metric
R53, R138, R186, R196: 0R; R_0603_1608Metric
R66, R70, R136, R143, R147, R149, R157, R158: NOP; R_0603_HandSoldering
R122, R123, R124, R125, R126, R127, R128, R129: 470R; R_0603_1608Metric
R132, R134, R140, R142, R173, R175, R181, R183: 1.1k; R_0603_1608Metric
R133, R135, R137, R139, R141, R146, R148, R150, R174, R176, R178, R180, R182, R187, R189, R191: 2.2k; R_0603_1608Metric
R152, R154, R155, R156, R159, R160, R161, R162, R192, R193, R194, R195, R198, R201, R203, R204: 220R; R_0603_1608Metric
R163, R164, R165, R166, R167, R168, R169, R170, R202, R205, R206, R207, R208, R209, R210, R211: 10k; R_0603_1608Metric
R171, R172, R212, R213: NOP; R_0603_1608Metric_Pad0.98x0.95mm_HandSolder
U14, U16, U17, U18: PCM5102A; TSSOP-20_4.4x6.5mm_P0.65mm
U20, U21, U22, U23, U24, U25, U26, U27: OPA1632DR; SOIC127P600X175-8N

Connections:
+3.3VA: FB7.1, FB8.1, FB11.1, FB12.1; also elsewhere on the board
+3V3: FB5.2, FB6.2, FB9.2, FB10.2; also elsewhere on the board
+5VA: C124.2, C126.2, C128.2, C130.2, C132.2, C134.2, C137.2, C138.2, U20.3 (V+), U21.3 (V+), U22.3 (V+), U23.3 (V+), U24.3 (V+), U25.3 (V+), U26.3 (V+), U27.3 (V+); also elsewhere on the board
-5VA: C123.1, C125.1, C127.1, C129.1, C131.1, C133.1, C135.1, C136.1, U20.6 (V-), U21.6 (V-), U22.6 (V-), U23.6 (V-), U24.6 (V-), U25.6 (V-), U26.6 (V-), U27.6 (V-); also elsewhere on the board
/ADC_IO Part/DAC/DAC0_L: C99.2, R66.1, R124.1, R133.1
/ADC_IO Part/DAC/DAC0_R: C97.2, R70.1, R125.1, R135.2
/ADC_IO Part/DAC/DAC1_L: C117.2, R128.1, R136.1, R182.1
/ADC_IO Part/DAC/DAC1_R: C115.2, R129.1, R143.1, R187.1
/ADC_IO Part/DAC/DAC2_L: C98.2, R122.1, R141.1, R147.1
/ADC_IO Part/DAC/DAC2_R: C96.2, R123.1, R146.2, R149.1
/ADC_IO Part/DAC/DAC3_L: C116.2, R126.1, R157.1, R174.1
/ADC_IO Part/DAC/DAC3_R: C114.2, R127.1, R158.1, R176.1
/ADC_IO Part/DAC/DIFF_GND0: J17.3 (EXT), R153.2, R171.1
/ADC_IO Part/DAC/DIFF_GND1: J16.3 (EXT), R185.1, R213.1
/ADC_IO Part/DAC/DIFF_GND2: J21.3 (EXT), R145.1, R172.2
/ADC_IO Part/DAC/DIFF_GND3: J20.3 (EXT), R52.2, R212.1
/ADC_IO Part/DAC/MUTE_GND0: J24.1, J24.4, Q10.3 (C), Q11.3 (C), Q16.3 (C), Q18.3 (C), R138.2, R171.2
/ADC_IO Part/DAC/MUTE_GND1: J28.1, J28.4, Q25.3 (C), Q26.3 (C), Q27.3 (C), Q28.3 (C), R186.1, R213.2
/ADC_IO Part/DAC/MUTE_GND2: J25.1, J25.4, Q15.3 (C), Q17.3 (C), Q19.3 (C), Q20.3 (C), R53.2, R172.1
/ADC_IO Part/DAC/MUTE_GND3: J27.1, J27.4, Q21.3 (C), Q22.3 (C), Q23.3 (C), Q24.3 (C), R196.2, R212.2
/ADC_IO Part/DAC/OUT0_N: J24.5, Q16.2 (E), R152.2
/ADC_IO Part/DAC/OUT0_P: J17.2 (IN2), J24.6, Q10.2 (E), R66.2, R155.2
/ADC_IO Part/DAC/OUT1_N: J24.2, Q18.2 (E), R154.2
/ADC_IO Part/DAC/OUT1_P: J17.1 (IN1), J24.3, Q11.2 (E), R70.2, R156.1
/ADC_IO Part/DAC/OUT16_N: J28.5, Q27.2 (E), R198.2
/ADC_IO Part/DAC/OUT16_P: J16.2 (IN2), J28.6, Q25.2 (E), R136.2, R203.2
/ADC_IO Part/DAC/OUT17_N: J28.2, Q28.2 (E), R201.2
/ADC_IO Part/DAC/OUT17_P: J16.1 (IN1), J28.3, Q26.2 (E), R143.2, R204.1
/ADC_IO Part/DAC/OUT32_N: J25.5, Q19.2 (E), R160.2
/ADC_IO Part/DAC/OUT32_P: J21.2 (IN2), J25.6, Q15.2 (E), R147.2, R161.2
/ADC_IO Part/DAC/OUT33_N: J25.2, Q20.2 (E), R159.2
/ADC_IO Part/DAC/OUT33_P: J21.1 (IN1), J25.3, Q17.2 (E), R149.2, R162.1
/ADC_IO Part/DAC/OUT40_N: J27.5, Q23.2 (E), R193.2
/ADC_IO Part/DAC/OUT40_P: J20.2 (IN2), J27.6, Q21.2 (E), R157.2, R192.2
/ADC_IO Part/DAC/OUT41_N: J27.2, Q24.2 (E), R195.2
/ADC_IO Part/DAC/OUT41_P: J20.1 (IN1), J27.3, Q22.2 (E), R158.2, R194.1
BCK_OUT0: U17.13 (BCK); also elsewhere on the board
BCK_OUT1: U16.13 (BCK); also elsewhere on the board
BCK_OUT2: U18.13 (BCK); also elsewhere on the board
BCK_OUT3: U14.13 (BCK); also elsewhere on the board
DAT_OUT0: U17.14 (DIN); also elsewhere on the board
DAT_OUT1: U16.14 (DIN); also elsewhere on the board
DAT_OUT2: U18.14 (DIN); also elsewhere on the board
DAT_OUT3: U14.14 (DIN); also elsewhere on the board
GND: C82.1, C83.2, C84.1, C85.2, C86.2, C87.2, C88.2, C89.2, C94.2, C95.2, C100.1, C101.2, C102.1, C103.2, C104.2, C105.2, C106.2, C107.2, C112.2, C113.2, U14.3 (CPGND), U14.10 (DEMP), U14.11 (FLT), U14.16 (FMT), U14.19 (DGND), U16.3 (CPGND), U16.10 (DEMP), U16.11 (FLT), U16.16 (FMT), U16.19 (DGND), U17.3 (CPGND), U17.10 (DEMP), U17.11 (FLT), U17.16 (FMT), U17.19 (DGND), U18.3 (CPGND), U18.10 (DEMP), U18.11 (FLT), U18.16 (FMT), U18.19 (DGND); also elsewhere on the board
GNDA: C91.1, C93.1, C96.1, C97.1, C98.1, C99.1, C109.1, C111.1, C114.1, C115.1, C116.1, C117.1, C123.2, C124.1, C125.2, C126.1, C127.2, C128.1, C129.2, C130.1, C131.2, C132.1, C133.2, C134.1, C135.2, C136.2, C137.1, C138.1, C145.1, C149.2, C154.1, C159.1, R53.1, R132.2, R134.2, R138.1, R140.2, R142.2, R144.2, R151.1, R173.2, R175.2, R177.2, R181.2, R183.2, R184.2, R186.2, R196.1, U14.9 (AGND), U16.9 (AGND), U17.9 (AGND), U18.9 (AGND); also elsewhere on the board
LRK_OUT0: U17.15 (LRCK); also elsewhere on the board
LRK_OUT1: U16.15 (LRCK); also elsewhere on the board
LRK_OUT2: U18.15 (LRCK); also elsewhere on the board
LRK_OUT3: U14.15 (LRCK); also elsewhere on the board
MCLK0: U17.12 (SCK); also elsewhere on the board
MCLK1: U16.12 (SCK); also elsewhere on the board
MCLK2: U18.12 (SCK); also elsewhere on the board
MCLK3: U14.12 (SCK); also elsewhere on the board
MUTE: R163.2, R164.2, R165.2, R166.2, R167.2, R168.2, R169.2, R170.2, R202.2, R205.2, R206.2, R207.2, R208.2, R209.2, R210.2, R211.2; also elsewhere on the board
unnamed: C82.2, C83.1, FB5.1, U18.1 (CPVDD), U18.20 (DVDD)
unnamed: C84.2, C85.1, FB6.1, U17.1 (CPVDD), U17.20 (DVDD)
unnamed: C86.1, C87.1, FB7.2, U18.8 (AVDD)
unnamed: C88.1, C89.1, FB8.2, U17.8 (AVDD)
unnamed: C90.1, U18.4 (CAPM)
unnamed: C90.2, U18.2 (CAPP)
unnamed: C91.2, U18.5 (VNEG)
unnamed: C92.1, U17.4 (CAPM)
unnamed: C92.2, U17.2 (CAPP)
unnamed: C93.2, U17.5 (VNEG)
unnamed: C94.1, U18.18 (LDOO)
unnamed: C95.1, U17.18 (LDOO)
unnamed: C100.2, C101.1, FB9.1, U14.1 (CPVDD), U14.20 (DVDD)
unnamed: C102.2, C103.1, FB10.1, U16.1 (CPVDD), U16.20 (DVDD)
unnamed: C104.1, C105.1, FB11.2, U14.8 (AVDD)
unnamed: C106.1, C107.1, FB12.2, U16.8 (AVDD)
unnamed: C108.1, U14.4 (CAPM)
unnamed: C108.2, U14.2 (CAPP)
unnamed: C109.2, U14.5 (VNEG)
unnamed: C110.1, U16.4 (CAPM)
unnamed: C110.2, U16.2 (CAPP)
unnamed: C111.2, U16.5 (VNEG)
unnamed: C112.1, U14.18 (LDOO)
unnamed: C113.1, U16.18 (LDOO)
unnamed: C144.1, R178.2, R193.1, U26.5 (OUT-)
unnamed: C144.2, R174.2, R178.1, U26.8 (IN+)
unnamed: C145.2, R52.1, R177.1, U26.2 (VCOM), U27.2 (VCOM)
unnamed: C146.1, R180.2, R195.1, U27.5 (OUT-)
unnamed: C146.2, R176.2, R180.1, U27.8 (IN+)
unnamed: C149.1, R144.1, R145.2, U24.2 (VCOM), U25.2 (VCOM)
unnamed: C150.1, R148.2, R160.1, U24.5 (OUT-)
unnamed: C150.2, R141.2, R148.1, U24.8 (IN+)
unnamed: C151.1, R150.2, R159.1, U25.5 (OUT-)
unnamed: C151.2, R146.1, R150.1, U25.8 (IN+)
unnamed: C154.2, R151.2, R153.1, U20.2 (VCOM), U21.2 (VCOM)
unnamed: C157.1, R137.2, R152.1, U20.5 (OUT-)
unnamed: C157.2, R133.2, R137.1, U20.8 (IN+)
unnamed: C158.1, R139.2, R154.1, U21.5 (OUT-)
unnamed: C158.2, R135.1, R139.1, U21.8 (IN+)
unnamed: C159.2, R184.1, R185.2, U22.2 (VCOM), U23.2 (VCOM)
unnamed: C160.1, R189.2, R198.1, U22.5 (OUT-)
unnamed: C160.2, R182.2, R189.1, U22.8 (IN+)
unnamed: C161.1, R191.2, R201.1, U23.5 (OUT-)
unnamed: C161.2, R187.2, R191.1, U23.8 (IN+)
unnamed: Q10.1 (B), R163.1
unnamed: Q11.1 (B), R164.1
unnamed: Q15.1 (B), R165.1
unnamed: Q16.1 (B), R166.1
unnamed: Q17.1 (B), R167.1
unnamed: Q18.1 (B), R168.1
unnamed: Q19.1 (B), R169.1
unnamed: Q20.1 (B), R170.1
unnamed: Q21.1 (B), R202.1
unnamed: Q22.1 (B), R205.1
unnamed: Q23.1 (B), R206.1
unnamed: Q24.1 (B), R207.1
unnamed: Q25.1 (B), R208.1
unnamed: Q26.1 (B), R209.1
unnamed: Q27.1 (B), R210.1
unnamed: Q28.1 (B), R211.1
unnamed: R122.2, U18.6 (OUTL)
unnamed: R123.2, U18.7 (OUTR)
unnamed: R124.2, U17.6 (OUTL)
unnamed: R125.2, U17.7 (OUTR)
unnamed: R126.2, U14.6 (OUTL)
unnamed: R127.2, U14.7 (OUTR)
unnamed: R128.2, U16.6 (OUTL)
unnamed: R129.2, U16.7 (OUTR)
unnamed: R132.1, U20.1 (IN-)
unnamed: R134.1, U21.1 (IN-)
unnamed: R140.1, U24.1 (IN-)
unnamed: R142.1, U25.1 (IN-)
unnamed: R155.1, U20.4 (OUT+)
unnamed: R156.2, U21.4 (OUT+)
unnamed: R161.1, U24.4 (OUT+)
unnamed: R162.2, U25.4 (OUT+)
unnamed: R173.1, U26.1 (IN-)
unnamed: R175.1, U27.1 (IN-)
unnamed: R181.1, U22.1 (IN-)
unnamed: R183.1, U23.1 (IN-)
unnamed: R192.1, U26.4 (OUT+)
unnamed: R194.2, U27.4 (OUT+)
unnamed: R203.1, U22.4 (OUT+)
unnamed: R204.2, U23.4 (OUT+)
XSMT: U14.17 (XSMT), U16.17 (XSMT), U17.17 (XSMT), U18.17 (XSMT); also elsewhere on the board

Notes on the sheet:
FreeDSP OVTAVIA (basic version)
FreeDSP OVTAVIA (Differential version)
XLR6-POS XLR6-NEG GND6
XLR2-POS XLR2-NEG GND2
XLR5-POS XLR5-NEG GND5
XLR7-POS XLR7-NEG GND7
XLR3-POS XLR3-NEG GND3
XLR1-POS XLR1-NEG GND1
XLR4-POS XLR4-NEG GND4
XLR0-POS XLR0-NEG GND0
OUT-33 (RIGHT) OUT-32 (LEFT)
OUT-41 (RIGHT) OUT-40 (LEFT)
OUT-17 (RIGHT) OUT-16 (LEFT)
To Order FreeDSP OVTAVIA Basic version Example
XLR/RCA RCA ONLY R212 NOPOP 0R R196 0R NOPOP
REMOVE; U20, U21, U22, U23, U24, U25, U26, U27, Q16, Q18, Q27, Q28, Q19, Q20, Q23, Q24 R132, R133, R134, R135, R137, R139, R151, R153, R140, R141, R142, R146, R148, R150, R144, R145, R181, R182, R183, R187, R184, R185, R189, R191, R173, R174, R175, R176, R177, R52, R178, R180, R152, R155, R154, R15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
H=UnMute L=SoftMute
FreeDSP OVTAVIA (Balanced version)
DO NOT CONNECT XLR AND RCA SIMULTINIEOUSULY (XLR OUTPUT WILL NOT BE BALANCED)
DO NOT CONNECT XLR AND RCA SIMULTINIEOUSULY (XLR OUTPUT WILL NOT BE BALANCED)
OUT-1 (RIGHT) OUT-0 (LEFT)
XLR/RCA RCA ONLY R171 NOPOP 0R R138 0R NOPOP
XLR/RCA RCA ONLY R213 NOPOP 0R R186 0R NOPOP
XLR/RCA RCA ONLY R172 NOPOP 0R R53 0R NOPOP
fc=87kHz
CUI
To Convert FreeDSP OVTAVIA DIFF/BAL version to Basic version.
REMOVE; R133, R135, R141, R146, R182, R187, R174, R176 MOVE: (220R) R155 -> R60, (220R) R156 -> R70 (220R) R161 -> R147, (220R) R162-> R149 (220R) R203 -> R136, (220R) R204-> R143 (220R) R192 -> R157, (220R) R194-> R158 POPLULATE: (Zero R) R171, R172, R212, R213

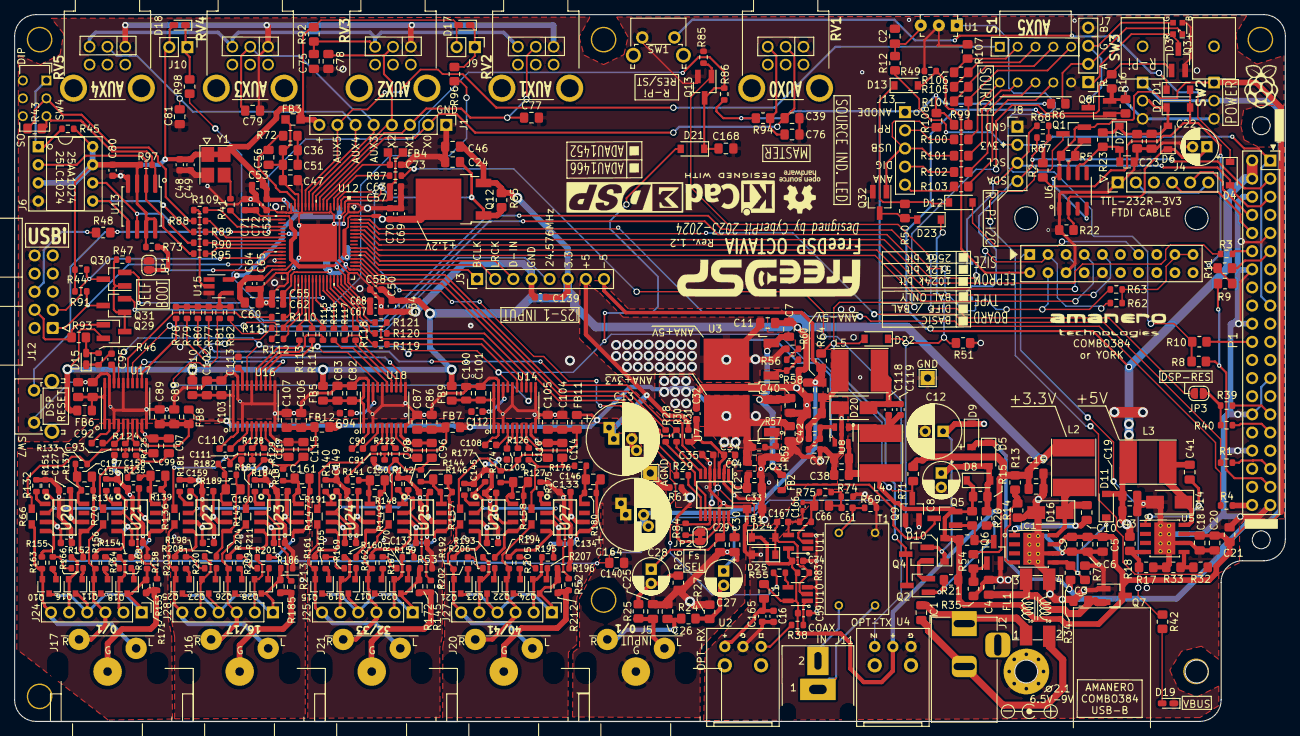
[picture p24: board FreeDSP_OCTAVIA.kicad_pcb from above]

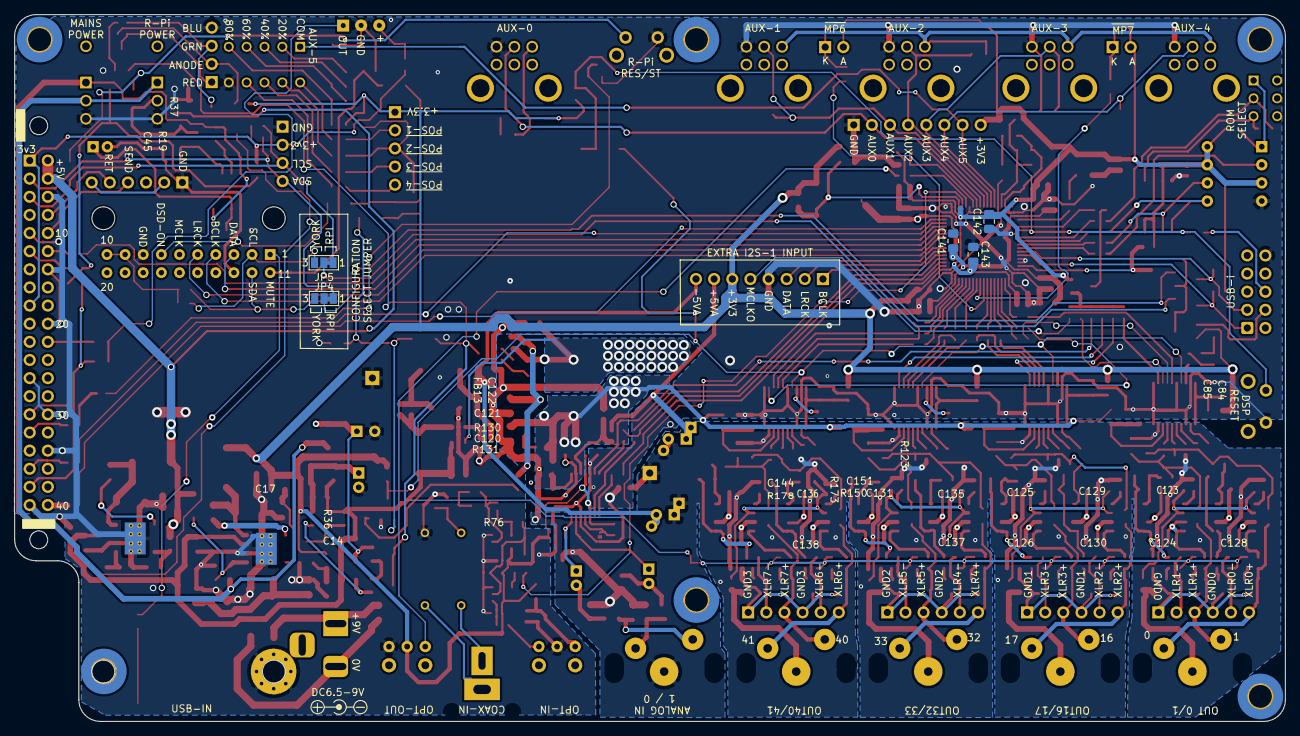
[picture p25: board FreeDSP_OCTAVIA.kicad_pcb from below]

Board: 4 copper layers, 178.0 x 99.0 mm, 525 parts (15 on the bottom side), 314 nets.

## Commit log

2023-03-14 Initial Prototype Version0.1
    [ADC_IO.sch, DAC.sch, DAC_Config_Example.sch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]
2023-04-07 Updated version0.2
    [FreeDSP_OCTAVIA_BOM1.xlsx]
2023-04-15 Updated description about SPI EEPROM.
    [FreeDSP_OCTAVIA_0v2_BOM-LIST.xlsx]
2023-04-15 version 0.2 updates
    [ADC_IO.sch]
2023-04-18 Add files via upload
    Raspberry-Pi Power Control Demo
2023-04-19 Fixed missing SMD Beads
    [FreeDSP_OCTAVIA_CPL1.xlsx]
2023-04-19 Actual Board Picture
2023-04-22 Count on J5 in hand-mount BOM list.
    [FreeDSP_OCTAVIA_0v2_BOM-LIST.xlsx]
2023-04-24 Workaround photos
    Offset mounted C13、Removed D13, Reversed D21
2023-04-26 ADC,USB,RPI works SPDIF is not yet,
2023-04-29 3way Crossover Example Schematic
2023-04-30 SPDIF I/F Schematic
2023-04-30 SPDIF I/F part schematic
2023-05-01 D13 placement, R76 value changed, D21 removed
    [FreeDSP_OCTAVIA_BOM1.xlsx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]
2023-05-06 Design the Original Chassis
2023-05-07 R7 R33 Value Changed
    [FreeDSP_OCTAVIA_0v2_BOM-LIST.xlsx]
2023-05-07 R33, R7 Changed
    [FreeDSP_OCTAVIA_BOM1.xlsx]
2023-05-08 Updated to Wide Supply Voltage Version
2023-05-13 Issue Fixed, Header Added, Heatspreader Added
    [FreeDSP_OCTAVIA_BOM1.xlsx, FreeDSP_OCTAVIA_BOM1old.xlsx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]
2023-05-13 Version0.2 Board. Reviced PCB design.
    [ADC_IO.sch, DAC.sch, FreeDSP_OCTAVIA.csv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]
2023-05-13 Updated PCB design. Issue fixed.
2023-05-14 Physical Board Information
2023-05-14 Adjusted to actual sizes
    [OCTAVIA_CNC-Panel_Design.DXF]
2023-05-17 More sample project uploaaaded
2023-05-20 Power Status Indicator LED moved
    [OCTAVIA_CNC-Panel_Design.DXF]
2023-05-24 Fixed wrong L/R Connection of RCA Jack
    [ADC_IO.sch, DAC.sch, FreeDSP_OCTAVIA.sch]
2023-07-22 Second Trial Version
    [FreeDSP_OCTAVIA_BOM1.xlsx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]
2023-07-22 Enhanced Release Version (4 Layer PCB Design)
    [FreeDSP_OCTAVIA_BOM1.xlsx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]
2023-07-22 2nd Trial Version (2 Layer PCB)
2023-07-22 The last 2 Layer PCB Design version
2023-07-22 New Output Driver with Enhanced 4 Layer PCB
    [ADC_IO.sch, DAC.sch, FreeDSP_OCTAVIA.kicad_pcb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]
2023-07-22 New Output Driver with 4 Layer PCB ver0.30 Archive
2023-07-22 New Output Driver with 4 Layer PCB
2023-07-25 Fixed USB Position of Source Selector Switch
    Version 0.30 (CCW) USB - RPi - DIG -ANA (CW)
    Version 0.31 (CCW) RPi - USB - DIG -ANA (CW)
    [FreeDSP_OCTAVIA.sch]
2023-07-25 Fixed USB Position of Source Selector Switch
    Fixed USB Position of Source Selector Switch
    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
2023-07-25 FIxed USB position of Source Selector
    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
2023-08-15 Improved Coax Input Noise Immunities
    [FreeDSP_OCTAVIA_BOM_1.xlsx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]
2023-08-15 Improved Coax Input Noise Immunities
    Changed Coax input amp design and AC couling to EXOR
    [ADC_IO.sch, DAC.sch, FreeDSP_OCTAVIA.csv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]
2023-08-15 Update ver 0.32 README.md
    The coaxial S/PDIF input circuit is updated, with no other changes.
2023-08-28 Voltage Regurator had Changed to LM317
    [FreeDSP_OCTAVIA_BOM_1.xlsx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]
2023-08-28 Voltage Regulator Changed to LM317
    PCB layout is also updated in some of the places.
    [ADC_IO.sch, DAC.sch, FreeDSP_OCTAVIA.kicad_pcb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]
2023-08-28 Version 0.33 Updated
    Only the change of Voltage Regulator.
2023-09-28 Just evaluation use only. (Do not build)
    [FreeDSP_OCTAVIA_0v33JBOM1.xlsx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]
2023-09-29 Only used for evaluation in Japan.
    [FreeDSP_OCTAVIA_0v33JF_BOM1.xlsx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]
2023-09-30 Released for everyone ready to build.
    [FreeDSP_OCTAVIA_1v00_BOM_1.xlsx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]
2023-09-30 Released for everyone, ready to build.
    [ADC_IO.sch, DAC.sch, FreeDSP_OCTAVIA.kicad_pcb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]
2023-10-07 Fixed R57, R59 value errors
    [FreeDSP_OCTAVIA_1v01_BOM_1.xlsx]
2023-11-28 Fixed ACM9070F Land Patterns.
    [FreeDSP_OCTAVIA_1v02_BOM_ALL.xlsx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]
2023-12-03 Delete SOURCES/kiCAD/FreeDSP_OCTAVIA_1v02_20231129.zip
    Found short connection issue.
2023-12-03 Delete SOURCES/kiCAD/JLPCB_Oder files (DIFF and BAL)/1v02 directory
    A short connection was found.
    Do not use this version 1.02
    [FreeDSP_OCTAVIA_1v02_BOM_ALL.xlsx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]
2023-12-03 Fixed ACM9070 lands. Selectable I2C for RPI/YORK
    [FreeDSP_OCTAVIA_1v1_BOM_1.xlsx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]
2024-01-02 A method of board type convertion had changed.
    No functions/features changed.
    [FreeDSP_OCTAVIA_1v2_BOM1.xlsx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]
2024-01-02 A method of board type convertion had changed.
    Add an AGND fill on the bottom layer. The connection path for the Standard type board had changed. No features/functions changed.
    [ADC_IO.sch, DAC.sch, FreeDSP_OCTAVIA.kicad_pcb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]
2024-01-02 A method of board type convertion had changed.
2024-09-21 Fixed AMANERO USB card size and mounting holes.
2025-04-30 Fixed LR8 Filter Curves(Fc50-500Hz, 120-12kHz)
2025-05-01 LR8 Crossover: Fixed AUX-ADC AM noise issue
